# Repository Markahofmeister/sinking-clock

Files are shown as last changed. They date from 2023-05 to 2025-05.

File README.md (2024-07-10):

<Desc.>

#### A full detailing can be found [here](www.markhofmeister.com/sinking-clock) 

## Directory Structure 

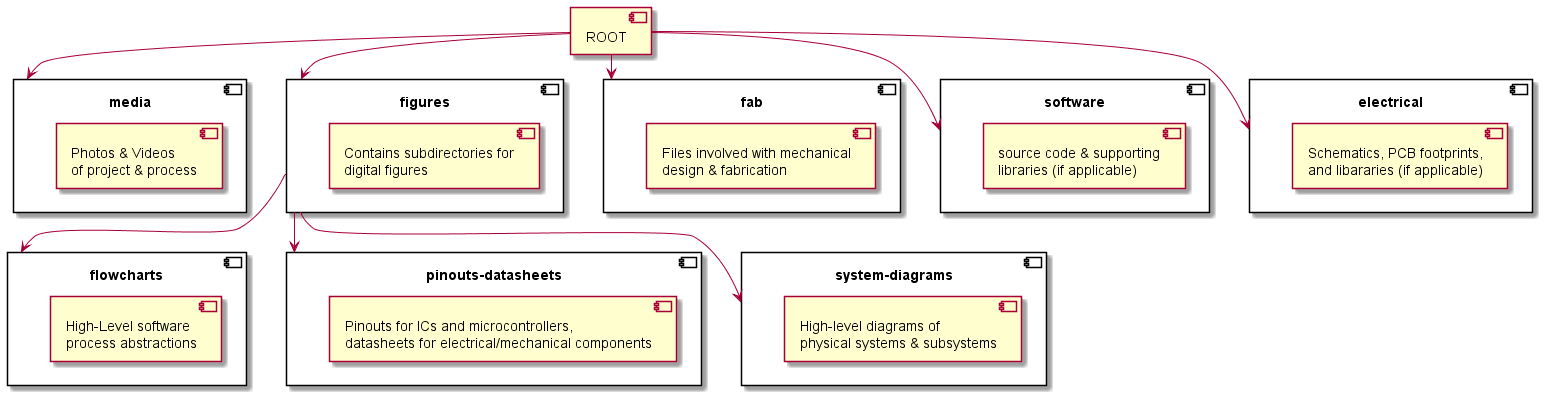
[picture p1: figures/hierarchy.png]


## System Diagram

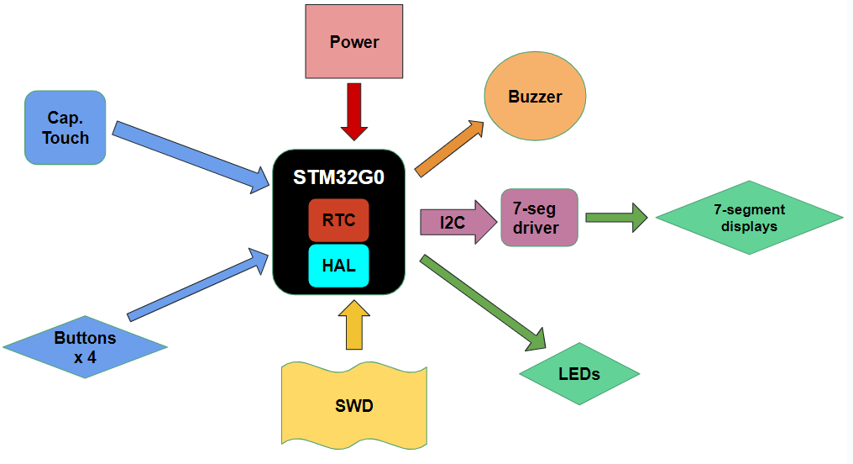
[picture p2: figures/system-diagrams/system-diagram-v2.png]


## Flowcharts
### Main Thread
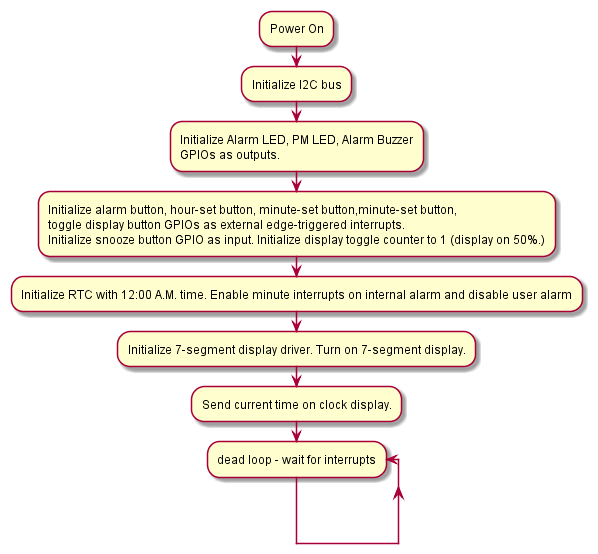
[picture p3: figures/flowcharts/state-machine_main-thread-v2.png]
 
### Interrupts
<!---
<a href="url"><img src="https://github.com/Markahofmeister/sinking-clock/figures/flowcharts/state-machine_RTC-interrupt-v1.png" width=50%></a>
-->
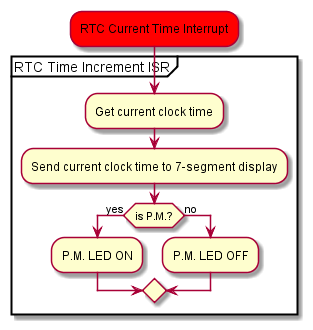
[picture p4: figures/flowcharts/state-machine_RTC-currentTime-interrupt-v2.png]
 
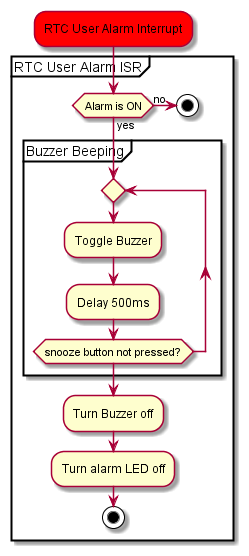
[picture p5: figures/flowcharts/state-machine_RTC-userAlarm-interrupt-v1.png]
 
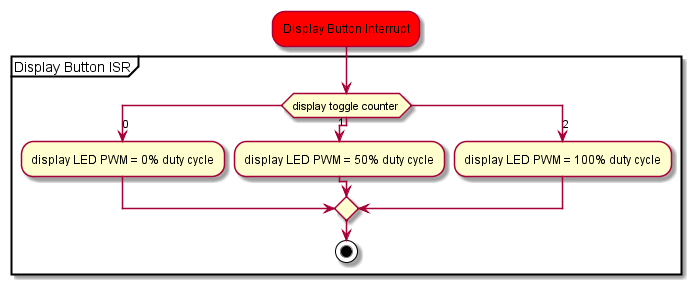
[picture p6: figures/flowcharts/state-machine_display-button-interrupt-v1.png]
 
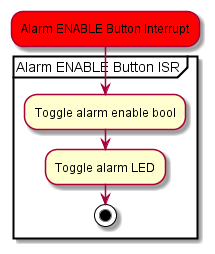
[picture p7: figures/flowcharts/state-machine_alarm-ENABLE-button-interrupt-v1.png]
 
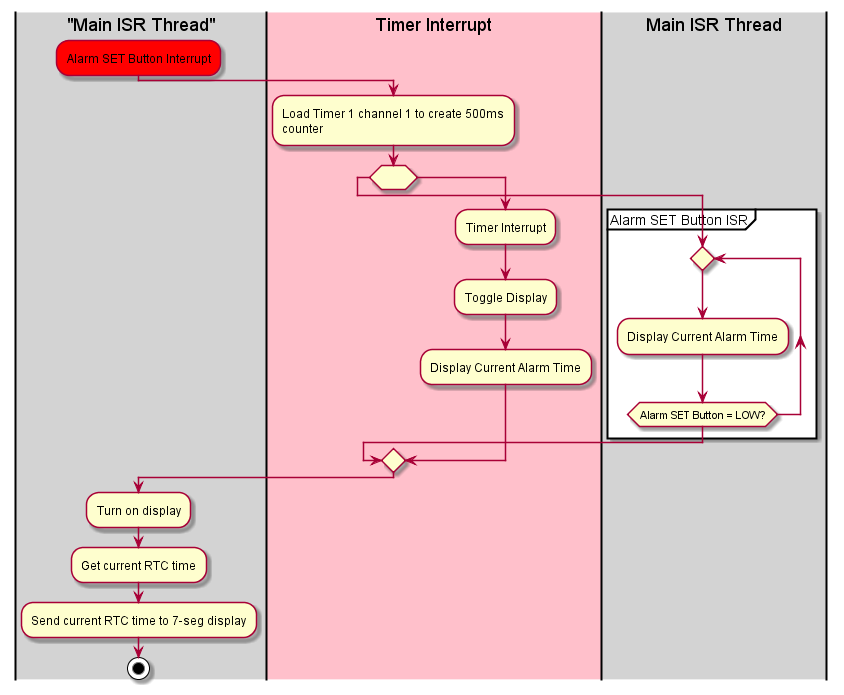
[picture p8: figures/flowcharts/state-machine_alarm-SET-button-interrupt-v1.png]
 
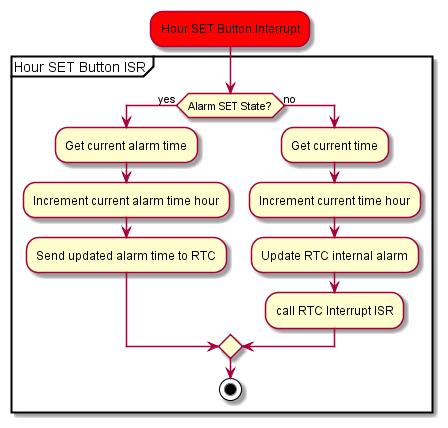
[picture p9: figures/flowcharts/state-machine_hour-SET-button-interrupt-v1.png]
 
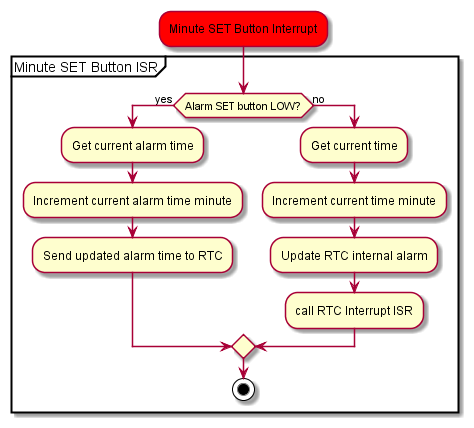
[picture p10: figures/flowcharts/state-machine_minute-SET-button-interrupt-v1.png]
 

## Exploded Mechanical View
	



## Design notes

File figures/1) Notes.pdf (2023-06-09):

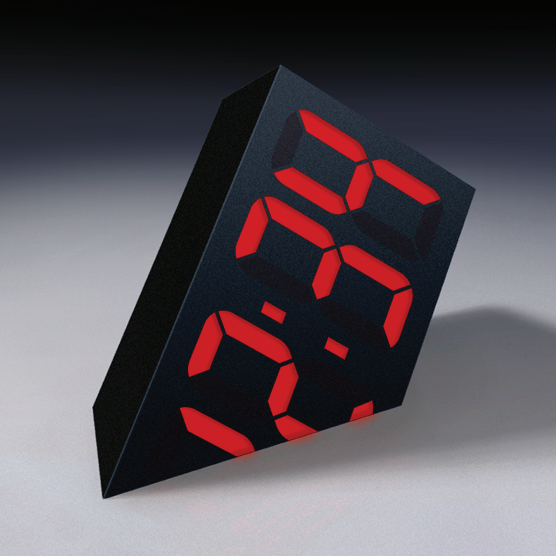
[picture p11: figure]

## SINKING CLOCK Notes

5/18/2023

This is a standard LCD digital alarm clock. The hour digits are severed, but enough is visible to read the time.

Interface
HI/LO/OFF
The LED display can be bright, dim, or o. If this clock sits next to your bed, it would be very irritating to have it on all night long. If set to OFF, the display would come on automatically when the alarm goes o. This is one button. Each time pressed, it cycles through each of these modes.
ALARM
Option 1: One button. Press to turn the alarm on, and o. Hold continuously when using the HOUR and MINUTE buttons to set the alarm time
Option 2: Two buttons. One for alarm on/o. The second button needs to be held down continuously when using the HOUR and MINUTE buttons.
An indicator light on the top of this clock is on when the alarm is activated
HOUR
Press to set the hour digits for the time, and the for the alarm when the alarm set button is held down. MINUTE
Press to set the Minute digits for the time, and the for the alarm when the alarm set button is held down.
SNOOZE
This is a touch sensor, or motion sensor on the top surface of this clock. This should only require a very lite touch to operate. Touch it once quickly to delay the alarm for 10 minutes. The alarm indicator light remains on. Touch it for 3 seconds or more to turn the alarm of. Then, the indicator light will turn o.

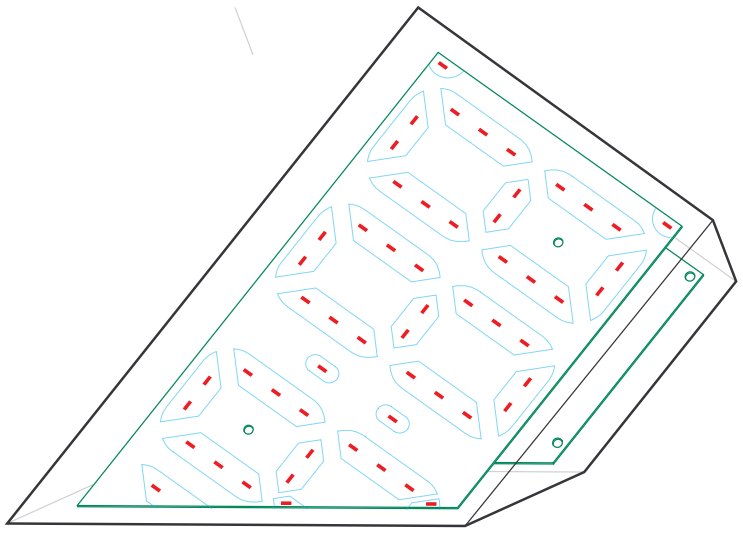
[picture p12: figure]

Power Source
External adapter connected to the backside with a barrel connector jack. This can easily be changed to a 120V or 240V unit depending on what country it will be used in.

Additional Thoughts / Issues
There should be a battery to keep the set time if the power is ever cut. I know this is easy to do, but would this be a battery that is continually charged by the power adapter, or is it a battery that would need to be replaced by the user after it naturally runs down over a few years? I would prefer that it is a battery that never needs replacement, so I don’t need to add a panel for the customer to remove to change batteries. Additionally, lithium batteries are the best, and the most common rechargeable battery, but these make shipping more dicult. There are many regulations and restrictions regarding anything with lithium batteries in it. This needs to be thought through. Some clocks have a wifi connection, so the time is automatically set. Good for the user, but I think this may have issues. The laws regarding any product with wifi is dierent in every country. Therefore, every product needs to be certified to be sold in that market. This would of course be very expensive. If I can not find a way around this, it is probably not realistic.

© K.K. Normal 2023

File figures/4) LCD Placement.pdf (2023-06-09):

## SINKING CLOCK PCB LCD Placement

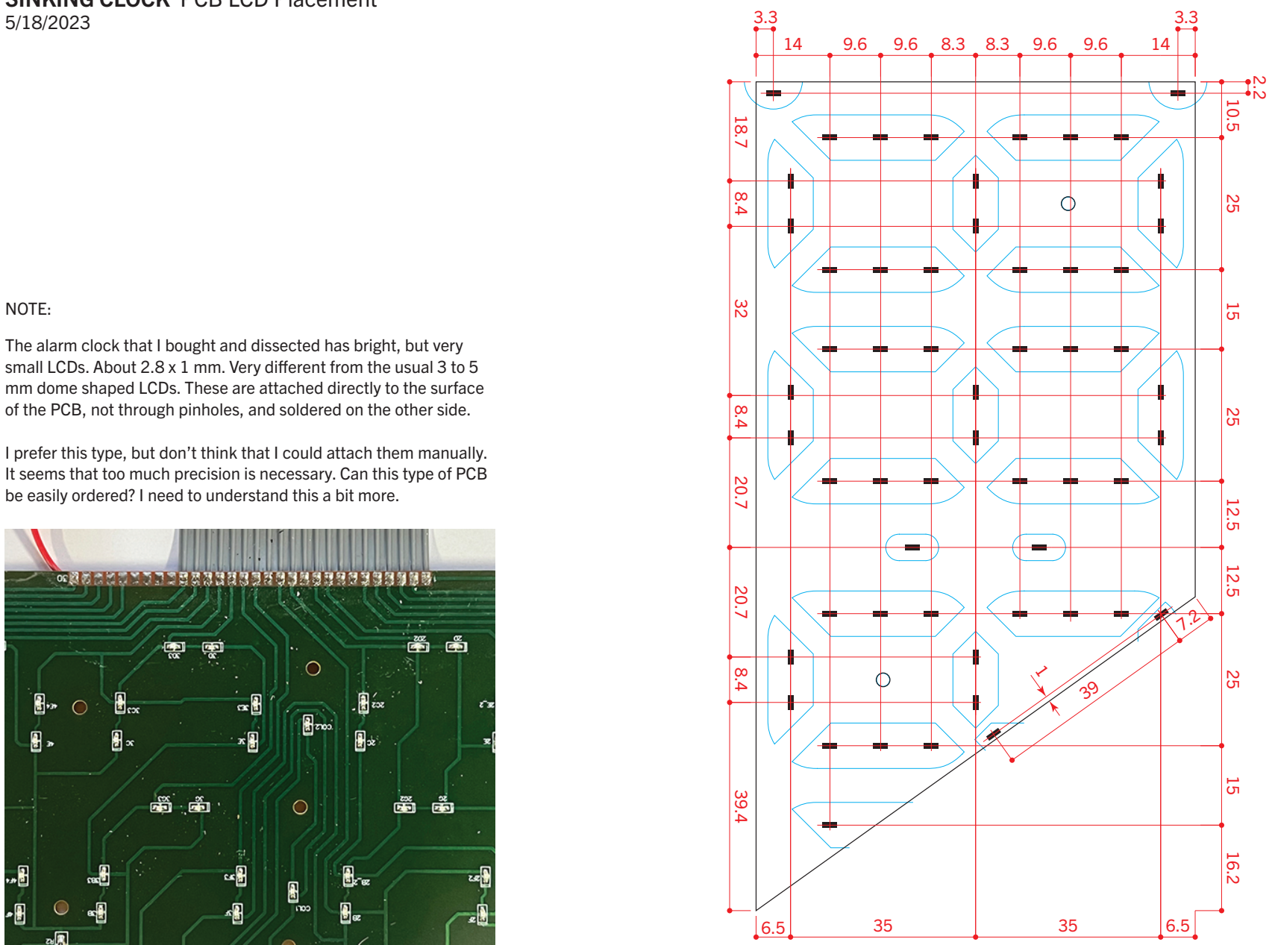
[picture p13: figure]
NOTE:

The alarm clock that I bought and dissected has bright, but very small LCDs. About 2.8 x 1 mm. Very dierent from the usual 3 to 5 mm dome shaped LCDs. These are attached directly to the surface of the PCB, not through pinholes, and soldered on the other side.

I prefer this type, but don’t think that I could attach them manually. It seems that too much precision is necessary. Can this type of PCB be easily ordered? I need to understand this a bit more.

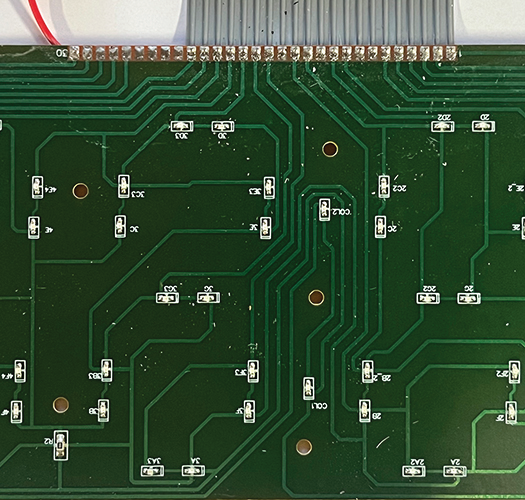
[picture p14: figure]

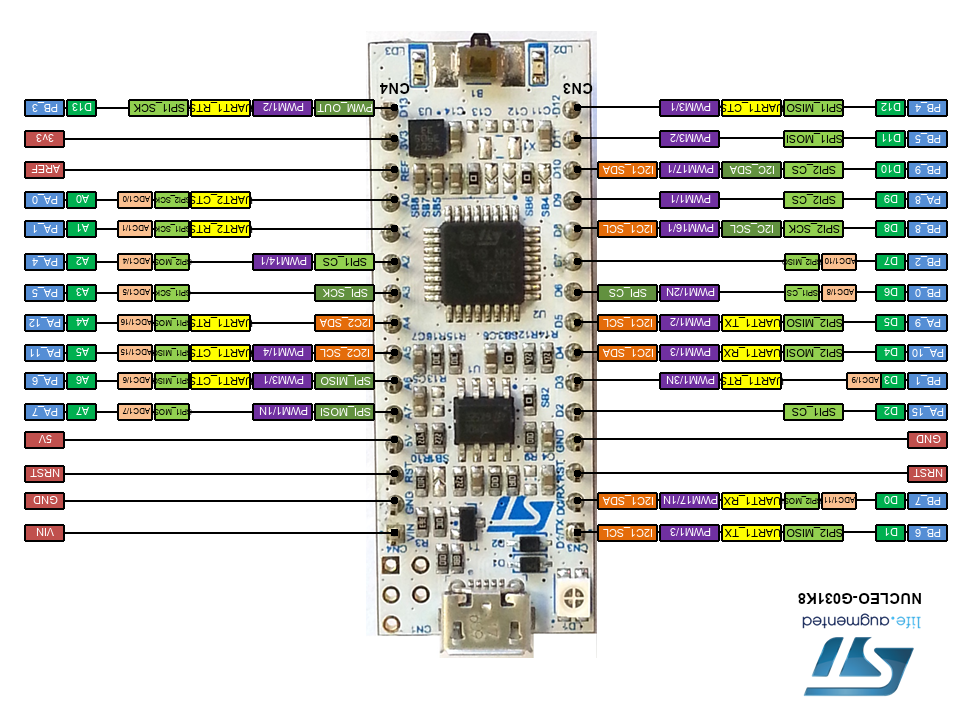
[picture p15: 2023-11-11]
figures/pinouts-datasheets/NUCELO-G032K8_pinout.png

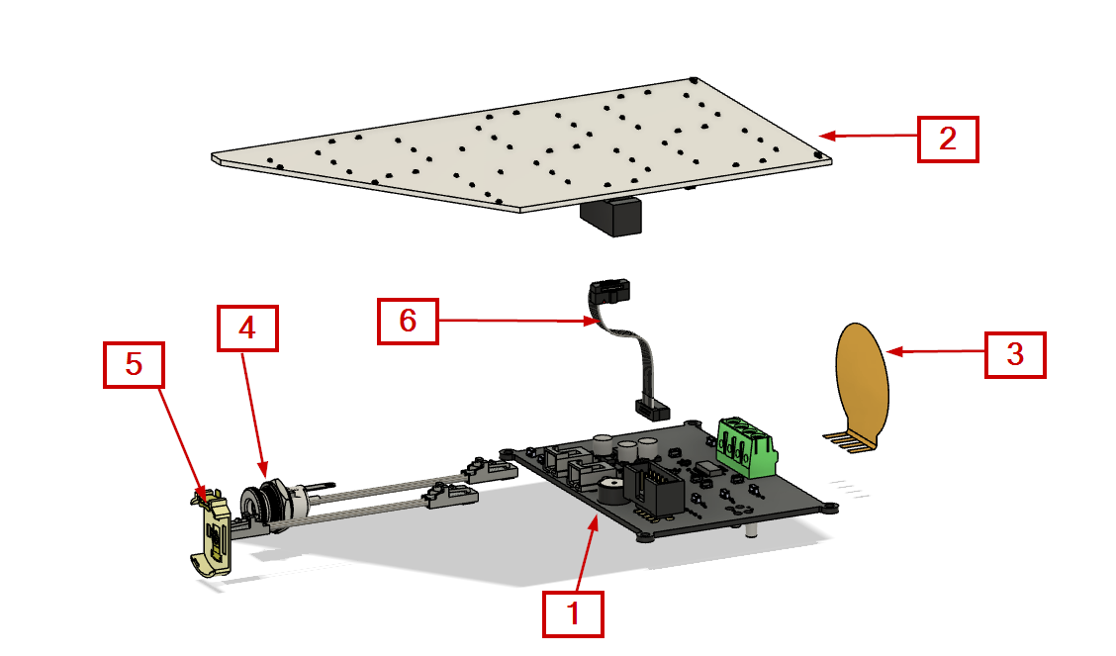
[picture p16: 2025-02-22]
figures/exploded-view.png

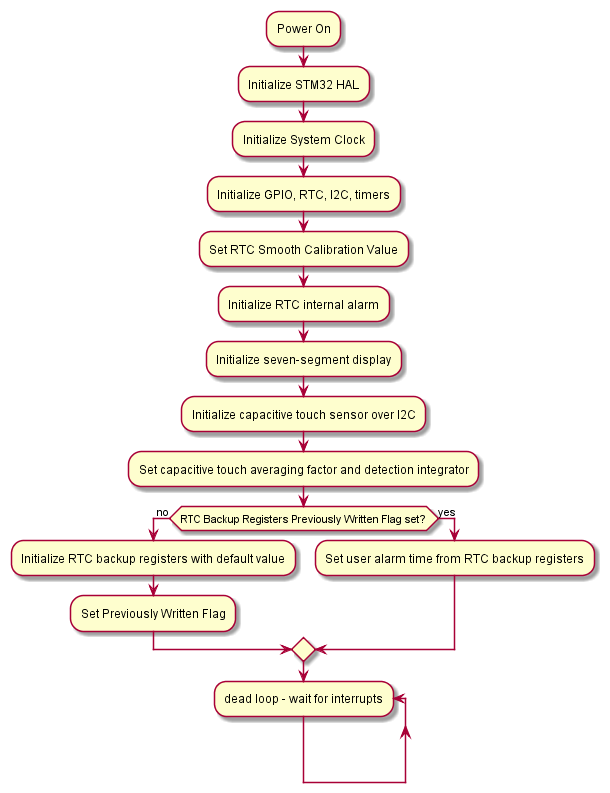
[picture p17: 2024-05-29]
figures/flowcharts/state-machine_main-thread-v3.png

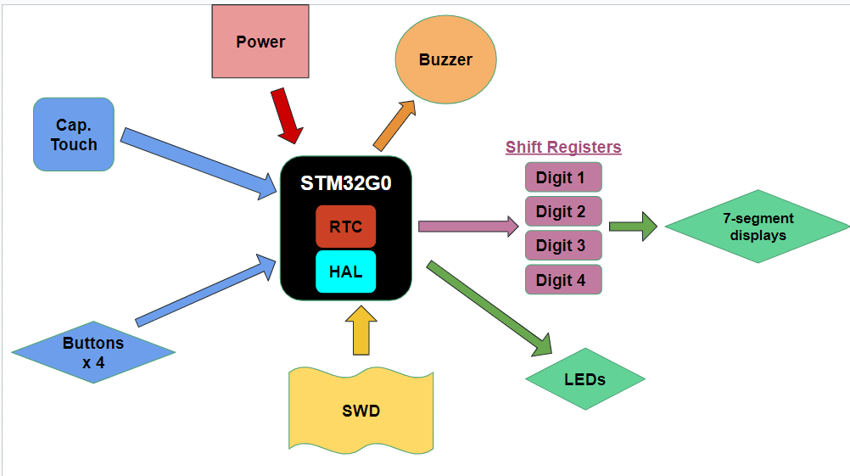
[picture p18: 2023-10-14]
figures/system-diagrams/system-diagram-v3.png

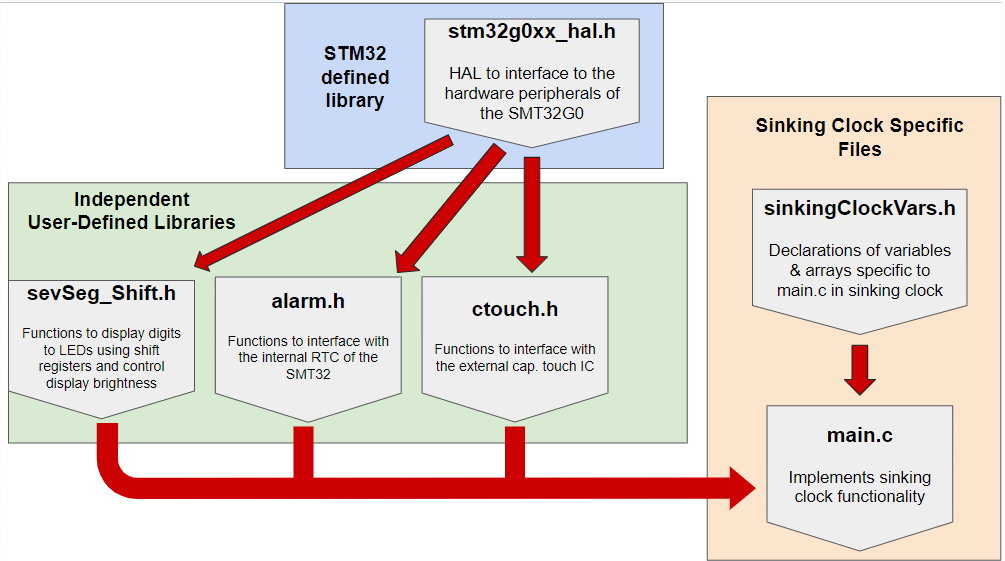
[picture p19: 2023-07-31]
figures/system-diagrams/file-structure-v1.png

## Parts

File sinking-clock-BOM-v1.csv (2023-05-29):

Purchase the "cut tape" option from DigiKey for all items.
 | Item | MFR | MFR P/N | Vendor | Vendor P/N | Quantity | Price | Total Price | Product link | Project Total
 | STM32G0 Nucleo Development Board | STMicroelectronics | NUCLEO-G031K8 | DigiKey | 497-19569-ND | 1 | $10.97 | $10.97 | https://www.digikey.com/en/products/detail/stmicroelectronics/NUCLEO-G031K8/10321671 | $94.54
 | Real-Time Clock (DIP Package) | Microchip Technology | MCP7940N-I/P | DigiKey | MCP7940N-I/P-ND | 3 | $0.92 | $2.76 | https://www.digikey.com/en/products/detail/microchip-technology/MCP7940N-I-P/3872279
 | 32.768 kHz clock (TH package) | ECS Inc. | ECS-.327-8-14X | DigiKey | X1125-ND | 2 | $1.17 | $2.34 | https://www.digikey.com/en/products/detail/ecs-inc/ECS-327-8-14X/827616
 | 22 pF capacitors (TH package) | Vishay Beyschlag/Draloric/BC Components | K220J10C0GF5UH5 | DigiKey | BC5230CT-ND | 4 | $0.23 | $0.92 | https://www.digikey.com/en/products/detail/vishay-beyschlag-draloric-bc-components/K220J10C0GF5UH5/2821614
 | Push buttons (temporary, TH package) | Nidec Components Corporation | TR1-01 | DigiKey | 563-1932-5-ND | 6 | $0.45 | $2.70 | https://www.digikey.com/en/products/detail/nidec-components-corporation/TR1-01/5125294 | $94.54
 | Capacitive touch sensor (SMT package) | Infineon Technologies | CY8CMBR3102-SX1IT | DigiKey | 448-CY8CMBR3102-SX1ITCT-ND | 2 | $2.04 | $4.08 | https://www.digikey.com/en/products/detail/infineon-technologies/CY8CMBR3102-SX1IT/5825528
 | 0.1 uF decoupling capacitors (TH) | Nichicon | UMW1H0R1MDD1TP | DigiKey | 493-10366-1-ND | 4 | $0.38 | $1.52 | https://www.digikey.com/en/products/detail/nichicon/UMW1H0R1MDD1TP/4312365
 | 2.2nF Capacitor (TH) | KEMET | C731U222MZWDAA7317 | DigiKey | 399-C731U222MZWDAA7317CT-ND | 2 | $0.43 | $0.86 | https://www.digikey.com/en/products/detail/kemet/C731U222MZWDAA7317/17838303
 | 8SOIC adapter board | Aries Electronics | LCQT-SOIC8-8 | DigiKey | A880AR-ND | 1 | $3.03 | $3.03 | https://www.digikey.com/en/products/detail/aries-electronics/LCQT-SOIC8-8/4754588
 | Red LEDs - TH | Würth Elektronik | 151031SS04000 | DigiKey | 732-5005-ND | 60 | $0.18 | $10.80 | https://www.digikey.com/en/products/detail/w%C3%BCrth-elektronik/151031SS04000/4489979
 | Buzzer - option 1 | Murata Electronics | PKM22EPPH2001-B0 | DigiKey | 490-4691-ND | 2 | $0.73 | $1.46 | https://www.digikey.com/en/products/detail/murata-electronics/PKM22EPPH2001-B0/1219322
 | Buzzer - option 2 | Murata Electronics | PKM13EPYH4002-B0 | DigiKey | 490-4697-ND | 2 | $0.39 | $0.78 | https://www.digikey.com/en/products/detail/murata-electronics/PKM13EPYH4002-B0/1219328
 | Buzzer - option 3 | CUI Devices | CMI-9605IC-0380T | DigiKey | 2223-CMI-9605IC-0380T-ND | 1 | $1.34 | $1.34 | https://www.digikey.com/en/products/detail/cui-devices/CMI-9605IC-0380T/11674180
 | USB A Male to micro B male cable | Assmann WSW Components | AK67421-0.3-VM | DigiKey | AE11229-ND | 1 | $2.70 | $2.70 | https://www.digikey.com/en/products/detail/assmann-wsw-components/AK67421-0-3-VM/5428793
 | IO Expanding LED Driver - 24 TSSOP | NXP USA Inc. | PCA9532PW,118 | DigiKey | 568-11909-1-ND | 2 | $3.26 | $6.52 | https://www.digikey.com/en/products/detail/nxp-usa-inc/PCA9532PW-118/1157036
 | 120VAC-12VDC adapter | XP Power | ACM18US12 | DigiKey | 1470-3950-ND | 1 | $15.35 | $15.35 | https://www.digikey.com/en/products/detail/xp-power/ACM18US12/6595122
 | Barrel Jack - breadboard adapter | Chip Quik Inc. | CN0020 | DigiKey | CN0020-ND | 1 | $5.29 | $5.29 | https://www.digikey.com/en/products/detail/chip-quik-inc./CN0020/5978267
 | TSSOP to DIP adapter board (28P) | Adafruit Industries LLC | 1208 | DigiKey | 1528-1068-ND | 1 | $4.95 | $4.95 | https://www.digikey.com/en/products/detail/adafruit-industries-llc/1208/5022797
 | 7-seg display driver IC | Analog Devices Inc./Maxim Integrated | MAX6958AAEE+T | DigiKey | MAX6958AAEE+CT-ND | 1 | $11.38 | $11.38 | https://www.digikey.com/en/products/detail/analog-devices-inc-maxim-integrated/MAX6958AAEE-T/1521774
 | QSOP to DIP adapter | Chip Quik Inc. | PA0028 | DigiKey | PA0028-ND | 1 | $4.79 | $4.79 | https://www.digikey.com/en/products/detail/chip-quik-inc/PA0028/5014737
 |  |  |  |  |  |  |  | $0.00
 |  |  |  |  |  |  |  | $0.00
 |  |  |  |  |  |  |  | $0.00
 |  |  |  |  |  |  |  | $0.00
 |  |  |  |  |  |  |  | $0.00
 |  |  |  |  |  |  |  | $0.00
 |  |  |  |  |  |  |  | $0.00
 |  |  |  |  |  |  |  | $0.00
 |  |  |  |  |  |  |  | $0.00
 |  |  |  |  |  |  |  | $0.00
 |  |  |  |  |  |  |  | $0.00
 |  |  |  |  |  |  |  | $0.00
 |  |  |  |  |  |  |  | $0.00
 |  |  |  |  |  |  |  | $0.00
 |  |  |  |  |  |  |  | $0.00
 |  |  |  |  |  |  |  | $0.00
 |  |  |  |  |  |  |  | $0.00
 |  |  |  |  |  |  |  | $0.00
 |  |  |  |  |  |  |  | $0.00
 |  |  |  |  |  |  |  | $0.00
 |  |  |  |  |  |  |  | $0.00
 |  |  |  |  |  |  |  | $0.00
 |  |  |  |  |  |  |  | $0.00
 |  |  |  |  |  |  |  | $0.00
 |  |  |  |  |  |  |  | $0.00
 |  |  |  |  |  |  |  | $0.00
 |  |  |  |  |  |  |  | $0.00
 |  |  |  |  |  |  |  | $0.00
 |  |  |  |  |  |  |  | $0.00
 |  |  |  |  |  |  |  | $0.00
 |  |  |  |  |  |  |  | $0.00
 |  |  |  |  |  |  |  | $0.00
 |  |  |  |  |  |  |  | $0.00
 |  |  |  |  |  |  |  | $0.00
 |  |  |  |  |  |  |  | $0.00
 |  |  |  |  |  |  |  | $0.00
 |  |  |  |  |  |  |  | $0.00
 |  |  |  |  |  |  |  | $0.00
 |  |  |  |  |  |  |  | $0.00
 |  |  |  |  |  |  |  | $0.00
 |  |  |  |  |  |  |  | $0.00
 |  |  |  |  |  |  |  | $0.00
 |  |  |  |  |  |  |  | $0.00
 |  |  |  |  |  |  |  | $0.00
 |  |  |  |  |  |  |  | $0.00
 |  |  |  |  |  |  |  | $0.00
 |  |  |  |  |  |  |  | $0.00
 |  |  |  |  |  |  |  | $0.00
 |  |  |  |  |  |  |  | $0.00
 |  |  |  |  |  |  |  | $0.00
 |  |  |  |  |  |  |  | $0.00
 |  |  |  |  |  |  |  | $0.00
 |  |  |  |  |  |  |  | $0.00
 |  |  |  |  |  |  |  | $0.00
 |  |  |  |  |  |  |  | $0.00
 |  |  |  |  |  |  |  | $0.00
 |  |  |  |  |  |  |  | $0.00
 |  |  |  |  |  |  |  | $0.00
 |  |  |  |  |  |  |  | $0.00
 |  |  |  |  |  |  |  | $0.00
 |  |  |  |  |  |  |  | $0.00
 |  |  |  |  |  |  |  | $0.00
 |  |  |  |  |  |  |  | $0.00
 |  |  |  |  |  |  |  | $0.00
 |  |  |  |  |  |  |  | $0.00
 |  |  |  |  |  |  |  | $0.00
 |  |  |  |  |  |  |  | $0.00
 |  |  |  |  |  |  |  | $0.00
 |  |  |  |  |  |  |  | $0.00
 |  |  |  |  |  |  |  | $0.00
 |  |  |  |  |  |  |  | $0.00
 |  |  |  |  |  |  |  | $0.00
 |  |  |  |  |  |  |  | $0.00
 |  |  |  |  |  |  |  | $0.00
 |  |  |  |  |  |  |  | $0.00
 |  |  |  |  |  |  |  | $0.00
 |  |  |  |  |  |  |  | $0.00
 |  |  |  |  |  |  |  | $0.00
 |  |  |  |  |  |  |  | $0.00

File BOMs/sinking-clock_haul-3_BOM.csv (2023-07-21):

Purchase the "cut tape" option from DigiKey for all items.
 | Item | MFR | MFR P/N | Vendor | Vendor P/N | Quantity | Price | Total Price | Product link | Haul Total
LED PCB Components | Red SMT LED - surface mount, 0603 | Würth Elektronik | 150060RS75000 | DigiKey | 732-4978-1-ND | 168 | $0.14 | $23.86 | https://www.digikey.com/en/products/detail/w%C3%BCrth-elektronik/150060RS75000/4489901 | $153.68
 | Red SMT LEDs - surface mount, right angle, 1206 | Würth Elektronik | 155124RS73200 | DigiKey | 732-5025-1-ND | 6 | $0.20 | $1.20 | https://www.digikey.com/en/products/detail/w%C3%BCrth-elektronik/155124RS73200/4490041
 | Green SMT LEDs - surface mount, 0603 | Dialight | 5988070107F | DigiKey | 350-2035-1-ND | 3 | $0.32 | $0.96 | https://www.digikey.com/en/products/detail/dialight/5988070107F/1291269
 | 8-bit shift Shift Register - 16-TSSOP | Nexperia USA Inc. | 74HC595PW,118 | DigiKey | 1727-3068-1-ND | 12 | $0.47 | $5.64 | https://www.digikey.com/en/products/detail/nexperia-usa-inc/74HC595PW-118/946653
 | Resistor Network - 8-pos, 8.2K | Rohm Semiconductor | MNR18ERAPJ822 | DigiKey | 511-MNR18ERAPJ822CT-ND | 12 | $0.10 | $1.20 | https://www.digikey.com/en/products/detail/rohm-semiconductor/MNR18ERAPJ822/4083449
 | Connector - Male Receptacle, 5x2 pos, 0.1" pitch | CNC Tech | 3020-10-0300-00 | DigiKey | 1175-1621-ND | 3 | $0.68 | $2.04 | https://www.digikey.com/en/products/detail/cnc-tech/3020-10-0300-00/3441727
 | Linear 3.3V Regulator - SOT-223-3 | Diodes Incorporated | AZ1117IH-3.3TRG1 | DigiKey | AZ1117IH-3.3TRG1DICT-ND | 3 | $0.37 | $1.11 | https://www.digikey.com/en/products/detail/diodes-incorporated/AZ1117IH-3-3TRG1/5699672
 | N-channel MOSFET - SOT-23 | Diodes Incorporated | DMN63D8L-7 | DigiKey | DMN63D8L-7DICT-ND | 69 | $0.19 | $13.25 | https://www.digikey.com/en/products/detail/diodes-incorporated/DMN63D8L-7/5699705
 | Capacitor - 10uF, 0402 | Murata Electronics | GRM155R61A106ME11D | DigiKey | 490-GRM155R61A106ME11DCT-ND | 9 | $0.12 | $1.08 | https://www.digikey.com/en/products/detail/murata-electronics/GRM155R61A106ME11D/12091056
 | Capacitor - 1uF, 0402 | Samsung Electro-Mechanics | CL05A105KP5NNNC | DigiKey | 1276-1076-1-ND | 12 | $0.10 | $1.20 | https://www.digikey.com/en/products/detail/samsung-electro-mechanics/CL05A105KP5NNNC/3886734
 | Resistor - 56 ohm, 0402 | YAGEO | RC0402FR-0756RL | DigiKey | 311-56.0LRCT-ND | 15 | $0.10 | $1.50 | https://www.digikey.com/en/products/detail/yageo/RC0402FR-0756RL/726636
 | Resistor - 330 ohm, 0402 | YAGEO | RC0402JR-13330RL | DigiKey | RC0402JR-13330RL | 36 | $0.10 | $3.60 | https://www.digikey.com/en/products/detail/yageo/RC0402JR-13330RL/14008183
 | Resistor - 240 ohm, 0402 | YAGEO | RC0402FR-07240RL | DigiKey | 311-240LRCT-ND | 33 | $0.10 | $3.30 | https://www.digikey.com/en/products/detail/yageo/RC0402FR-07240RL/2827564
 | Resistor - 10k ohm, 0402 | YAGEO | RC0402JR-0710KL | DigiKey | 311-10KJRCT-ND | 4 | $0.10 | $0.40 | https://www.digikey.com/en/products/detail/yageo/RC0402JR-0710KL/726418
 | Test Point - Surface Mount | KOA Speer Electronics, Inc. | RCWCTE | DigiKey | 2019-RCWCTECT-ND | 27 | $0.16 | $4.32 | https://www.digikey.com/en/products/detail/koa-speer-electronics-inc/RCWCTE/11476558
 | STM32 ST-Link V2 In-circuit Debugger | STMicroelectronics | ST-LINK/V2 | DigiKey | 497-10484-ND | 1 | $22.16 | $22.16 | https://www.digikey.com/en/products/detail/stmicroelectronics/ST-LINK-V2/2214535
 | Plug-of-Nails POGO-pin SWD connector | Tag-Connect LLC | TC2030-IDC | DigiKey | TC2030-IDC-ND | 1 | $42.86 | $42.86 | https://www.digikey.com/en/products/detail/tag-connect-llc/TC2030-IDC/4571121
 | ChipQuik Solder Paste | Chip Quik Inc. | SMD291AX10 | DigiKey | SMD291AX10-ND | 1 | $20.95 | $20.95 | https://www.digikey.com/en/products/detail/chip-quik-inc/SMD291AX10/2057271
 | Tactile push button Switch - option 1: 3.8mm | E-Switch | TL3305AF260QG |  | EG5353CT-ND | 2 | $0.21 | $0.42 | https://www.digikey.com/en/products/detail/e-switch/TL3305AF260QG/5816184
 | Tactile push button Switch - option 2: 8.5mm | E-Switch | TL3301PF160QG |  | EG4562CT-ND | 2 | $0.43 | $0.86 | https://www.digikey.com/en/products/detail/e-switch/TL3301PF160QG/1756542
 | Tactile push button Switch - option 3: 9.5mm | E-Switch | TL3301BF160QGTUBE |  | 141-TL3301BF160QGTUBE-ND | 2 | $0.43 | $0.86 | https://www.digikey.com/en/products/detail/e-switch/TL3301BF160QGTUBE/1805543
 | Tactile push button Switch - option 4: 13.0mm | E-Switch | TL3301DF160QG |  | EG5463CT-ND | 2 | $0.46 | $0.92 | https://www.digikey.com/en/products/detail/e-switch/TL3301DF160QG/1805555
 |  |  |  |  |  |  |  | $0.00
 |  |  |  |  |  |  |  | $0.00
 |  |  |  |  |  |  |  | $0.00
 |  |  |  |  |  |  |  | $0.00
 |  |  |  |  |  |  |  | $0.00
 |  |  |  |  |  |  |  | $0.00
 |  |  |  |  |  |  |  | $0.00
 |  |  |  |  |  |  |  | $0.00
 |  |  |  |  |  |  |  | $0.00
 |  |  |  |  |  |  |  | $0.00
 |  |  |  |  |  |  |  | $0.00
 |  |  |  |  |  |  |  | $0.00
 |  |  |  |  |  |  |  | $0.00
 |  |  |  |  |  |  |  | $0.00
 |  |  |  |  |  |  |  | $0.00
 |  |  |  |  |  |  |  | $0.00
 |  |  |  |  |  |  |  | $0.00
 |  |  |  |  |  |  |  | $0.00
 |  |  |  |  |  |  |  | $0.00
 |  |  |  |  |  |  |  | $0.00
 |  |  |  |  |  |  |  | $0.00
 |  |  |  |  |  |  |  | $0.00
 |  |  |  |  |  |  |  | $0.00
 |  |  |  |  |  |  |  | $0.00
 |  |  |  |  |  |  |  | $0.00
 |  |  |  |  |  |  |  | $0.00
 |  |  |  |  |  |  |  | $0.00
 |  |  |  |  |  |  |  | $0.00
 |  |  |  |  |  |  |  | $0.00
 |  |  |  |  |  |  |  | $0.00
 |  |  |  |  |  |  |  | $0.00
 |  |  |  |  |  |  |  | $0.00
 |  |  |  |  |  |  |  | $0.00
 |  |  |  |  |  |  |  | $0.00
 |  |  |  |  |  |  |  | $0.00
 |  |  |  |  |  |  |  | $0.00
 |  |  |  |  |  |  |  | $0.00
 |  |  |  |  |  |  |  | $0.00
 |  |  |  |  |  |  |  | $0.00
 |  |  |  |  |  |  |  | $0.00
 |  |  |  |  |  |  |  | $0.00
 |  |  |  |  |  |  |  | $0.00
 |  |  |  |  |  |  |  | $0.00
 |  |  |  |  |  |  |  | $0.00
 |  |  |  |  |  |  |  | $0.00
 |  |  |  |  |  |  |  | $0.00
 |  |  |  |  |  |  |  | $0.00
 |  |  |  |  |  |  |  | $0.00
 |  |  |  |  |  |  |  | $0.00
 |  |  |  |  |  |  |  | $0.00
 |  |  |  |  |  |  |  | $0.00
 |  |  |  |  |  |  |  | $0.00
 |  |  |  |  |  |  |  | $0.00
 |  |  |  |  |  |  |  | $0.00
 |  |  |  |  |  |  |  | $0.00
 |  |  |  |  |  |  |  | $0.00
 |  |  |  |  |  |  |  | $0.00
 |  |  |  |  |  |  |  | $0.00
 |  |  |  |  |  |  |  | $0.00
 |  |  |  |  |  |  |  | $0.00
 |  |  |  |  |  |  |  | $0.00
 |  |  |  |  |  |  |  | $0.00
 |  |  |  |  |  |  |  | $0.00
 |  |  |  |  |  |  |  | $0.00
 |  |  |  |  |  |  |  | $0.00
 |  |  |  |  |  |  |  | $0.00
 |  |  |  |  |  |  |  | $0.00
 |  |  |  |  |  |  |  | $0.00
 |  |  |  |  |  |  |  | $0.00
 |  |  |  |  |  |  |  | $0.00
 |  |  |  |  |  |  |  | $0.00
 |  |  |  |  |  |  |  | $0.00
 |  |  |  |  |  |  |  | $0.00
 |  |  |  |  |  |  |  | $0.00
 |  |  |  |  |  |  |  | $0.00
 |  |  |  |  |  |  |  | $0.00
 |  |  |  |  |  |  |  | $0.00
 |  |  |  |  |  |  |  | $0.00

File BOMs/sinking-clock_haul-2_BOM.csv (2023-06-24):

Purchase the "cut tape" option from DigiKey for all items.
 | Item | MFR | MFR P/N | Vendor | Vendor P/N | Quantity | Price | Total Price | Product link | Haul Total
 | Capacitive Touch Sensor | Azoteq (Pty) Ltd | IQS228B-00000000-TSR | DigiKey | 1790-IQS228B-00000000-TSRCT-ND | 3 | $0.24 | $0.72 | https://www.digikey.com/en/products/detail/azoteq-pty-ltd/IQS228B-00000000-TSR/13663616 | $87.44
 | TSOT3-6 to DIP-6 Adapter Board | Chip Quik Inc. | PA0085 | DigiKey | PA0085-ND | 1 | $2.69 | $2.69 | https://www.digikey.com/en/products/detail/chip-quik-inc./PA0085/5014712
 | Boost Converter Module | SparkFun Electronics | COM-15208 | DigiKey | 1568-COM-15208-ND | 1 | $11.56 | $11.56 | https://www.digikey.com/en/products/detail/sparkfun-electronics/COM-15208/10187090
 | Adafruit LiPo Battery - Cylindrical 2.2AH | Adafruit Inductries LLC | 1781 | DigiKey | 1528-1836-ND | 1 | $9.95 | $9.95 | https://www.digikey.com/en/products/detail/adafruit-industries-llc/1781/5054543
 | Adafruit LiPo Battery - Rectangular 1.2AH | Adafruit Inductries LLC | 258 | DigiKey | 1528-1838-ND | 1 | $9.95 | $9.95 | https://www.digikey.com/en/products/detail/adafruit-industries-llc/258/5054544
 | Adafruit LiPo Battery Adapter Board | Adafruit Inductries LLC | 1863 | DigiKey | 1528-1862-ND | 1 | $2.50 | $2.50 | https://www.digikey.com/en/products/detail/adafruit-industries-llc/1863/6565368
 | Adafruit USB LiPoly Charger | Adafruit Inductries LLC | 1304 | DigiKey | 1528-1865-ND | 1 | $5.95 | $5.95 | https://www.digikey.com/en/products/detail/adafruit-industries-llc/1304/6618716
 | Connector Option 1 - Cable Assembly | 3M | D89110-0131HK-3365/10-D-3 | DigiKey | 3M156030-MC10G-3M156030-3-ND | 1 | $3.03 | $3.03 | https://www.digikey.com/en/products/detail/3m/D89110-0131HK-3365-10-D-3/6024550
 | Connector Option 1 - Male Receptacle | 3M | 30310-6002HB | DigiKey | 30310-6002HB-ND | 2 | $0.75 | $1.50 | https://www.digikey.com/en/products/detail/3m/30310-6002HB/1237393
 | Connector Option 2 - Cable Assembly 1 | TE Connectivity | A3AAH-1006G | DigiKey | A3AAH-1006G-ND | 1 | $2.53 | $2.53 | https://www.digikey.com/en/products/detail/te-connectivity-amp-connectors/A3AAH-1006G/825887
 | Connector Option 2 - Cable Assembly 2 | TE Connectivity | A3CCH-1018G | DigiKey | A3CCH-1018G-ND | 1 | $2.92 | $2.92 | https://www.digikey.com/en/products/detail/te-connectivity-amp-connectors/A3CCH-1018G/826027
 | Connector Option 2 - Male Receptacle | TE Connectivity | 1761681-3 | DigiKey | 1761681-3-ND | 2 | $1.65 | $3.30 | https://www.digikey.com/en/products/detail/te-connectivity-amp-connectors/1761681-3/2055463
 | Backup Battery Supervisor IC | Analog Devices | MAX6326UR26+T | DigiKey | MAX6326UR26+TCT-ND | 1 | $4.82 | $4.82 | https://www.digikey.com/en/products/detail/analog-devices-inc-maxim-integrated/MAX6326UR26-T/1495696
 | Battery Monitor IC Adapter Board (SOT-23-3) | SparkFun Electronics | BOB-00717 | DigiKey | 1568-1098-ND | 1 | $1.05 | $1.05 | https://www.digikey.com/en/products/detail/sparkfun-electronics/BOB-00717/5318740
 | Battery Charger IC | Analog Devices | LTC4075EDD#PBF | DigiKey | LTC4075EDD#PBF-ND | 2 | $6.61 | $13.22 | https://www.digikey.com/en/products/detail/analog-devices-inc/LTC4075EDD-PBF/951407
 | Battery Charger IC Adapter Board (DFN-10) | Chip Quik Inc. | IPC0067 | DigiKey | IPC0067-ND | 1 | $5.79 | $5.79 | https://www.digikey.com/en/products/detail/chip-quik-inc./IPC0067/5014734
 | 909 ohm resistors, TH | Stackpole Electronics Inc | CF14JT910R | DigiKey | CF14JT910RCT-ND | 10 | $0.06 | $0.56 | https://www.digikey.com/en/products/detail/stackpole-electronics-inc/CF14JT910R/1741527
 | 5.1k resistors, TH | Stackpole Electronics Inc | CF18JT5K10 | DigiKey | CF18JT5K10CT-ND | 10 | $0.05 | $0.45 | https://www.digikey.com/en/products/detail/stackpole-electronics-inc/CF18JT5K10/1741724
 | Male Header pin row, 0.1" pitch, 36 pos 10 pk | Adafruit Inductries LLC | 4149 | DigiKey | 1528-2921-ND | 1 | $4.95 | $4.95 | https://www.digikey.com/en/products/detail/adafruit-industries-llc/4149/10123800
 |  |  |  |  |  |  |  | $0.00
 |  |  |  |  |  |  |  | $0.00
 |  |  |  |  |  |  |  | $0.00
 |  |  |  |  |  |  |  | $0.00
 |  |  |  |  |  |  |  | $0.00
 |  |  |  |  |  |  |  | $0.00
 |  |  |  |  |  |  |  | $0.00
 |  |  |  |  |  |  |  | $0.00
 |  |  |  |  |  |  |  | $0.00
 |  |  |  |  |  |  |  | $0.00
 |  |  |  |  |  |  |  | $0.00
 |  |  |  |  |  |  |  | $0.00
 |  |  |  |  |  |  |  | $0.00
 |  |  |  |  |  |  |  | $0.00
 |  |  |  |  |  |  |  | $0.00
 |  |  |  |  |  |  |  | $0.00
 |  |  |  |  |  |  |  | $0.00
 |  |  |  |  |  |  |  | $0.00
 |  |  |  |  |  |  |  | $0.00
 |  |  |  |  |  |  |  | $0.00
 |  |  |  |  |  |  |  | $0.00
 |  |  |  |  |  |  |  | $0.00
 |  |  |  |  |  |  |  | $0.00
 |  |  |  |  |  |  |  | $0.00
 |  |  |  |  |  |  |  | $0.00
 |  |  |  |  |  |  |  | $0.00
 |  |  |  |  |  |  |  | $0.00
 |  |  |  |  |  |  |  | $0.00
 |  |  |  |  |  |  |  | $0.00
 |  |  |  |  |  |  |  | $0.00
 |  |  |  |  |  |  |  | $0.00
 |  |  |  |  |  |  |  | $0.00
 |  |  |  |  |  |  |  | $0.00
 |  |  |  |  |  |  |  | $0.00
 |  |  |  |  |  |  |  | $0.00
 |  |  |  |  |  |  |  | $0.00
 |  |  |  |  |  |  |  | $0.00
 |  |  |  |  |  |  |  | $0.00
 |  |  |  |  |  |  |  | $0.00
 |  |  |  |  |  |  |  | $0.00
 |  |  |  |  |  |  |  | $0.00
 |  |  |  |  |  |  |  | $0.00
 |  |  |  |  |  |  |  | $0.00
 |  |  |  |  |  |  |  | $0.00
 |  |  |  |  |  |  |  | $0.00
 |  |  |  |  |  |  |  | $0.00
 |  |  |  |  |  |  |  | $0.00
 |  |  |  |  |  |  |  | $0.00
 |  |  |  |  |  |  |  | $0.00
 |  |  |  |  |  |  |  | $0.00
 |  |  |  |  |  |  |  | $0.00
 |  |  |  |  |  |  |  | $0.00
 |  |  |  |  |  |  |  | $0.00
 |  |  |  |  |  |  |  | $0.00
 |  |  |  |  |  |  |  | $0.00
 |  |  |  |  |  |  |  | $0.00
 |  |  |  |  |  |  |  | $0.00
 |  |  |  |  |  |  |  | $0.00
 |  |  |  |  |  |  |  | $0.00
 |  |  |  |  |  |  |  | $0.00
 |  |  |  |  |  |  |  | $0.00
 |  |  |  |  |  |  |  | $0.00
 |  |  |  |  |  |  |  | $0.00
 |  |  |  |  |  |  |  | $0.00
 |  |  |  |  |  |  |  | $0.00
 |  |  |  |  |  |  |  | $0.00
 |  |  |  |  |  |  |  | $0.00
 |  |  |  |  |  |  |  | $0.00
 |  |  |  |  |  |  |  | $0.00
 |  |  |  |  |  |  |  | $0.00
 |  |  |  |  |  |  |  | $0.00
 |  |  |  |  |  |  |  | $0.00
 |  |  |  |  |  |  |  | $0.00
 |  |  |  |  |  |  |  | $0.00
 |  |  |  |  |  |  |  | $0.00
 |  |  |  |  |  |  |  | $0.00
 |  |  |  |  |  |  |  | $0.00
 |  |  |  |  |  |  |  | $0.00
 |  |  |  |  |  |  |  | $0.00
 |  |  |  |  |  |  |  | $0.00
 |  |  |  |  |  |  |  | $0.00
 |  |  |  |  |  |  |  | $0.00

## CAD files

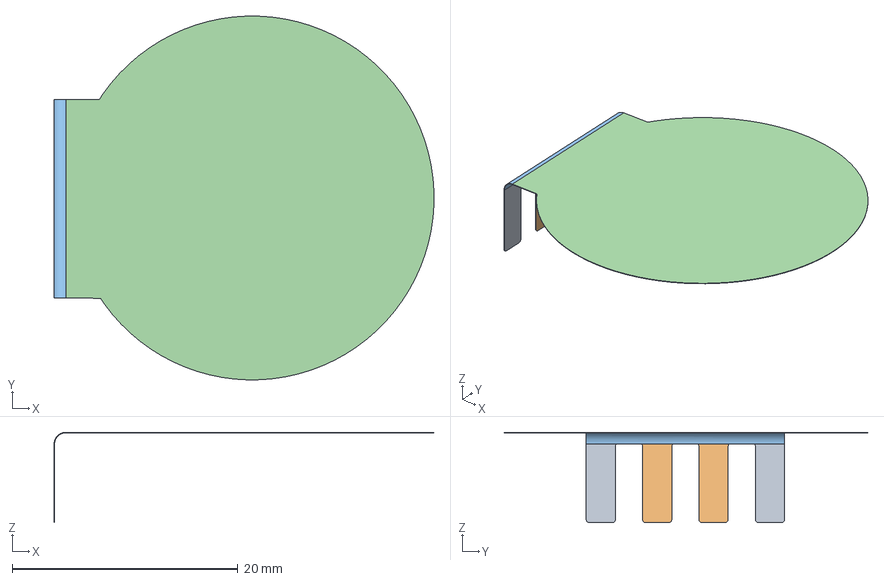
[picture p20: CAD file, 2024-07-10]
electrical/sinking-clock_Flex-PCB/sinking-clock_Flex-PCB_Mk-II.step
33.7 x 32.3 x 8.01 mm

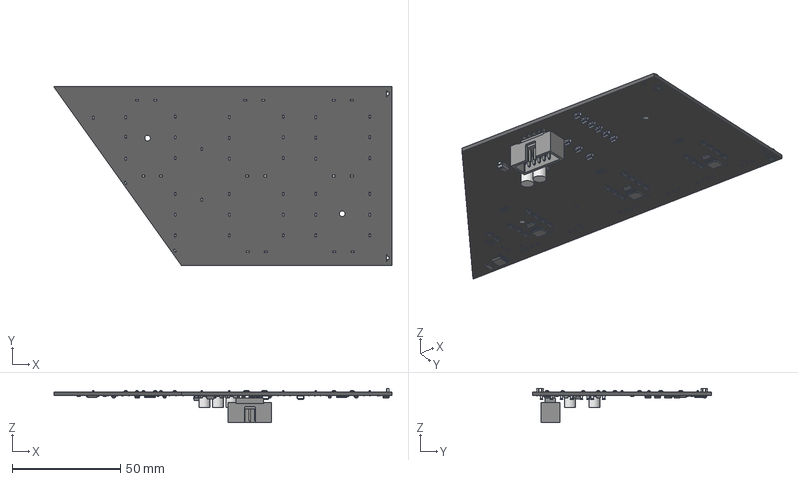
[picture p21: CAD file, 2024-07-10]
electrical/sinking-clock_LED-PCB/Mk-III/sinking-clock_LED-PCB_Mk-III.step
156.4 x 83.0 x 15.7 mm
GS1M-LTP
Pins x 4
Resistor 0402 x 32
72454-010LF v2
C0402 x 4
mark x 4
LTST-C230KRKT x 2

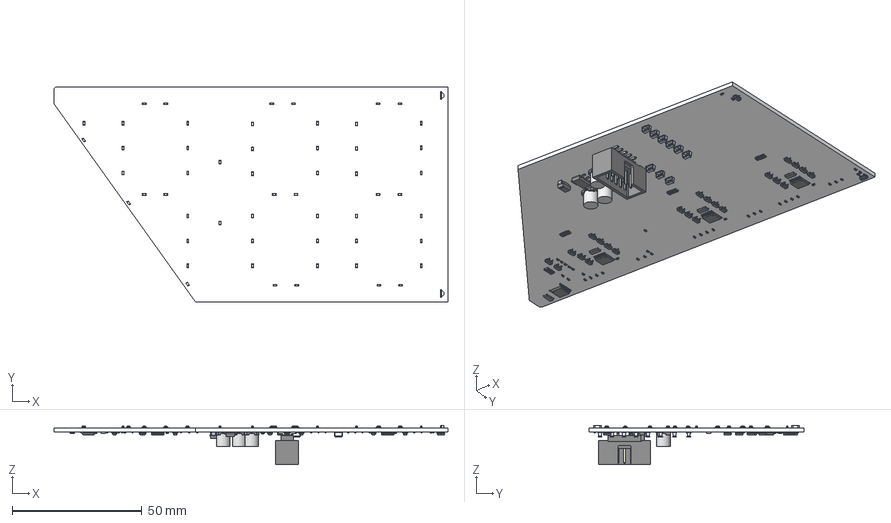
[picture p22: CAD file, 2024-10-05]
electrical/sinking-clock_LED-PCB/Mk-V/sinking-clock_LED-PCB_Mk-V-0.1.step
152.0 x 83.0 x 15.2 mm
Resistor 0402 x 37
GS1M-LTP
Pins x 4
72454-010LF v2
C0402 x 4
mark x 4
contact-pins x 8
PCB x 2
glass housing x 2

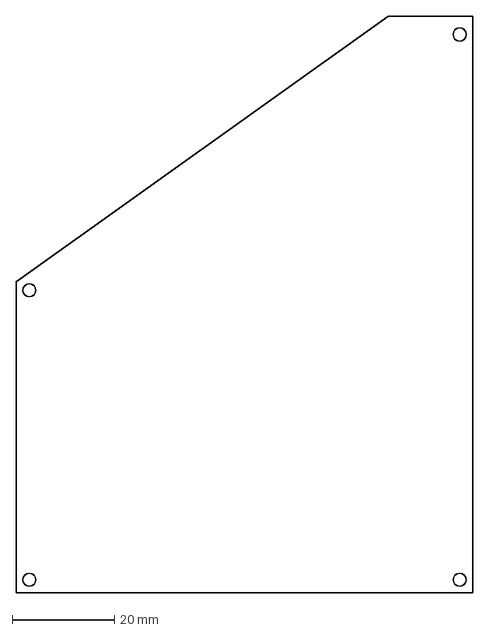
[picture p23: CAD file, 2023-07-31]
fab/brain-pcb_dims.dxf
89.1 x 112.5 mm

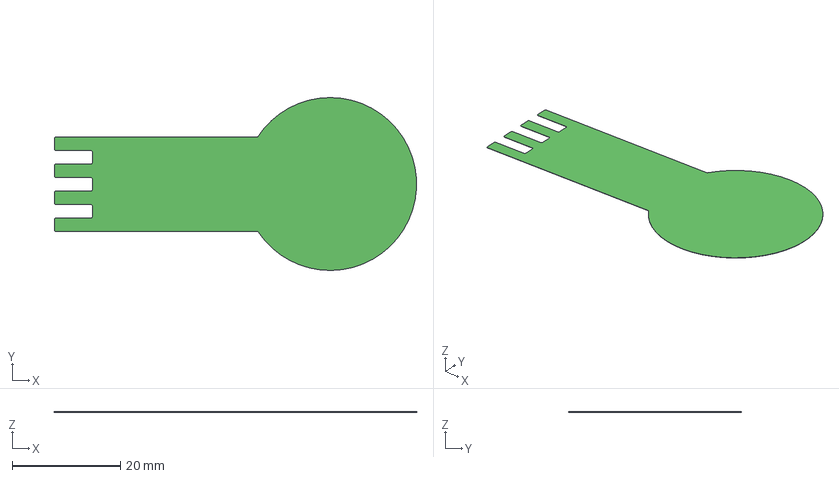
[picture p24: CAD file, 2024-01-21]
electrical/sinking-clock_Flex-PCB/sinking-clock_Flex-PCB.step
67.0 x 32.0 x 0.051 mm

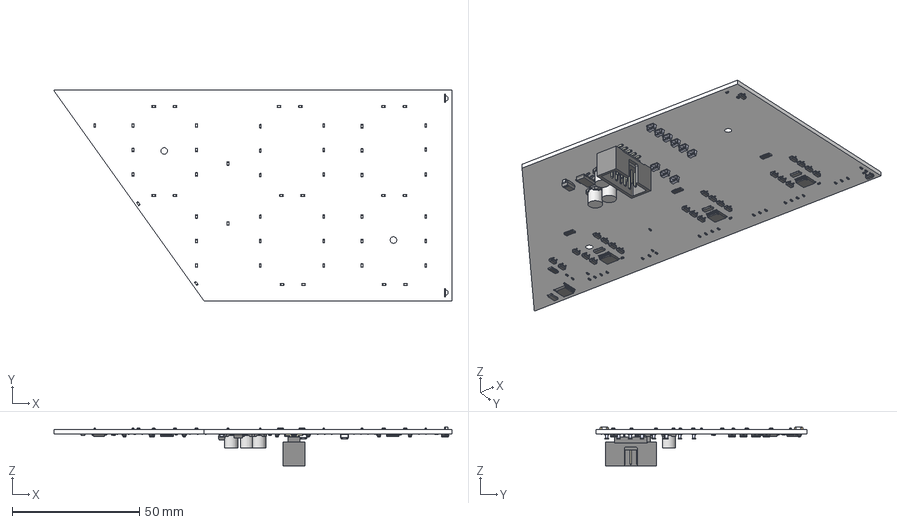
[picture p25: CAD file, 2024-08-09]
electrical/sinking-clock_LED-PCB/Mk-V/sinking-clock_LED-PCB_Mk-IV.step
156.4 x 83.0 x 15.2 mm
GS1M-LTP
Pins x 4
Resistor 0402 x 32
72454-010LF v2
C0402 x 4
mark x 4
contact-pins x 8
PCB x 2
glass housing x 2

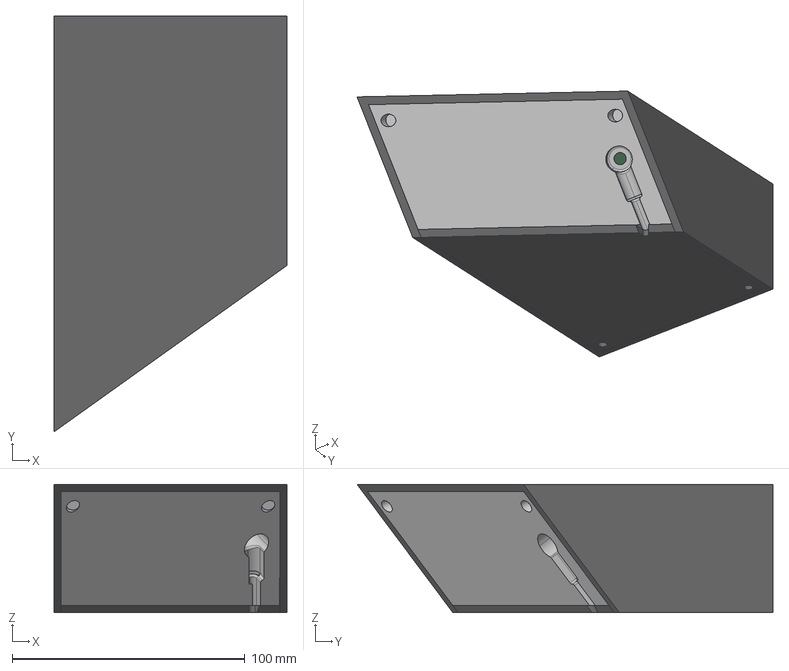
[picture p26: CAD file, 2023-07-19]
fab/Sinking Clock.stp
100.0 x 178.5 x 55.0 mm

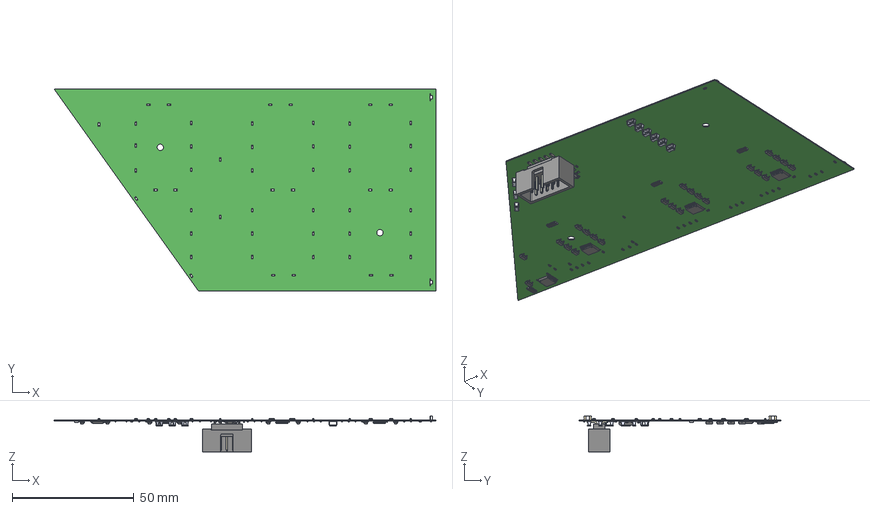
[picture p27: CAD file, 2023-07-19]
fab/sinking-clock_LED-PCB_Mk-I.step
156.7 x 83.0 x 14.6 mm
72454-010LF v2
Resistor 0402 x 31
C0402 x 7
mark x 4
LTST-C230KRKT x 2

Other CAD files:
electrical/sinking-clock_LED-PCB/sinking-clock_LED-PCB_Mk-VII.step
electrical/sinking-clock_LED-PCB/sinking-clock_LED-PCB_Mk-VI.step

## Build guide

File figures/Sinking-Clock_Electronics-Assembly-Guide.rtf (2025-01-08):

Sinking Clock – Electronics Assembly Guide
Mark Hofmeister
HofLab
Mk. 0.1

Contents

Purpose
This electronics assembly guide details descriptions, recommendations, and precautions for handling and assembling the electronic components of Sinking Clock.
This Electronics Assembly Guide pertains to the following revisions of the PCBAs in Sinking Clock:
• Sinking Clock: Brain PCB – Mk. VI
• Sinking Clock: LED PCB – Mk. IV
• Sinking Clock: Flex PCB – Mk. III

The author of this document assumes no responsibility or liability for any errors, omissions, or outcomes resulting from assembling the electronic components of Sinking Clock. Reader(s) are solely responsible for verifying the accuracy, applicability, and suitability of the information for their intended use. By using this document, the reader agrees to assume full responsibility for any risks associated with the application of the provided information.

Full Electronics Assembly – Exploded View
S
Full Electronics Assembly – Bill of Materials

Barrel Jack Connector Cable Sub-Assembly – Bill of Materials

Coin Cell Battery Cable Sub-Assembly – Bill of Materials

General Precautions
- Be careful putting the LED PCB in. Mention intermittent failures and LEDs.
- Hot glue on all connectors (except clasping)
- Never hot-plug
- No excessive force, especially on touch sensors
- ESD
- Don’t plug 12V into barrel jack
- If needed, push in the barrel jack spring

Recommended Assembly Steps
1. Pre-Enclosure PCB test
2. Mounting LED PCB to Enclosure
3. Connecting Touch Electrode to Brain PCB
4. Applying Double-Sided Tape to Inner Enclosure Surface
5. Connecting + Gluing IDC Cable to Brain PCB
6. Mounting Brain PCB + Touch Electrode to Enclosure
7. Connecting + Gluing the IDC Cable to the LED PCB
8. Connecting the Barrel Jack to the Enclosure
9. Connecting the Barrel Jack to the Brain PCB
10. (Optional) Connecting the Coin Cell Harness to the Enclosure
11. (Optional) Connecting the Coin Cell Harness to the Brain PCB
12. Final Test in Enclosure

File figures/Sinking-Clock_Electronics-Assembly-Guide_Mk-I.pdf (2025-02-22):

# Sinking Clock – Electronics Assembly Guide

Mark Hofmeister

HofLab

Mk. 0.1

# Purpose

This electronics assembly guide details descriptions, recommendations, and precautions for handling and assembling the electronic components of Sinking Clock.
This Electronics Assembly Guide pertains to the following revisions of the PCBAs in Sinking Clock:
- Sinking Clock: Brain PCB – Mk. IV
- Sinking Clock: LED PCB – Mk. VI
- Sinking Clock: Flex PCB – Mk. III

The author of this document assumes no responsibility or liability for any errors, omissions, or outcomes resulting from assembling the electronic components of Sinking Clock. Reader(s) are solely responsible for verifying the accuracy, applicability, and suitability of the information for their intended use. By using this document, the reader agrees to assume full responsibility for any risks associated with the application of the provided information.

# Full Electronics Assembly – Exploded View


# Full Electronics Assembly – Bill of Materials

Drawing Item

Number | Item Description | Item Manufacturer Manufacturer Part
| | | Number | QTY
1 | Sinking Clock - Brain PCB, Mk. IV | PCBWay | W665653AS1N49,
| | | T-1N50W665653A | 1
2 | Sinking Clock - LED PCB, Mk. VI | PCBWay | W665653AS1N47 ,
| | | T-1N48W665653A | 1
3 | Sinking Clock - Flex PCB, Mk. III | PCBWay | W665653AS1N46 | 1
4 | Barrel Jack Connector Cable
| Assembly | - | - | 1
5 | Coin Cell Battery Cable Assembly | - | - | 1
6 | Brain PCB to LED PCB IDC Cable | Assmann WSW
| | Components | H3DDH-1006G | 1

## Barrel Jack Connector Cable Sub-Assembly – Bill of Materials

4a | CL Positive Lock Socket to Individual
| Wire Leads, 2 pos, 150mm | Molex | 2162711022 | 1
4b | Power Barrel Jack, 2.5mm ID x
| 5.5mm OD, Chassis Mount | Memory Protection
| | Devices | EJ501B | 1

## Coin Cell Battery Cable Sub-Assembly – Bill of Materials

Subassembly
Component | Item Description | Item Manufacturer Manufacturer Part
| | | Number | QTY
5a | CL Positive Lock Socket to Individual
| Wire Leads, 2 pos, 150mm | Molex | 2162711022 | 1
5b | Coin Cell Battery Connector | - | - | 1

# Recommended Assembly Steps

### 1. Pre-Enclosure PCB test

Be sure to connect and test all electronic components before assembling them inside of the clock. This includes:

- All LEDs on the LED PCB, including the AM/PM and alarm enable LEDs
- All buttons on the Brain PCB
- Software functions like time setting, alarm setting, and alarm sound
- All cables to ensure connectors don’t have defects
Caution: Never hot-plug anything. That is to say – Connect power to the system last. Never plug/unplug any cables if the Brain PCB is powered.
Caution: When handling PCBs, try to touch the on-board components as little as possible, as this could transfer electrostatic discharge (ESD) into the components. The boards are designed to be able to handle ESD exposure, but extra caution can’t hurt.

### 2. Mounting LED PCB to Enclosure

Slide the LED PCB into place. Caution: this step can shear off LEDs. Complete this step very carefully.
Damage to LED joints can cause segments to fail entirely. However, a sinister and more frustrating effect is intermittent failures, in which a sheared-off LED sometimes connects and sometimes doesn’t resulting in a segment that only sometimes lights up. To ensure no intermittent failures, test assembled Sinking Clock LED PCBs extensively.

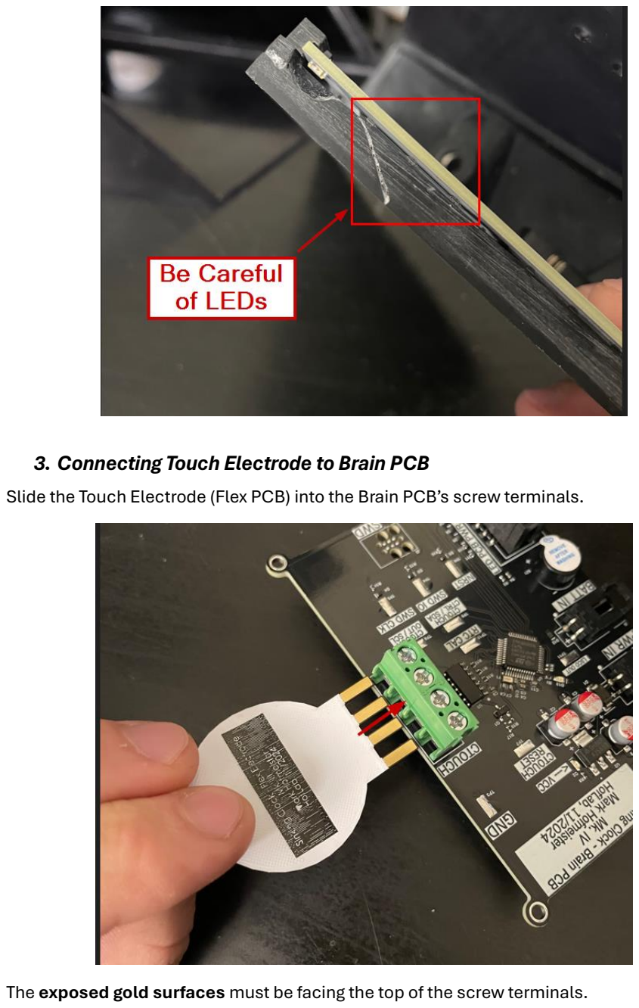
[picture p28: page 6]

### 3. Connecting Touch Electrode to Brain PCB

Slide the Touch Electrode (Flex PCB) into the Brain PCB’s screw terminals.

The exposed gold surfaces must be facing the top of the screw terminals.

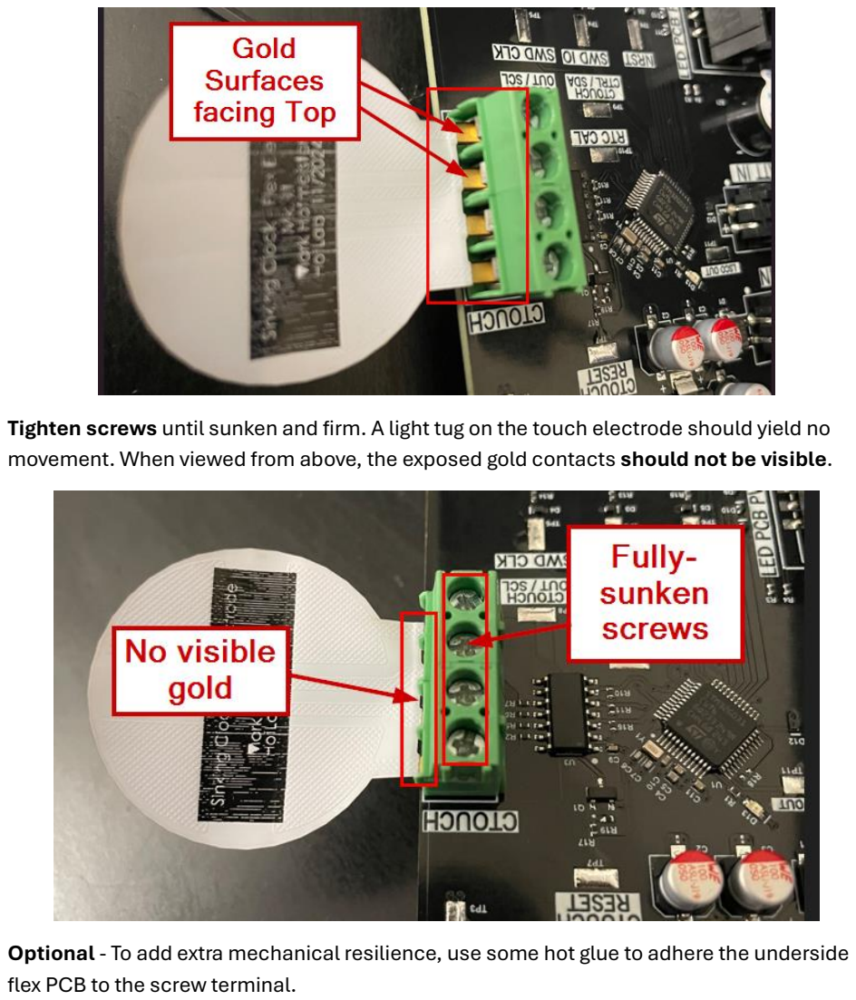
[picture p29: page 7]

Tighten screws until sunken and firm. A light tug on the touch electrode should yield no movement. When viewed from above, the exposed gold contacts should not be visible.

Optional - To add extra mechanical resilience, use some hot glue to adhere the underside flex PCB to the screw terminal.

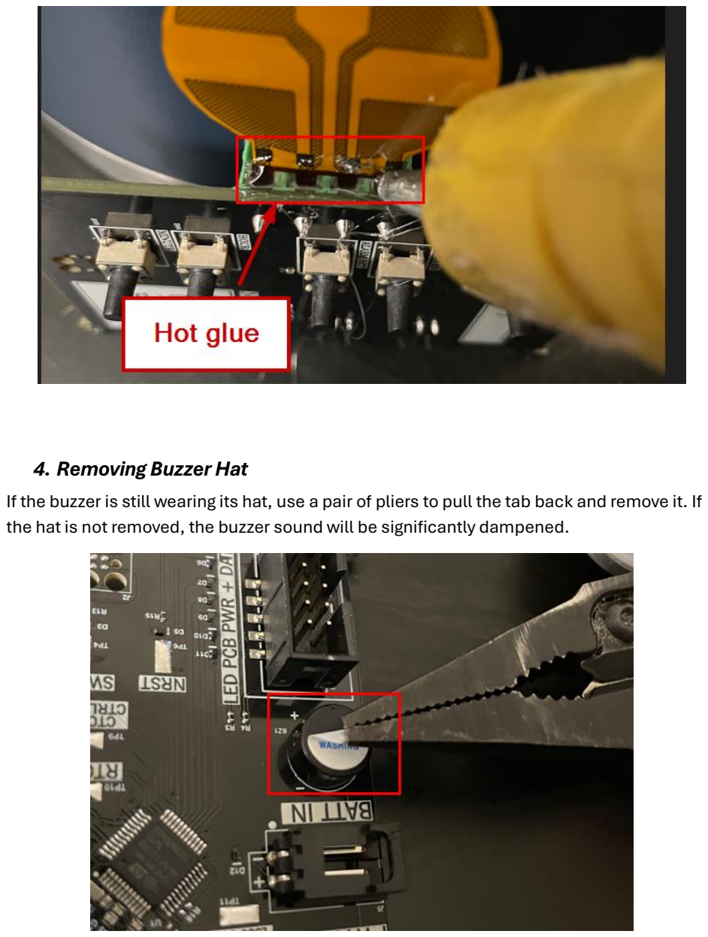
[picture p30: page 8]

### 4. Removing Buzzer Hat

If the buzzer is still wearing its hat, use a pair of pliers to pull the tab back and remove it. If the hat is not removed, the buzzer sound will be significantly dampened.

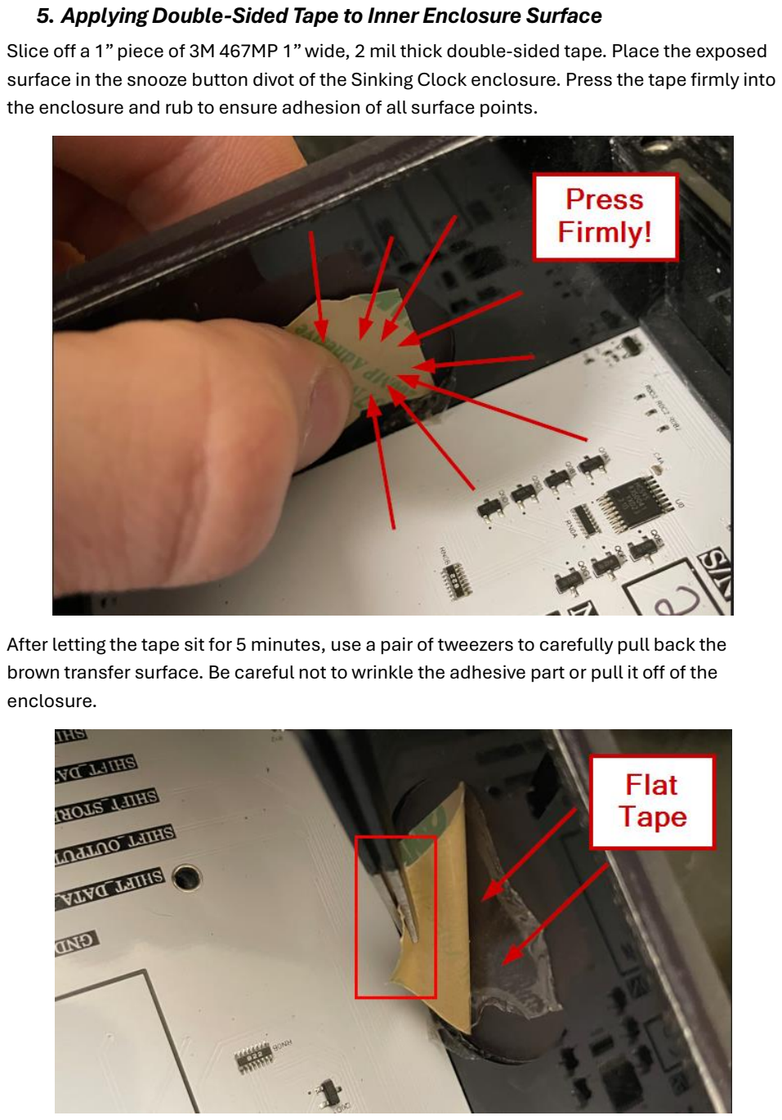
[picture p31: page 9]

### 5. Applying Double-Sided Tape to Inner Enclosure Surface

Slice off a 1” piece of 3M 467MP 1” wide, 2 mil thick double-sided tape. Place the exposed surface in the snooze button divot of the Sinking Clock enclosure. Press the tape firmly into the enclosure and rub to ensure adhesion of all surface points.

After letting the tape sit for 5 minutes, use a pair of tweezers to carefully pull back the brown transfer surface. Be careful not to wrinkle the adhesive part or pull it off of the enclosure.

Caution – once the touch sensor is adhered to the inner surface, do not place excessive force on it. This may tear it, break copper connections, or disconnect it from the Brain.

### 6. Connecting + Gluing IDC Cable to Brain PCB

Insert the IDC cable into the Brain PCB such that it extends towards the “LED PCB PWR + DATA” label. Use some hot glue to adhere the IDC cable to the socket.

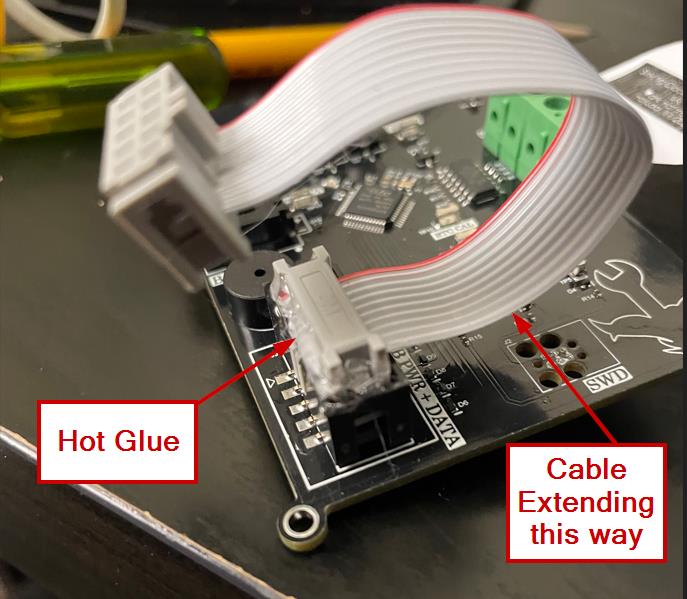
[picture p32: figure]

### 7. Mounting Brain PCB + Touch Electrode to Enclosure

Bend the touch sensor and adhere it to the exposed tape.

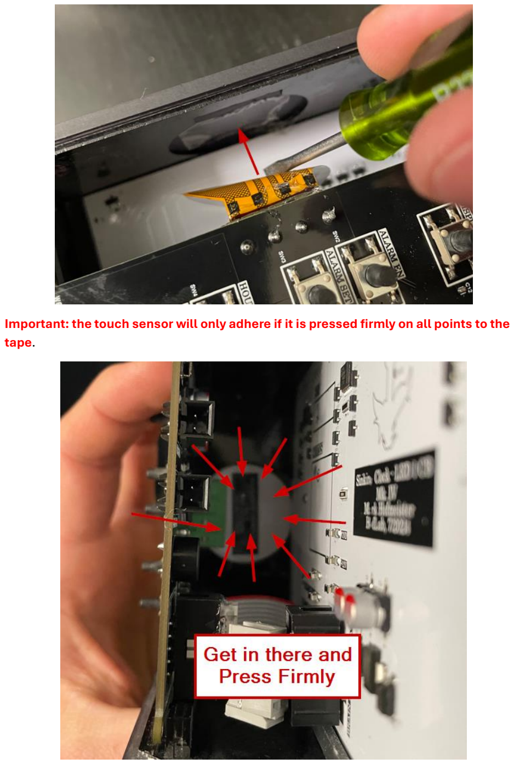
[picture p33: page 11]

Important: the touch sensor will only adhere if it is pressed firmly on all points to the tape.

### 8. Connecting + Gluing the IDC Cable to the LED PCB

Connect the other end of the IDC cable to the LED PCB connector. Use hot glue to adhere the IDC cable to the connector.

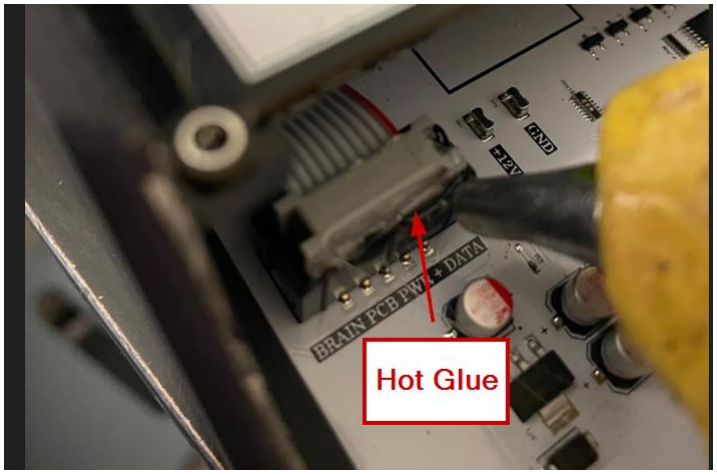
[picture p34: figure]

### 9. Connecting the Barrel Jack to the Enclosure

Connect the barrel jack to the 3D-printed bottom piece. Use hot glue around the edge for mechanical integrity.

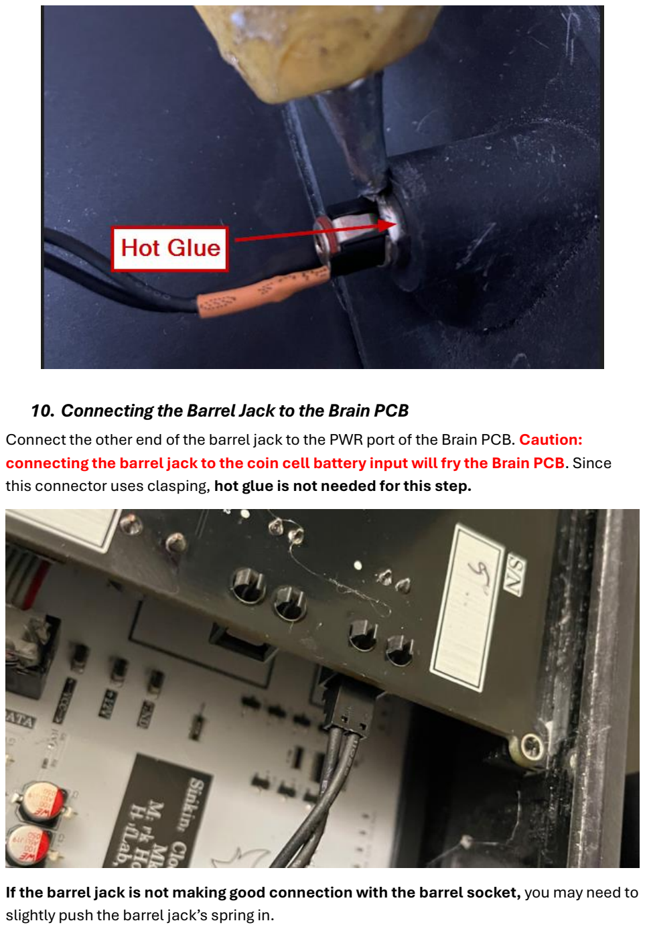
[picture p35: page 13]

### 10. Connecting the Barrel Jack to the Brain PCB

Connect the other end of the barrel jack to the PWR port of the Brain PCB. Caution: connecting the barrel jack to the coin cell battery input will fry the Brain PCB. Since this connector uses clasping, hot glue is not needed for this step.

If the barrel jack is not making good connection with the barrel socket, you may need to slightly push the barrel jack’s spring in.

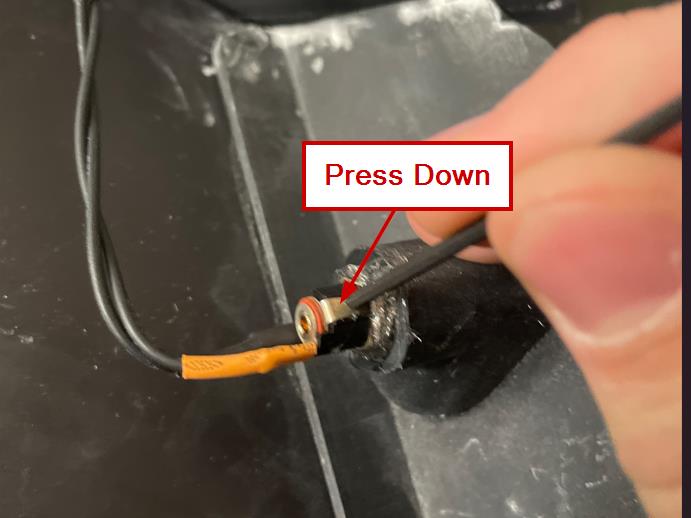
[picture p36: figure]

11. (Optional) Connecting the Coin Cell Harness to the Enclosure
Connect the coin cell holder to the 3D-printed bottom piece. Use hot glue around the edge for mechanical integrity.
12. (Optional) Connecting the Coin Cell Harness to the Brain PCB
Connect the other end of the coin cell cable to the BATT IN port of the Brain PCB. Since this connector uses clasping, hot glue is not needed for this step.

### 13. Final Test in Enclosure

Once fully assembled, be sure to test the clock in its entirety to ensure no failures occurred in the manufacturing process.

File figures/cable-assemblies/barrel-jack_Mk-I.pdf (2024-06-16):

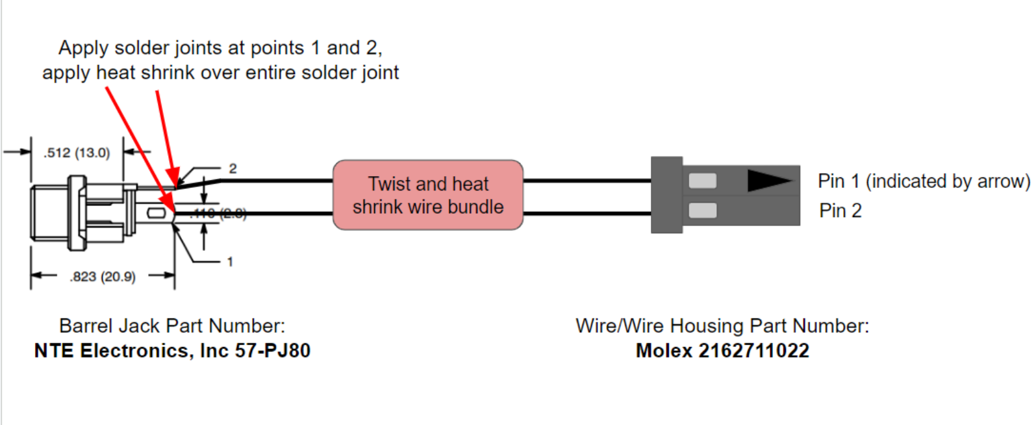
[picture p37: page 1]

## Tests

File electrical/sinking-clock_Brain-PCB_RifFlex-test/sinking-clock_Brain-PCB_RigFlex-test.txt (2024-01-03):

Board Information Report
Filename     : C:\Lab\sinking-clock\electrical\sinking-clock_Brain-PCB_RifFlex-test\sinking-clock_Brain-PCB_RigFlex-test.PcbDoc
Date         : 1/3/2024
Time         : 1:20:26 PM
Time Elapsed : 00:00:01

General
    Board Size, 129.714mmx89mm
    Components on board, 72
count : 2

Routing Information
    Routing completion, 99.29%
    Connections, 141
    Connections routed, 140
    Connections remaining, 1
count : 4

Layer, Arcs, Pads, Vias, Tracks, Texts, Fills, Regions, ComponentBodies
    Top Layer, 0, 169, 0, 386, 0, 2, 187, 0
    Bottom Layer, 0, 37, 0, 63, 0, 0, 29, 0
    Mechanical 1, 4, 0, 0, 4, 0, 0, 0, 57
    Top Tenting, 0, 0, 0, 0, 0, 0, 0, 0
    Outline, 13, 0, 0, 11, 0, 0, 0, 0
    Bottom Tenting, 0, 0, 0, 0, 0, 0, 0, 0
    Mechanical 13, 7, 0, 0, 256, 2, 0, 0, 14
    Mechanical 15, 1, 0, 0, 297, 0, 0, 0, 0
    Outline_OLD, 0, 0, 0, 4, 0, 0, 0, 0
    Multi-Layer, 0, 19, 55, 0, 0, 0, 2, 0
    Top Paste, 0, 0, 0, 0, 0, 0, 0, 0
    Bottom Paste, 0, 0, 0, 0, 0, 0, 0, 0
    Drill Guide, 0, 0, 0, 0, 0, 0, 0, 0
    Keep-Out Layer, 0, 0, 0, 0, 0, 0, 0, 0
    Drill Drawing, 0, 0, 0, 0, 0, 0, 0, 0
    Board Layer Stack Top Overlay, 658, 0, 0, 117, 137, 0, 4, 0
    Flex Top Coverlay, 0, 0, 0, 0, 0, 0, 0, 0
    Board Layer Stack Bottom Solder, 0, 0, 0, 0, 0, 0, 0, 0
    Flex Bottom Overlay, 1, 0, 0, 42, 33, 0, 2, 0
count : 19

Drill Pairs, Vias
    Top Layer - Bottom Layer, 55
count : 1

Layer, Sq.In., Sq.MM., Percent of layer
    Top Layer, 6.393, 4124.463, 72%
    Bottom Layer, 6.787, 4378.505, 77%
count : 2

Non-Plated Hole Size, Pads, Vias
    0mm, 74, 0
    1.067mm, 3, 0
    1.7mm, 1, 0
    1.8mm, 1, 0
    2.451mm, 4, 0
count : 5

Plated Hole Size, Pads, Vias
    0mm, 132, 0
    0.2794mm, 0, 55
    0.8mm, 2, 0
    1.1mm, 4, 0
    2.6mm, 4, 0
count : 5

Non-Plated Slot Size / Length, Pads
count : 0

Plated Slot Size / Length, Pads
count : 0

Non-Plated Square Hole Size, Pads
count : 0

Plated Square Hole Size, Pads
count : 0

Top Layer Annular Ring Size, Count
    -1.2255mm, 4
    -0.5335mm, 3
    0mm, 2
    0.2794mm, 55
    0.35mm, 2
    0.5mm, 2
    0.9mm, 4
    1.2mm, 2
count : 8

Mid Layer Annular Ring Size, Count
    -1.2255mm, 4
    -0.5335mm, 3
    0mm, 2
    0.2794mm, 55
    0.35mm, 2
    0.5mm, 2
    0.9mm, 4
    1.2mm, 2
count : 8

Bottom Layer Annular Ring Size, Count
    -1.2255mm, 4
    -0.5335mm, 3
    0mm, 2
    0.2794mm, 55
    0.35mm, 2
    0.5mm, 2
    0.9mm, 4
    1.2mm, 2
count : 8

Pad Solder Mask, Count
    0.03mm, 48
    0.0762mm, 20
    0.1016mm, 157
count : 3

Pad Paste Mask, Count
    0mm, 225
count : 1

Pad Pwr/Gnd Expansion, Count
    0.508mm, 225
count : 1

Pad Relief Conductor Width, Count
    0.254mm, 225
count : 1

Pad Relief Air Gap, Count
    0.254mm, 225
count : 1

Pad Relief Entries, Count
    4, 225
count : 1

Via Solder Mask, Count
    0.1016mm, 55
count : 1

Via Pwr/Gnd Expansion, Count
    0.508mm, 55
count : 1

Track Width, Count
    0.05mm, 232
    0.1mm, 57
    0.1016mm, 20
    0.127mm, 286
    0.2mm, 59
    0.254mm, 102
    0.3048mm, 354
    0.3556mm, 28
    0.4mm, 13
    0.4064mm, 29
count : 10

Arc Line Width, Count
    0.0127mm, 40
    0.05mm, 1
    0.1mm, 2
    0.127mm, 2
    0.2mm, 624
    0.25mm, 1
    0.254mm, 13
    0.4mm, 1
count : 8

Arc Radius, Count
    0.0047mm, 1
    0.006mm, 1
    0.0104mm, 1
    0.0104mm, 1
    0.0112mm, 1
    0.0115mm, 1
    0.0123mm, 1
    0.013mm, 1
    0.013mm, 1
    0.0134mm, 1
    0.0164mm, 1
    0.0165mm, 1
    0.0168mm, 1
    0.0169mm, 1
    0.0176mm, 1
    0.018mm, 1
    0.0181mm, 1
    0.0193mm, 1
    0.0208mm, 1
    0.021mm, 1
    0.022mm, 1
    0.0221mm, 1
    0.0238mm, 1
    0.024mm, 1
    0.0241mm, 1
    0.0245mm, 1
    0.025mm, 1
    0.0251mm, 1
    0.0255mm, 1
    0.0263mm, 1
    0.0273mm, 1
    0.0293mm, 1
    0.0293mm, 1
    0.0307mm, 1
    0.031mm, 1
    0.0321mm, 1
    0.0345mm, 1
    0.0352mm, 1
    0.0368mm, 1
    0.0399mm, 1
    0.0413mm, 1
    0.0431mm, 1
    0.0434mm, 1
    0.0434mm, 1
    0.0453mm, 1
    0.0457mm, 1
    0.0485mm, 1
    0.0492mm, 1
    0.05mm, 2
    0.0504mm, 1
    0.0538mm, 1
    0.0556mm, 1
    0.0592mm, 1
    0.0593mm, 1
    0.0594mm, 1
    0.0595mm, 1
    0.0602mm, 1
    0.0605mm, 1
    0.0616mm, 1
    0.0621mm, 1
    0.0621mm, 1
    0.0622mm, 1
    0.0663mm, 1
    0.0672mm, 1
    0.0695mm, 1
    0.0712mm, 1
    0.0715mm, 1
    0.0741mm, 1
    0.0747mm, 1
    0.0748mm, 1
    0.0754mm, 1
    0.0761mm, 1
    0.0779mm, 1
    0.0801mm, 1
    0.0814mm, 1
    0.0814mm, 1
    0.0822mm, 1
    0.0825mm, 1
    0.0861mm, 1
    0.0865mm, 1
    0.0871mm, 1
    0.0877mm, 1
    0.0877mm, 1
    0.0901mm, 1
    0.0966mm, 1
    0.0968mm, 1
    0.1mm, 12
    0.1002mm, 1
    0.1009mm, 1
    0.1017mm, 1
    0.1027mm, 1
    0.1061mm, 1
    0.1074mm, 1
    0.1084mm, 1
    0.1093mm, 1
    0.1104mm, 1
    0.1115mm, 1
    0.1146mm, 1
    0.1151mm, 1
    0.1183mm, 1
    0.1184mm, 1
    0.1245mm, 1
    0.125mm, 1
    0.1259mm, 1
    0.126mm, 1
    0.1286mm, 1
    0.1321mm, 1
    0.134mm, 1
    0.1341mm, 1
    0.1355mm, 1
    0.1364mm, 1
    0.1365mm, 1
    0.1406mm, 1
    0.1441mm, 1
    0.1447mm, 1
    0.1523mm, 1
    0.1562mm, 1
    0.1564mm, 1
    0.1666mm, 1
    0.169mm, 1
    0.1702mm, 1
    0.1704mm, 1
    0.1828mm, 1
    0.1837mm, 1
    0.1913mm, 1
    0.194mm, 1
    0.2mm, 1
    0.2007mm, 1
    0.2016mm, 1
    0.202mm, 1
    0.212mm, 1
    0.2123mm, 1
    0.2143mm, 1
    0.2218mm, 1
    0.2266mm, 1
    0.2274mm, 1
    0.2317mm, 1
    0.2365mm, 1
    0.244mm, 1
    0.2677mm, 1
    0.2692mm, 1
    0.2791mm, 1
    0.2854mm, 1
    0.2892mm, 1
    0.293mm, 1
    0.2969mm, 1
    0.2999mm, 1
    0.3031mm, 1
    0.3041mm, 1
    0.3165mm, 1
    0.3173mm, 1
    0.3215mm, 1
    0.3323mm, 1
    0.3336mm, 1
    0.3404mm, 1
    0.3437mm, 1
    0.3524mm, 1
    0.3543mm, 1
    0.3693mm, 1
    0.3719mm, 1
    0.387mm, 1
    0.3921mm, 1
    0.3945mm, 1
    0.4048mm, 1
    0.408mm, 1
    0.4092mm, 1
    0.4103mm, 1
    0.4271mm, 1
    0.4317mm, 1
    0.435mm, 1
    0.4371mm, 1
    0.4371mm, 1
    0.4383mm, 1
    0.4392mm, 1
    0.4428mm, 1
    0.4435mm, 1
    0.4688mm, 1
    0.4693mm, 1
    0.4837mm, 1
    0.4858mm, 1
    0.4938mm, 1
    0.4972mm, 1
    0.5mm, 8
    0.5122mm, 1
    0.5283mm, 1
    0.5363mm, 1
    0.5374mm, 1
    0.5421mm, 1
    0.5442mm, 1
    0.548mm, 1
    0.5607mm, 1
    0.5608mm, 1
    0.5685mm, 1
    0.5832mm, 1
    0.6253mm, 1
    0.6298mm, 1
    0.634mm, 1
    0.649mm, 1
    0.6539mm, 1
    0.6563mm, 1
    0.6631mm, 1
    0.667mm, 1
    0.6851mm, 1
    0.6865mm, 1
    0.6948mm, 1
    0.6976mm, 1
    0.7026mm, 1
    0.7131mm, 1
    0.7283mm, 1
    0.7381mm, 1
    0.7484mm, 1
    0.7568mm, 1
    0.7676mm, 1
    0.7746mm, 1
    0.775mm, 1
    0.776mm, 1
    0.7776mm, 1
    0.7788mm, 1
    0.7882mm, 1
    0.7937mm, 1
    0.7996mm, 1
    0.8089mm, 1
    0.8161mm, 1
    0.8333mm, 1
    0.8489mm, 1
    0.8495mm, 1
    0.851mm, 1
    0.8562mm, 1
    0.8594mm, 1
    0.8621mm, 1
    0.8744mm, 1
    0.8825mm, 1
    0.8909mm, 1
    0.8914mm, 1
    0.8924mm, 1
    0.8952mm, 1
    0.9008mm, 1
    0.9198mm, 1
    0.9276mm, 1
    0.932mm, 1
    0.9372mm, 1
    0.9456mm, 1
    0.9512mm, 1
    0.9548mm, 1
    0.9624mm, 1
    0.9707mm, 1
    0.977mm, 1
    1.0035mm, 1
    1.0061mm, 1
    1.0406mm, 1
    1.0589mm, 1
    1.0824mm, 1
    1.0884mm, 1
    1.0899mm, 1
    1.0932mm, 1
    1.0933mm, 1
    1.1193mm, 1
    1.1228mm, 1
    1.1236mm, 1
    1.1245mm, 1
    1.1257mm, 1
    1.1309mm, 1
    1.1464mm, 1
    1.1507mm, 1
    1.1619mm, 1
    1.1671mm, 1
    1.2054mm, 1
    1.2237mm, 1
    1.2316mm, 1
    1.2409mm, 1
    1.2572mm, 1
    1.2651mm, 1
    1.2755mm, 1
    1.2791mm, 1
    1.2796mm, 1
    1.2873mm, 1
    1.2903mm, 1
    1.2997mm, 1
    1.3mm, 4
    1.3052mm, 1
    1.3068mm, 1
    1.3217mm, 1
    1.3512mm, 1
    1.3659mm, 1
    1.3686mm, 1
    1.3743mm, 1
    1.3898mm, 1
    1.39mm, 1
    1.3906mm, 1
    1.4164mm, 1
    1.4232mm, 1
    1.4256mm, 1
    1.44mm, 1
    1.4507mm, 1
    1.4528mm, 1
    1.4645mm, 1
    1.4759mm, 1
    1.4759mm, 1
    1.5044mm, 1
    1.5129mm, 1
    1.5131mm, 1
    1.5172mm, 1
    1.527mm, 1
    1.5282mm, 1
    1.5547mm, 1
    1.5643mm, 1
    1.5668mm, 1
    1.5843mm, 1
    1.5938mm, 1
    1.6128mm, 1
    1.6188mm, 1
    1.6211mm, 1
    1.624mm, 1
    1.6376mm, 1
    1.6784mm, 1
    1.6854mm, 1
    1.6936mm, 1
    1.7062mm, 1
    1.717mm, 1
    1.7223mm, 1
    1.7292mm, 1
    1.732mm, 1
    1.7326mm, 1
    1.7409mm, 1
    1.7582mm, 1
    1.7656mm, 1
    1.7766mm, 1
    1.7852mm, 1
    1.7875mm, 1
    1.8652mm, 1
    1.8766mm, 1
    1.8806mm, 1
    1.9065mm, 1
    1.9143mm, 1
    1.9448mm, 1
    1.9482mm, 1
    1.958mm, 1
    1.9726mm, 1
    2.0133mm, 1
    2.0136mm, 1
    2.016mm, 1
    2.0247mm, 1
    2.0306mm, 1
    2.0441mm, 1
    2.0496mm, 1
    2.0507mm, 1
    2.0759mm, 1
    2.0918mm, 1
    2.0975mm, 1
    2.1018mm, 1
    2.1321mm, 1
    2.1757mm, 1
    2.2015mm, 1
    2.2218mm, 1
    2.2274mm, 1
    2.2515mm, 1
    2.2516mm, 1
    2.2623mm, 1
    2.2663mm, 1
    2.3076mm, 1
    2.3372mm, 1
    2.3721mm, 1
    2.3934mm, 1
    2.3993mm, 1
    2.4108mm, 1
    2.4168mm, 1
    2.4403mm, 1
    2.4719mm, 1
    2.4834mm, 1
    2.5mm, 4
    2.5144mm, 1
    2.5249mm, 1
    2.5282mm, 1
    2.5817mm, 1
    2.5869mm, 1
    2.5948mm, 1
    2.6039mm, 1
    2.6065mm, 1
    2.6178mm, 1
    2.6258mm, 1
    2.646mm, 1
    2.6759mm, 1
    2.6856mm, 1
    2.6914mm, 1
    2.6986mm, 1
    2.7135mm, 1
    2.7643mm, 1
    2.7711mm, 1
    2.7953mm, 1
    2.8087mm, 1
    2.8548mm, 1
    2.859mm, 1
    2.8603mm, 1
    2.8726mm, 1
    2.8885mm, 1
    2.9173mm, 1
    2.9324mm, 1
    2.9392mm, 1
    2.9502mm, 1
    2.9834mm, 1
    3.0297mm, 1
    3.0395mm, 1
    3.0397mm, 1
    3.0447mm, 1
    3.047mm, 1
    3.0718mm, 1
    3.0793mm, 1
    3.1148mm, 1
    3.2258mm, 1
    3.231mm, 1
    3.2766mm, 1
    3.3312mm, 1
    3.3506mm, 1
    3.4109mm, 1
    3.4142mm, 1
    3.4586mm, 1
    3.5192mm, 1
    3.5339mm, 1
    3.5431mm, 1
    3.5947mm, 1
    3.6115mm, 1
    3.6139mm, 1
    3.6159mm, 1
    3.6375mm, 1
    3.6679mm, 1
    3.6705mm, 1
    3.6984mm, 1
    3.7068mm, 1
    3.7179mm, 1
    3.7345mm, 1
    3.7619mm, 1
    3.78mm, 1
    3.7861mm, 1
    3.7933mm, 1
    3.8028mm, 1
    3.8399mm, 1
    3.8406mm, 1
    3.8479mm, 1
    3.8853mm, 1
    3.8905mm, 1
    3.9599mm, 1
    3.9603mm, 1
    3.9748mm, 1
    3.9764mm, 1
    4.0176mm, 1
    4.0232mm, 1
    4.0727mm, 1
    4.0791mm, 1
    4.1614mm, 1
    4.1815mm, 1
    4.1827mm, 1
    4.1883mm, 1
    4.2204mm, 1
    4.2403mm, 1
    4.2455mm, 1
    4.261mm, 1
    4.3439mm, 1
    4.3613mm, 1
    4.4314mm, 1
    4.4351mm, 1
    4.4525mm, 1
    4.541mm, 1
    4.5721mm, 1
    4.5749mm, 1
    4.5757mm, 1
    4.5979mm, 1
    4.609mm, 1
    4.6576mm, 1
    4.6583mm, 1
    4.7369mm, 1
    4.7451mm, 1
    4.7691mm, 1
    4.7819mm, 1
    4.8mm, 2
    4.8449mm, 1
    4.8602mm, 1
    4.9204mm, 1
    4.9684mm, 1
    4.9896mm, 1
    5.0117mm, 1
    5.0252mm, 1
    5.044mm, 1
    5.0471mm, 1
    5.05mm, 1
    5.105mm, 1
    5.1325mm, 1
    5.1716mm, 1
    5.2453mm, 1
    5.3274mm, 1
    5.3418mm, 1
    5.3617mm, 1
    5.4854mm, 1
    5.5013mm, 1
    5.6117mm, 1
    5.6639mm, 1
    5.6659mm, 1
    5.6682mm, 1
    5.6729mm, 1
    5.6927mm, 1
    5.7301mm, 1
    5.7765mm, 1
    5.8501mm, 1
    5.9403mm, 1
    5.948mm, 1
    6.1022mm, 1
    6.1617mm, 1
    6.2445mm, 1
    6.2663mm, 1
    6.2805mm, 1
    6.3481mm, 1
    6.387mm, 1
    6.4913mm, 1
    6.4927mm, 1
    6.5879mm, 1
    6.6037mm, 1
    6.6448mm, 1
    6.7267mm, 1
    6.8197mm, 1
    6.8509mm, 1
    6.9673mm, 1
    6.9827mm, 1
    6.9856mm, 1
    7.0688mm, 1
    7.0834mm, 1
    7.1001mm, 1
    7.1113mm, 1
    7.1944mm, 1
    7.2082mm, 1
    7.2111mm, 1
    7.3698mm, 1
    7.388mm, 1
    7.4276mm, 1
    7.4378mm, 1
    7.5303mm, 1
    7.5436mm, 1
    7.7127mm, 1
    7.8756mm, 1
    7.8826mm, 1
    7.927mm, 1
    8.0329mm, 1
    8.1089mm, 1
    8.1201mm, 1
    8.2016mm, 1
    8.2452mm, 1
    8.3262mm, 1
    8.3342mm, 1
    8.5036mm, 1
    8.511mm, 1
    8.5513mm, 1
    8.6877mm, 1
    9.0219mm, 1
    9.0889mm, 1
    9.1776mm, 1
    9.2494mm, 1
    9.2757mm, 1
    9.3217mm, 1
    9.355mm, 1
    9.3687mm, 1
    9.7232mm, 1
    9.933mm, 1
    10.025mm, 1
    10.2246mm, 1
    10.3138mm, 1
    10.6824mm, 1
    10.7309mm, 1
    11.0015mm, 1
    11.088mm, 1
    11.1852mm, 1
    11.2776mm, 1
    11.4871mm, 1
    11.9271mm, 1
    12.3717mm, 1
    12.8321mm, 1
    12.9236mm, 1
    13.0358mm, 1
    13.1366mm, 1
    13.1587mm, 1
    13.3823mm, 1
    13.6522mm, 1
    13.7031mm, 1
    13.8108mm, 1
    14.0457mm, 1
    14.1678mm, 1
    15.014mm, 1
    15.158mm, 1
    15.1904mm, 1
    15.5197mm, 1
    15.756mm, 1
    15.7692mm, 1
    16.0164mm, 1
    16.1135mm, 1
    16.3495mm, 1
    16.8036mm, 1
    17.2508mm, 1
    17.5801mm, 1
    17.745mm, 1
    17.8662mm, 1
    17.9689mm, 1
    18.0851mm, 1
    18.1025mm, 1
    18.6179mm, 1
    21.2893mm, 1
    21.4813mm, 1
    21.6444mm, 1
    22.5017mm, 1
    22.9598mm, 1
    23.7547mm, 1
    24.2705mm, 1
    24.3915mm, 1
    25.5798mm, 1
    28.5702mm, 1
    31.439mm, 1
    31.9912mm, 1
    32.4281mm, 1
    32.5262mm, 1
    34.9476mm, 1
    34.9818mm, 1
    39.1412mm, 1
    43.8621mm, 1
    49.3343mm, 1
    49.5565mm, 1
    50.8652mm, 1
    51.0382mm, 1
    52.8511mm, 1
    52.8601mm, 1
    54.1076mm, 1
    54.2191mm, 1
    56.3219mm, 1
    56.7826mm, 1
    64.061mm, 1
    64.2989mm, 1
    78.8217mm, 1
    83.0802mm, 1
    89.8451mm, 1
    92.0161mm, 1
    94.9314mm, 1
    97.5613mm, 1
    107.5377mm, 1
    108.7134mm, 1
    115.0977mm, 1
    115.9922mm, 1
    117.918mm, 1
    131.0437mm, 1
    131.0656mm, 1
    147.996mm, 1
    160.6174mm, 1
    166.575mm, 1
    167.9053mm, 1
    182.0256mm, 1
    213.1249mm, 1
    239.2084mm, 1
    263.7802mm, 1
    529.1397mm, 1
    610.535mm, 1
    684.7669mm, 1
    1925.9954mm, 1
    2076.939mm, 1
    2725.6086mm, 1
count : 658

Arc Degrees, Count
    0, 65
    1, 101
    2, 83
    3, 73
    4, 48
    5, 37
    6, 22
    7, 23
    8, 22
    9, 10
    10, 17
    11, 10
    12, 6
    13, 5
    14, 5
    15, 11
    16, 6
    17, 6
    18, 4
    19, 2
    20, 2
    21, 5
    22, 5
    23, 4
    24, 2
    25, 3
    27, 1
    28, 3
    29, 2
    30, 1
    31, 4
    32, 2
    33, 1
    34, 5
    35, 5
    36, 2
    38, 1
    39, 1
    40, 3
    41, 2
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
count : 70

Text Height, Count
    0.762mm, 2
    1mm, 45
    1.016mm, 25
    1.27mm, 4
    1.524mm, 81
    1.778mm, 5
    2mm, 1
    2.5mm, 3
    2.54mm, 3
    3mm, 1
    3.81mm, 2
count : 11

Text Width, Count
    0.2mm, 1
    0.254mm, 170
    0.3556mm, 1
count : 3

Net Track Width, Count
    0.1524mm, 38
count : 1

Net Via Size, Count
    0.5588mm, 38
count : 1

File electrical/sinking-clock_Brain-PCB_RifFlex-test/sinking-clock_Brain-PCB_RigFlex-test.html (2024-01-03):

Altium customize

# Board Information Report

Date: | | 1/3/2024
Time: | | 1:20:26 PM
Elapsed Time: | | 00:00:01
Filename: | | C:\Lab\sinking-clock\electrical\sinking-clock_Brain-PCB_RifFlex-test\sinking-clock_Brain-PCB_RigFlex-test.PcbDoc
Units: | | mmmils

## Contents

Contents

Board Specification

General

Routing

Routing Information

Layer Information

Layer Information

Drill Pairs

Copper Area

Copper Area

Board Holes

Non-Plated Hole Size

Plated Hole Size

Board Slots

Non-Plated Slot Size

Plated Slot Size

Board Square Holes

Non-Plated Square Hole Size

Plated Square Hole Size

Other

Top Layer Annular Ring Size

Mid Layer Annular Ring Size

Bottom Layer Annular Ring Size

Pad Solder Mask

Pad Paste Mask

Pad Pwr/Gnd Expansion

Pad Relief Conductor Width

Pad Relief Air Gap

Pad Relief Entries

Via Solder Mask

Via Pwr/Gnd Expansion

Track Width

Arc Line Width

Arc Radius

Arc Degrees

Text Height

Text Width

Net Track Width

Net Via Size

## Board Specification

General
Board Size | 129.714mm x 89mm
Components on board | 72

Back to top

## Routing

Routing Information
Routing completion | 99.29%
Connections | 141
Connections routed | 140
Connections remaining | 1

Back to top

## Layer Information

Layer | Arcs | Pads | Vias | Tracks | Texts | Fills | Regions | ComponentBodies
Top Layer | 0 | 169 | 0 | 386 | 0 | 2 | 187 | 0
Bottom Layer | 0 | 37 | 0 | 63 | 0 | 0 | 29 | 0
Mechanical 1 | 4 | 0 | 0 | 4 | 0 | 0 | 0 | 57
Top Tenting | 0 | 0 | 0 | 0 | 0 | 0 | 0 | 0
Outline | 13 | 0 | 0 | 11 | 0 | 0 | 0 | 0
Bottom Tenting | 0 | 0 | 0 | 0 | 0 | 0 | 0 | 0
Mechanical 13 | 7 | 0 | 0 | 256 | 2 | 0 | 0 | 14
Mechanical 15 | 1 | 0 | 0 | 297 | 0 | 0 | 0 | 0
Outline_OLD | 0 | 0 | 0 | 4 | 0 | 0 | 0 | 0
Multi-Layer | 0 | 19 | 55 | 0 | 0 | 0 | 2 | 0
Top Paste | 0 | 0 | 0 | 0 | 0 | 0 | 0 | 0
Bottom Paste | 0 | 0 | 0 | 0 | 0 | 0 | 0 | 0
Drill Guide | 0 | 0 | 0 | 0 | 0 | 0 | 0 | 0
Keep-Out Layer | 0 | 0 | 0 | 0 | 0 | 0 | 0 | 0
Drill Drawing | 0 | 0 | 0 | 0 | 0 | 0 | 0 | 0
Board Layer Stack Top Overlay | 658 | 0 | 0 | 117 | 137 | 0 | 4 | 0
Flex Top Coverlay | 0 | 0 | 0 | 0 | 0 | 0 | 0 | 0
Board Layer Stack Bottom Solder | 0 | 0 | 0 | 0 | 0 | 0 | 0 | 0
Flex Bottom Overlay | 1 | 0 | 0 | 42 | 33 | 0 | 2 | 0
Total | 684 | 225 | 55 | 1180 | 172 | 2 | 224 | 71

Back to top

Drill Pairs | Vias
Top Layer - Bottom Layer | 55
Total | 55

Back to top

## Copper Area

Layer | Sq.In. | Sq.MM. | Percent of layer
Top Layer | 6.393 | 4124.463 | 72%
Bottom Layer | 6.787 | 4378.505 | 77%
Total | 13.18 | 8502.968

Back to top

## Board Holes

Non-Plated Hole Size | Pads | Vias
0mm | 74 | 0
1.067mm | 3 | 0
1.7mm | 1 | 0
1.8mm | 1 | 0
2.451mm | 4 | 0
Total | 83 | 0

Back to top

Plated Hole Size | Pads | Vias
0mm | 132 | 0
0.2794mm | 0 | 55
0.8mm | 2 | 0
1.1mm | 4 | 0
2.6mm | 4 | 0
Total | 142 | 55

Back to top

## Board Slots

Non-Plated Slot Size / Length | Pads
Total | 0

Back to top

Plated Slot Size / Length | Pads
Total | 0

Back to top

## Board Square Holes

Non-Plated Square Hole Size | Pads
Total | 0

Back to top

Plated Square Hole Size | Pads
Total | 0

Back to top

## Other

Top Layer Annular Ring Size | Count
-1.2255mm | 4
-0.5335mm | 3
0mm | 2
0.2794mm | 55
0.35mm | 2
0.5mm | 2
0.9mm | 4
1.2mm | 2
Total | 74

Back to top

Mid Layer Annular Ring Size | Count
-1.2255mm | 4
-0.5335mm | 3
0mm | 2
0.2794mm | 55
0.35mm | 2
0.5mm | 2
0.9mm | 4
1.2mm | 2
Total | 74

Back to top

Bottom Layer Annular Ring Size | Count
-1.2255mm | 4
-0.5335mm | 3
0mm | 2
0.2794mm | 55
0.35mm | 2
0.5mm | 2
0.9mm | 4
1.2mm | 2
Total | 74

Back to top

Pad Solder Mask | Count
0.03mm | 48
0.0762mm | 20
0.1016mm | 157
Total | 225

Back to top

Pad Paste Mask | Count
0mm | 225
Total | 225

Back to top

Pad Pwr/Gnd Expansion | Count
0.508mm | 225
Total | 225

Back to top

Pad Relief Conductor Width | Count
0.254mm | 225
Total | 225

Back to top

Pad Relief Air Gap | Count
0.254mm | 225
Total | 225

Back to top

Pad Relief Entries | Count
4 | 225
Total | 225

Back to top

Via Solder Mask | Count
0.1016mm | 55
Total | 55

Back to top

Via Pwr/Gnd Expansion | Count
0.508mm | 55
Total | 55

Back to top

Track Width | Count
0.05mm | 232
0.1mm | 57
0.1016mm | 20
0.127mm | 286
0.2mm | 59
0.254mm | 102
0.3048mm | 354
0.3556mm | 28
0.4mm | 13
0.4064mm | 29
Total | 1180

Back to top

Arc Line Width | Count
0.0127mm | 40
0.05mm | 1
0.1mm | 2
0.127mm | 2
0.2mm | 624
0.25mm | 1
0.254mm | 13
0.4mm | 1
Total | 684

Back to top

Arc Radius | Count
0.0047mm | 1
0.006mm | 1
0.0104mm | 1
0.0104mm | 1
0.0112mm | 1
0.0115mm | 1
0.0123mm | 1
0.013mm | 1
0.013mm | 1
0.0134mm | 1
0.0164mm | 1
0.0165mm | 1
0.0168mm | 1
0.0169mm | 1
0.0176mm | 1
0.018mm | 1
0.0181mm | 1
0.0193mm | 1
0.0208mm | 1
0.021mm | 1
0.022mm | 1
0.0221mm | 1
0.0238mm | 1
0.024mm | 1
0.0241mm | 1
0.0245mm | 1
0.025mm | 1
0.0251mm | 1
0.0255mm | 1
0.0263mm | 1
0.0273mm | 1
0.0293mm | 1
0.0293mm | 1
0.0307mm | 1
0.031mm | 1
0.0321mm | 1
0.0345mm | 1
0.0352mm | 1
0.0368mm | 1
0.0399mm | 1
0.0413mm | 1
0.0431mm | 1
0.0434mm | 1
0.0434mm | 1
0.0453mm | 1
0.0457mm | 1
0.0485mm | 1
0.0492mm | 1
0.05mm | 2
0.0504mm | 1
0.0538mm | 1
0.0556mm | 1
0.0592mm | 1
0.0593mm | 1
0.0594mm | 1
0.0595mm | 1
0.0602mm | 1
0.0605mm | 1
0.0616mm | 1
0.0621mm | 1
0.0621mm | 1
0.0622mm | 1
0.0663mm | 1
0.0672mm | 1
0.0695mm | 1
0.0712mm | 1
0.0715mm | 1
0.0741mm | 1
0.0747mm | 1
0.0748mm | 1
0.0754mm | 1
0.0761mm | 1
0.0779mm | 1
0.0801mm | 1
0.0814mm | 1
0.0814mm | 1
0.0822mm | 1
0.0825mm | 1
0.0861mm | 1
0.0865mm | 1
0.0871mm | 1
0.0877mm | 1
0.0877mm | 1
0.0901mm | 1
0.0966mm | 1
0.0968mm | 1
0.1mm | 12
0.1002mm | 1
0.1009mm | 1
0.1017mm | 1
0.1027mm | 1
0.1061mm | 1
0.1074mm | 1
0.1084mm | 1
0.1093mm | 1
0.1104mm | 1
0.1115mm | 1
0.1146mm | 1
0.1151mm | 1
0.1183mm | 1
0.1184mm | 1
0.1245mm | 1
0.125mm | 1
0.1259mm | 1
0.126mm | 1
0.1286mm | 1
0.1321mm | 1
0.134mm | 1
0.1341mm | 1
0.1355mm | 1
0.1364mm | 1
0.1365mm | 1
0.1406mm | 1
0.1441mm | 1
0.1447mm | 1
0.1523mm | 1
0.1562mm | 1
0.1564mm | 1
0.1666mm | 1
0.169mm | 1
0.1702mm | 1
0.1704mm | 1
0.1828mm | 1
0.1837mm | 1
0.1913mm | 1
0.194mm | 1
0.2mm | 1
0.2007mm | 1
0.2016mm | 1
0.202mm | 1
0.212mm | 1
0.2123mm | 1
0.2143mm | 1
0.2218mm | 1
0.2266mm | 1
0.2274mm | 1
0.2317mm | 1
0.2365mm | 1
0.244mm | 1
0.2677mm | 1
0.2692mm | 1
0.2791mm | 1
0.2854mm | 1
0.2892mm | 1
0.293mm | 1
0.2969mm | 1
0.2999mm | 1
0.3031mm | 1
0.3041mm | 1
0.3165mm | 1
0.3173mm | 1
0.3215mm | 1
0.3323mm | 1
0.3336mm | 1
0.3404mm | 1
0.3437mm | 1
0.3524mm | 1
0.3543mm | 1
0.3693mm | 1
0.3719mm | 1
0.387mm | 1
0.3921mm | 1
0.3945mm | 1
0.4048mm | 1
0.408mm | 1
0.4092mm | 1
0.4103mm | 1
0.4271mm | 1
0.4317mm | 1
0.435mm | 1
0.4371mm | 1
0.4371mm | 1
0.4383mm | 1
0.4392mm | 1
0.4428mm | 1
0.4435mm | 1
0.4688mm | 1
0.4693mm | 1
0.4837mm | 1
0.4858mm | 1
0.4938mm | 1
0.4972mm | 1
0.5mm | 8
0.5122mm | 1
0.5283mm | 1
0.5363mm | 1
0.5374mm | 1
0.5421mm | 1
0.5442mm | 1
0.548mm | 1
0.5607mm | 1
0.5608mm | 1
0.5685mm | 1
0.5832mm | 1
0.6253mm | 1
0.6298mm | 1
0.634mm | 1
0.649mm | 1
0.6539mm | 1
0.6563mm | 1
0.6631mm | 1
0.667mm | 1
0.6851mm | 1
0.6865mm | 1
0.6948mm | 1
0.6976mm | 1
0.7026mm | 1
0.7131mm | 1
0.7283mm | 1
0.7381mm | 1
0.7484mm | 1
0.7568mm | 1
0.7676mm | 1
0.7746mm | 1
0.775mm | 1
0.776mm | 1
0.7776mm | 1
0.7788mm | 1
0.7882mm | 1
0.7937mm | 1
0.7996mm | 1
0.8089mm | 1
0.8161mm | 1
0.8333mm | 1
0.8489mm | 1
0.8495mm | 1
0.851mm | 1
0.8562mm | 1
0.8594mm | 1
0.8621mm | 1
0.8744mm | 1
0.8825mm | 1
0.8909mm | 1
0.8914mm | 1
0.8924mm | 1
0.8952mm | 1
0.9008mm | 1
0.9198mm | 1
0.9276mm | 1
0.932mm | 1
0.9372mm | 1
0.9456mm | 1
0.9512mm | 1
0.9548mm | 1
0.9624mm | 1
0.9707mm | 1
0.977mm | 1
1.0035mm | 1
1.0061mm | 1
1.0406mm | 1
1.0589mm | 1
1.0824mm | 1
1.0884mm | 1
1.0899mm | 1
1.0932mm | 1
1.0933mm | 1
1.1193mm | 1
1.1228mm | 1
1.1236mm | 1
1.1245mm | 1
1.1257mm | 1
1.1309mm | 1
1.1464mm | 1
1.1507mm | 1
1.1619mm | 1
1.1671mm | 1
1.2054mm | 1
1.2237mm | 1
1.2316mm | 1
1.2409mm | 1
1.2572mm | 1
1.2651mm | 1
1.2755mm | 1
1.2791mm | 1
1.2796mm | 1
1.2873mm | 1
1.2903mm | 1
1.2997mm | 1
1.3mm | 4
1.3052mm | 1
1.3068mm | 1
1.3217mm | 1
1.3512mm | 1
1.3659mm | 1
1.3686mm | 1
1.3743mm | 1
1.3898mm | 1
1.39mm | 1
1.3906mm | 1
1.4164mm | 1
1.4232mm | 1
1.4256mm | 1
1.44mm | 1
1.4507mm | 1
1.4528mm | 1
1.4645mm | 1
1.4759mm | 1
1.4759mm | 1
1.5044mm | 1
1.5129mm | 1
1.5131mm | 1
1.5172mm | 1
1.527mm | 1
1.5282mm | 1
1.5547mm | 1
1.5643mm | 1
1.5668mm | 1
1.5843mm | 1
1.5938mm | 1
1.6128mm | 1
1.6188mm | 1
1.6211mm | 1
1.624mm | 1
1.6376mm | 1
1.6784mm | 1
1.6854mm | 1
1.6936mm | 1
1.7062mm | 1
1.717mm | 1
1.7223mm | 1
1.7292mm | 1
1.732mm | 1
1.7326mm | 1
1.7409mm | 1
1.7582mm | 1
1.7656mm | 1
1.7766mm | 1
1.7852mm | 1
1.7875mm | 1
1.8652mm | 1
1.8766mm | 1
1.8806mm | 1
1.9065mm | 1
1.9143mm | 1
1.9448mm | 1
1.9482mm | 1
1.958mm | 1
1.9726mm | 1
2.0133mm | 1
2.0136mm | 1
2.016mm | 1
2.0247mm | 1
2.0306mm | 1
2.0441mm | 1
2.0496mm | 1
2.0507mm | 1
2.0759mm | 1
2.0918mm | 1
2.0975mm | 1
2.1018mm | 1
2.1321mm | 1
2.1757mm | 1
2.2015mm | 1
2.2218mm | 1
2.2274mm | 1
2.2515mm | 1
2.2516mm | 1
2.2623mm | 1
2.2663mm | 1
2.3076mm | 1
2.3372mm | 1
2.3721mm | 1
2.3934mm | 1
2.3993mm | 1
2.4108mm | 1
2.4168mm | 1
2.4403mm | 1
2.4719mm | 1
2.4834mm | 1
2.5mm | 4
2.5144mm | 1
2.5249mm | 1
2.5282mm | 1
2.5817mm | 1
2.5869mm | 1
2.5948mm | 1
2.6039mm | 1
2.6065mm | 1
2.6178mm | 1
2.6258mm | 1
2.646mm | 1
2.6759mm | 1
2.6856mm | 1
2.6914mm | 1
2.6986mm | 1
2.7135mm | 1
2.7643mm | 1
2.7711mm | 1
2.7953mm | 1
2.8087mm | 1
2.8548mm | 1
2.859mm | 1
2.8603mm | 1
2.8726mm | 1
2.8885mm | 1
2.9173mm | 1
2.9324mm | 1
2.9392mm | 1
2.9502mm | 1
2.9834mm | 1
3.0297mm | 1
3.0395mm | 1
3.0397mm | 1
3.0447mm | 1
3.047mm | 1
3.0718mm | 1
3.0793mm | 1
3.1148mm | 1
3.2258mm | 1
3.231mm | 1
3.2766mm | 1
3.3312mm | 1
3.3506mm | 1
3.4109mm | 1
3.4142mm | 1
3.4586mm | 1
3.5192mm | 1
3.5339mm | 1
3.5431mm | 1
3.5947mm | 1
3.6115mm | 1
3.6139mm | 1
3.6159mm | 1
3.6375mm | 1
3.6679mm | 1
3.6705mm | 1
3.6984mm | 1
3.7068mm | 1
3.7179mm | 1
3.7345mm | 1
3.7619mm | 1
3.78mm | 1
3.7861mm | 1
3.7933mm | 1
3.8028mm | 1
3.8399mm | 1
3.8406mm | 1
3.8479mm | 1
3.8853mm | 1
3.8905mm | 1
3.9599mm | 1
3.9603mm | 1
3.9748mm | 1
3.9764mm | 1
4.0176mm | 1
4.0232mm | 1
4.0727mm | 1
4.0791mm | 1
4.1614mm | 1
4.1815mm | 1
4.1827mm | 1
4.1883mm | 1
4.2204mm | 1
4.2403mm | 1
4.2455mm | 1
4.261mm | 1
4.3439mm | 1
4.3613mm | 1
4.4314mm | 1
4.4351mm | 1
4.4525mm | 1
4.541mm | 1
4.5721mm | 1
4.5749mm | 1
4.5757mm | 1
4.5979mm | 1
4.609mm | 1
4.6576mm | 1
4.6583mm | 1
4.7369mm | 1
4.7451mm | 1
4.7691mm | 1
4.7819mm | 1
4.8mm | 2
4.8449mm | 1
4.8602mm | 1
4.9204mm | 1
4.9684mm | 1
4.9896mm | 1
5.0117mm | 1
5.0252mm | 1
5.044mm | 1
5.0471mm | 1
5.05mm | 1
5.105mm | 1
5.1325mm | 1
5.1716mm | 1
5.2453mm | 1
5.3274mm | 1
5.3418mm | 1
5.3617mm | 1
5.4854mm | 1
5.5013mm | 1
5.6117mm | 1
5.6639mm | 1
5.6659mm | 1
5.6682mm | 1
5.6729mm | 1
5.6927mm | 1
5.7301mm | 1
5.7765mm | 1
5.8501mm | 1
5.9403mm | 1
5.948mm | 1
6.1022mm | 1
6.1617mm | 1
6.2445mm | 1
6.2663mm | 1
6.2805mm | 1
6.3481mm | 1
6.387mm | 1
6.4913mm | 1
6.4927mm | 1
6.5879mm | 1
6.6037mm | 1
6.6448mm | 1
6.7267mm | 1
6.8197mm | 1
6.8509mm | 1
6.9673mm | 1
6.9827mm | 1
6.9856mm | 1
7.0688mm | 1
7.0834mm | 1
7.1001mm | 1
7.1113mm | 1
7.1944mm | 1
7.2082mm | 1
7.2111mm | 1
7.3698mm | 1
7.388mm | 1
7.4276mm | 1
7.4378mm | 1
7.5303mm | 1
7.5436mm | 1
7.7127mm | 1
7.8756mm | 1
7.8826mm | 1
7.927mm | 1
8.0329mm | 1
8.1089mm | 1
8.1201mm | 1
8.2016mm | 1
8.2452mm | 1
8.3262mm | 1
8.3342mm | 1
8.5036mm | 1
8.511mm | 1
8.5513mm | 1
8.6877mm | 1
9.0219mm | 1
9.0889mm | 1
9.1776mm | 1
9.2494mm | 1
9.2757mm | 1
9.3217mm | 1
9.355mm | 1
9.3687mm | 1
9.7232mm | 1
9.933mm | 1
10.025mm | 1
10.2246mm | 1
10.3138mm | 1
10.6824mm | 1
10.7309mm | 1
11.0015mm | 1
11.088mm | 1
11.1852mm | 1
11.2776mm | 1
11.4871mm | 1
11.9271mm | 1
12.3717mm | 1
12.8321mm | 1
12.9236mm | 1
13.0358mm | 1
13.1366mm | 1
13.1587mm | 1
13.3823mm | 1
13.6522mm | 1
13.7031mm | 1
13.8108mm | 1
14.0457mm | 1
14.1678mm | 1
15.014mm | 1
15.158mm | 1
15.1904mm | 1
15.5197mm | 1
15.756mm | 1
15.7692mm | 1
16.0164mm | 1
16.1135mm | 1
16.3495mm | 1
16.8036mm | 1
17.2508mm | 1
17.5801mm | 1
17.745mm | 1
17.8662mm | 1
17.9689mm | 1
18.0851mm | 1
18.1025mm | 1
18.6179mm | 1
21.2893mm | 1
21.4813mm | 1
21.6444mm | 1
22.5017mm | 1
22.9598mm | 1
23.7547mm | 1
24.2705mm | 1
24.3915mm | 1
25.5798mm | 1
28.5702mm | 1
31.439mm | 1
31.9912mm | 1
32.4281mm | 1
32.5262mm | 1
34.9476mm | 1
34.9818mm | 1
39.1412mm | 1
43.8621mm | 1
49.3343mm | 1
49.5565mm | 1
50.8652mm | 1
51.0382mm | 1
52.8511mm | 1
52.8601mm | 1
54.1076mm | 1
54.2191mm | 1
56.3219mm | 1
56.7826mm | 1
64.061mm | 1
64.2989mm | 1
78.8217mm | 1
83.0802mm | 1
89.8451mm | 1
92.0161mm | 1
94.9314mm | 1
97.5613mm | 1
107.5377mm | 1
108.7134mm | 1
115.0977mm | 1
115.9922mm | 1
117.918mm | 1
131.0437mm | 1
131.0656mm | 1
147.996mm | 1
160.6174mm | 1
166.575mm | 1
167.9053mm | 1
182.0256mm | 1
213.1249mm | 1
239.2084mm | 1
263.7802mm | 1
529.1397mm | 1
610.535mm | 1
684.7669mm | 1
1925.9954mm | 1
2076.939mm | 1
2725.6086mm | 1
Total | 684

Back to top

Arc Degrees | Count
0 | 65
1 | 101
2 | 83
3 | 73
4 | 48
5 | 37
6 | 22
7 | 23
8 | 22
9 | 10
10 | 17
11 | 10
12 | 6
13 | 5
14 | 5
15 | 11
16 | 6
17 | 6
18 | 4
19 | 2
20 | 2
21 | 5
22 | 5
23 | 4
24 | 2
25 | 3
27 | 1
28 | 3
29 | 2
30 | 1
31 | 4
32 | 2
33 | 1
34 | 5
35 | 5
36 | 2
38 | 1
39 | 1
40 | 3
41 | 2
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
Total | 684

Back to top

Text Height | Count
0.762mm | 2
1mm | 45
1.016mm | 25
1.27mm | 4
1.524mm | 81
1.778mm | 5
2mm | 1
2.5mm | 3
2.54mm | 3
3mm | 1
3.81mm | 2
Total | 172

Back to top

Text Width | Count
0.2mm | 1
0.254mm | 170
0.3556mm | 1
Total | 172

Back to top

Net Track Width | Count
0.1524mm | 38
Total | 38

Back to top

Net Via Size | Count
0.5588mm | 38
Total | 38

Back to top

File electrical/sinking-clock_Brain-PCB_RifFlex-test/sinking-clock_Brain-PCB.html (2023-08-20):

Altium customize

# Board Information Report

Date: | | 8/20/2023
Time: | | 9:31:09 AM
Elapsed Time: | | 00:00:01
Filename: | | C:\Lab\sinking-clock\electrical\sinking-clock_Brain-PCB\sinking-clock_Brain-PCB.PcbDoc
Units: | | mmmils

## Contents

Contents

Board Specification

General

Routing

Routing Information

Layer Information

Layer Information

Drill Pairs

Copper Area

Copper Area

Board Holes

Non-Plated Hole Size

Plated Hole Size

Board Slots

Non-Plated Slot Size

Plated Slot Size

Board Square Holes

Non-Plated Square Hole Size

Plated Square Hole Size

Other

Top Layer Annular Ring Size

Mid Layer Annular Ring Size

Bottom Layer Annular Ring Size

Pad Solder Mask

Pad Paste Mask

Pad Pwr/Gnd Expansion

Pad Relief Conductor Width

Pad Relief Air Gap

Pad Relief Entries

Via Solder Mask

Via Pwr/Gnd Expansion

Track Width

Arc Line Width

Arc Radius

Arc Degrees

Text Height

Text Width

Net Track Width

Net Via Size

## Board Specification

General
Board Size | 62.6mm x 89mm
Components on board | 45

Back to top

## Routing

Routing Information
Routing completion | 100.00%
Connections | 88
Connections routed | 88
Connections remaining | 0

Back to top

## Layer Information

Layer | Arcs | Pads | Vias | Tracks | Texts | Fills | Regions | ComponentBodies
Top Layer | 0 | 133 | 0 | 265 | 0 | 0 | 6 | 0
Bottom Layer | 0 | 20 | 0 | 43 | 0 | 0 | 6 | 0
Mechanical 1 | 4 | 0 | 0 | 4 | 0 | 0 | 0 | 33
Outline | 12 | 0 | 0 | 4 | 0 | 0 | 0 | 0
Mechanical 13 | 7 | 0 | 0 | 148 | 2 | 0 | 0 | 11
Mechanical 15 | 1 | 0 | 0 | 169 | 0 | 0 | 0 | 0
Outline_OLD | 0 | 0 | 0 | 4 | 0 | 0 | 0 | 0
Multi-Layer | 0 | 15 | 38 | 0 | 0 | 0 | 1 | 0
Top Paste | 0 | 0 | 0 | 0 | 0 | 0 | 0 | 0
Top Overlay | 10438 | 0 | 0 | 144 | 93 | 0 | 0 | 0
Top Solder | 0 | 0 | 0 | 0 | 0 | 0 | 0 | 0
Bottom Solder | 0 | 0 | 0 | 0 | 0 | 0 | 0 | 0
Bottom Overlay | 1 | 0 | 0 | 0 | 14 | 0 | 0 | 0
Bottom Paste | 0 | 0 | 0 | 0 | 0 | 0 | 0 | 0
Drill Guide | 0 | 0 | 0 | 0 | 0 | 0 | 0 | 0
Keep-Out Layer | 0 | 0 | 0 | 0 | 0 | 0 | 0 | 0
Drill Drawing | 0 | 0 | 0 | 0 | 0 | 0 | 0 | 0
Total | 10463 | 168 | 38 | 781 | 109 | 0 | 13 | 44

Back to top

Drill Pairs | Vias
Top Layer - Bottom Layer | 38
Total | 38

Back to top

## Copper Area

Layer | Sq.In. | Sq.MM. | Percent of layer
Top Layer | 6.405 | 4132.049 | 87%
Bottom Layer | 6.848 | 4418.312 | 93%
Total | 13.253 | 8550.361

Back to top

## Board Holes

Non-Plated Hole Size | Pads | Vias
0mm | 48 | 0
0.991mm | 3 | 0
1.7mm | 1 | 0
1.8mm | 1 | 0
Total | 53 | 0

Back to top

Plated Hole Size | Pads | Vias
0mm | 105 | 0
0.2794mm | 0 | 38
0.8mm | 2 | 0
1.1mm | 4 | 0
2.6mm | 4 | 0
Total | 115 | 38

Back to top

## Board Slots

Non-Plated Slot Size / Length | Pads
Total | 0

Back to top

Plated Slot Size / Length | Pads
Total | 0

Back to top

## Board Square Holes

Non-Plated Square Hole Size | Pads
Total | 0

Back to top

Plated Square Hole Size | Pads
Total | 0

Back to top

## Other

Top Layer Annular Ring Size | Count
0mm | 5
0.2794mm | 38
0.35mm | 2
0.5mm | 2
0.9mm | 4
1.2mm | 2
Total | 53

Back to top

Mid Layer Annular Ring Size | Count
0mm | 5
0.2794mm | 38
0.35mm | 2
0.5mm | 2
0.9mm | 4
1.2mm | 2
Total | 53

Back to top

Bottom Layer Annular Ring Size | Count
0mm | 5
0.2794mm | 38
0.35mm | 2
0.5mm | 2
0.9mm | 4
1.2mm | 2
Total | 53

Back to top

Pad Solder Mask | Count
0.03mm | 48
0.1016mm | 120
Total | 168

Back to top

Pad Paste Mask | Count
-1mm | 6
0mm | 162
Total | 168

Back to top

Pad Pwr/Gnd Expansion | Count
0.508mm | 168
Total | 168

Back to top

Pad Relief Conductor Width | Count
0.254mm | 168
Total | 168

Back to top

Pad Relief Air Gap | Count
0.254mm | 168
Total | 168

Back to top

Pad Relief Entries | Count
4 | 168
Total | 168

Back to top

Via Solder Mask | Count
0.1016mm | 38
Total | 38

Back to top

Via Pwr/Gnd Expansion | Count
0.508mm | 38
Total | 38

Back to top

Track Width | Count
0.0127mm | 40
0.05mm | 168
0.1mm | 9
0.127mm | 203
0.2mm | 21
0.254mm | 86
0.3048mm | 193
0.4mm | 9
0.406mm | 3
0.4064mm | 49
Total | 781

Back to top

Arc Line Width | Count
0.0127mm | 8800
0.05mm | 1
0.127mm | 2
0.2mm | 1644
0.25mm | 1
0.254mm | 12
0.3mm | 2
0.4mm | 1
Total | 10463

Back to top

Arc Radius | Count
0.0013mm | 1
0.0014mm | 1
0.0017mm | 1
0.0017mm | 1
0.0018mm | 1
0.0019mm | 1
0.0019mm | 1
0.002mm | 2
0.002mm | 1
0.0021mm | 1
0.0022mm | 2
0.0022mm | 1
0.0023mm | 1
0.0023mm | 1
0.0023mm | 2
0.0023mm | 1
0.0023mm | 1
0.0024mm | 1
0.0024mm | 1
0.0025mm | 1
0.0025mm | 4
0.0025mm | 2
0.0025mm | 1
0.0026mm | 1
0.0026mm | 1
0.0027mm | 1
0.0027mm | 1
0.0027mm | 1
0.0027mm | 1
0.0028mm | 1
0.0028mm | 1
0.0028mm | 1
0.0029mm | 1
0.003mm | 1
0.003mm | 1
0.003mm | 1
0.003mm | 13
0.003mm | 1
0.003mm | 2
0.0031mm | 12
0.0031mm | 1
0.0031mm | 1
0.0031mm | 1
0.0032mm | 1
0.0032mm | 1
0.0032mm | 1
0.0032mm | 1
0.0032mm | 1
0.0032mm | 1
0.0032mm | 1
0.0033mm | 1
0.0033mm | 1
0.0033mm | 4
0.0034mm | 1
0.0036mm | 6
0.0036mm | 1
0.0036mm | 1
0.0037mm | 1
0.0037mm | 1
0.0038mm | 1
0.0038mm | 1
0.0038mm | 1
0.0039mm | 1
0.0039mm | 1
0.0039mm | 1
0.0039mm | 1
0.0039mm | 1
0.0039mm | 1
0.004mm | 1
0.004mm | 1
0.004mm | 1
0.004mm | 1
0.004mm | 1
0.0041mm | 1
0.0041mm | 4
0.0041mm | 1
0.0042mm | 1
0.0042mm | 1
0.0042mm | 1
0.0042mm | 1
0.0043mm | 4
0.0043mm | 1
0.0044mm | 1
0.0044mm | 1
0.0044mm | 1
0.0044mm | 1
0.0045mm | 1
0.0045mm | 1
0.0045mm | 1
0.0045mm | 1
0.0046mm | 1
0.0046mm | 1
0.0047mm | 1
0.0047mm | 1
0.0047mm | 1
0.0047mm | 1
0.0048mm | 1
0.0048mm | 1
0.0048mm | 1
0.0048mm | 4
0.0048mm | 4
0.0048mm | 1
0.0049mm | 1
0.0049mm | 2
0.0049mm | 1
0.0049mm | 1
0.0049mm | 2
0.005mm | 4
0.005mm | 2
0.0051mm | 1
0.0051mm | 1
0.0051mm | 1
0.0051mm | 1
0.0051mm | 1
0.0051mm | 1
0.0052mm | 1
0.0052mm | 1
0.0052mm | 13
0.0052mm | 1
0.0052mm | 1
0.0053mm | 1
0.0053mm | 1
0.0053mm | 1
0.0054mm | 1
0.0054mm | 1
0.0054mm | 1
0.0054mm | 1
0.0054mm | 1
0.0054mm | 1
0.0054mm | 1
0.0054mm | 3
0.0054mm | 1
0.0054mm | 1
0.0054mm | 1
0.0054mm | 1
0.0055mm | 1
0.0055mm | 1
0.0055mm | 4
0.0056mm | 1
0.0056mm | 1
0.0056mm | 1
0.0056mm | 1
0.0056mm | 1
0.0057mm | 1
0.0057mm | 1
0.0057mm | 1
0.0057mm | 1
0.0057mm | 1
0.0058mm | 1
0.0058mm | 12
0.0058mm | 1
0.0058mm | 1
0.0058mm | 1
0.0059mm | 1
0.0059mm | 1
0.0059mm | 1
0.0059mm | 1
0.0059mm | 2
0.0059mm | 1
0.0059mm | 1
0.006mm | 1
0.006mm | 1
0.006mm | 1
0.006mm | 1
0.006mm | 1
0.006mm | 1
0.0061mm | 3
0.0061mm | 1
0.0061mm | 1
0.0061mm | 2
0.0061mm | 1
0.0062mm | 4
0.0062mm | 1
0.0062mm | 1
0.0062mm | 1
0.0062mm | 1
0.0062mm | 1
0.0062mm | 1
0.0062mm | 1
0.0063mm | 1
0.0063mm | 1
0.0064mm | 1
0.0064mm | 1
0.0065mm | 3
0.0065mm | 1
0.0065mm | 1
0.0066mm | 1
0.0067mm | 1
0.0067mm | 1
0.0067mm | 2
0.0067mm | 1
0.0067mm | 1
0.0067mm | 1
0.0067mm | 1
0.0068mm | 1
0.0068mm | 4
0.0068mm | 1
0.0068mm | 1
0.0068mm | 1
0.0068mm | 1
0.0068mm | 1
0.0069mm | 1
0.0069mm | 1
0.0069mm | 1
0.0069mm | 1
0.0069mm | 1
0.007mm | 1
0.007mm | 1
0.007mm | 1
0.0071mm | 1
0.0071mm | 1
0.0071mm | 1
0.0072mm | 1
0.0072mm | 1
0.0073mm | 1
0.0073mm | 1
0.0073mm | 1
0.0073mm | 1
0.0073mm | 1
0.0073mm | 1
0.0074mm | 1
0.0075mm | 2
0.0075mm | 2
0.0075mm | 1
0.0075mm | 1
0.0075mm | 1
0.0075mm | 1
0.0075mm | 2
0.0075mm | 2
0.0076mm | 1
0.0076mm | 1
0.0076mm | 1
0.0076mm | 1
0.0076mm | 1
0.0076mm | 1
0.0076mm | 2
0.0077mm | 1
0.0077mm | 1
0.0077mm | 1
0.0077mm | 1
0.0078mm | 1
0.0078mm | 1
0.0078mm | 1
0.0078mm | 1
0.0079mm | 1
0.0079mm | 1
0.0079mm | 2
0.0079mm | 1
0.008mm | 1
0.008mm | 2
0.008mm | 1
0.008mm | 1
0.008mm | 1
0.008mm | 1
0.008mm | 1
0.008mm | 1
0.008mm | 1
0.0081mm | 1
0.0081mm | 1
0.0081mm | 1
0.0081mm | 1
0.0081mm | 1
0.0081mm | 1
0.0082mm | 2
0.0083mm | 1
0.0083mm | 14
0.0083mm | 1
0.0083mm | 1
0.0083mm | 3
0.0083mm | 1
0.0084mm | 1
0.0084mm | 1
0.0084mm | 4
0.0084mm | 1
0.0085mm | 1
0.0085mm | 1
0.0085mm | 4
0.0085mm | 1
0.0086mm | 1
0.0086mm | 1
0.0086mm | 1
0.0086mm | 1
0.0086mm | 1
0.0086mm | 1
0.0086mm | 1
0.0086mm | 1
0.0086mm | 4
0.0087mm | 1
0.0087mm | 1
0.0087mm | 1
0.0088mm | 1
0.0088mm | 1
0.0088mm | 1
0.0088mm | 1
0.0088mm | 2
0.0089mm | 1
0.0089mm | 1
0.0089mm | 1
0.0089mm | 1
0.0089mm | 1
0.0089mm | 1
0.0089mm | 1
0.009mm | 1
0.009mm | 1
0.009mm | 1
0.009mm | 1
0.0091mm | 1
0.0091mm | 1
0.0091mm | 1
0.0091mm | 1
0.0091mm | 1
0.0092mm | 2
0.0092mm | 1
0.0092mm | 1
0.0092mm | 1
0.0092mm | 1
0.0092mm | 1
0.0093mm | 1
0.0093mm | 1
0.0094mm | 1
0.0094mm | 4
0.0094mm | 1
0.0094mm | 1
0.0094mm | 1
0.0094mm | 1
0.0094mm | 12
0.0094mm | 1
0.0095mm | 1
0.0095mm | 2
0.0096mm | 1
0.0096mm | 1
0.0096mm | 1
0.0097mm | 1
0.0097mm | 1
0.0097mm | 2
0.0097mm | 1
0.0097mm | 1
0.0097mm | 1
0.0097mm | 1
0.0097mm | 2
0.0097mm | 1
0.0097mm | 1
0.0097mm | 1
0.0098mm | 1
0.0098mm | 1
0.0099mm | 1
0.0099mm | 1
0.0099mm | 1
0.0099mm | 1
0.0099mm | 1
0.01mm | 1
0.01mm | 3
0.01mm | 1
0.01mm | 1
0.01mm | 1
0.01mm | 1
0.0101mm | 1
0.0101mm | 1
0.0101mm | 1
0.0102mm | 1
0.0102mm | 2
0.0102mm | 1
0.0102mm | 3
0.0102mm | 4
0.0102mm | 1
0.0102mm | 1
0.0102mm | 1
0.0103mm | 1
0.0103mm | 2
0.0103mm | 1
0.0103mm | 1
0.0103mm | 1
0.0103mm | 1
0.0104mm | 1
0.0104mm | 1
0.0104mm | 1
0.0104mm | 1
0.0104mm | 1
0.0104mm | 1
0.0105mm | 1
0.0105mm | 1
0.0105mm | 17
0.0105mm | 1
0.0105mm | 1
0.0106mm | 1
0.0106mm | 1
0.0106mm | 2
0.0106mm | 1
0.0106mm | 1
0.0107mm | 1
0.0107mm | 1
0.0107mm | 1
0.0107mm | 2
0.0107mm | 1
0.0108mm | 1
0.0108mm | 1
0.0108mm | 1
0.0108mm | 1
0.0108mm | 1
0.0108mm | 1
0.0109mm | 6
0.0109mm | 8
0.0109mm | 2
0.0109mm | 1
0.0109mm | 1
0.0109mm | 1
0.0109mm | 1
0.0109mm | 1
0.0109mm | 1
0.011mm | 1
0.011mm | 1
0.011mm | 1
0.011mm | 1
0.011mm | 1
0.011mm | 1
0.0111mm | 1
0.0111mm | 1
0.0112mm | 1
0.0112mm | 1
0.0112mm | 1
0.0112mm | 1
0.0112mm | 1
0.0112mm | 1
0.0112mm | 1
0.0112mm | 1
0.0112mm | 1
0.0112mm | 1
0.0112mm | 1
0.0112mm | 1
0.0112mm | 1
0.0113mm | 1
0.0113mm | 1
0.0113mm | 1
0.0113mm | 1
0.0113mm | 1
0.0114mm | 1
0.0114mm | 1
0.0115mm | 2
0.0115mm | 1
0.0115mm | 1
0.0115mm | 1
0.0115mm | 1
0.0115mm | 2
0.0115mm | 1
0.0116mm | 1
0.0117mm | 1
0.0117mm | 1
0.0117mm | 1
0.0117mm | 1
0.0118mm | 1
0.0118mm | 2
0.0118mm | 2
0.0118mm | 2
0.0118mm | 1
0.0118mm | 1
0.0118mm | 1
0.0118mm | 1
0.0119mm | 1
0.0119mm | 1
0.0119mm | 1
0.0119mm | 1
0.0119mm | 1
0.0119mm | 1
0.012mm | 1
0.012mm | 1
0.012mm | 2
0.012mm | 1
0.012mm | 1
0.012mm | 1
0.012mm | 6
0.012mm | 1
0.012mm | 2
0.0121mm | 1
0.0121mm | 1
0.0121mm | 1
0.0121mm | 1
0.0121mm | 1
0.0121mm | 1
0.0121mm | 4
0.0121mm | 2
0.0121mm | 1
0.0121mm | 1
0.0122mm | 2
0.0122mm | 1
0.0122mm | 4
0.0122mm | 1
0.0122mm | 2
0.0122mm | 1
0.0122mm | 1
0.0123mm | 2
0.0123mm | 1
0.0123mm | 1
0.0123mm | 1
0.0123mm | 1
0.0123mm | 1
0.0124mm | 1
0.0124mm | 2
0.0124mm | 1
0.0124mm | 1
0.0124mm | 1
0.0124mm | 1
0.0124mm | 1
0.0124mm | 1
0.0125mm | 4
0.0125mm | 1
0.0125mm | 1
0.0125mm | 1
0.0125mm | 1
0.0125mm | 1
0.0125mm | 1
0.0125mm | 1
0.0125mm | 13
0.0126mm | 1
0.0126mm | 1
0.0126mm | 1
0.0127mm | 4
0.0127mm | 1
0.0127mm | 1
0.0127mm | 1
0.0127mm | 1
0.0127mm | 1
0.0127mm | 1
0.0127mm | 1
0.0127mm | 2
0.0127mm | 1
0.0128mm | 1
0.0128mm | 1
0.0128mm | 1
0.0128mm | 1
0.0128mm | 1
0.0128mm | 1
0.0128mm | 1
0.0129mm | 2
0.0129mm | 2
0.013mm | 2
0.013mm | 1
0.013mm | 1
0.013mm | 1
0.013mm | 2
0.013mm | 1
0.013mm | 1
0.013mm | 1
0.013mm | 1
0.0131mm | 1
0.0131mm | 2
0.0131mm | 1
0.0131mm | 1
0.0131mm | 1
0.0131mm | 1
0.0132mm | 8
0.0132mm | 6
0.0132mm | 1
0.0132mm | 2
0.0132mm | 1
0.0132mm | 1
0.0133mm | 1
0.0133mm | 1
0.0133mm | 1
0.0133mm | 1
0.0133mm | 1
0.0134mm | 1
0.0134mm | 1
0.0134mm | 1
0.0134mm | 1
0.0135mm | 1
0.0135mm | 1
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

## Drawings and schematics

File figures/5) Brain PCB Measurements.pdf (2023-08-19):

## SINKING CLOCK Brain PCB Measurements

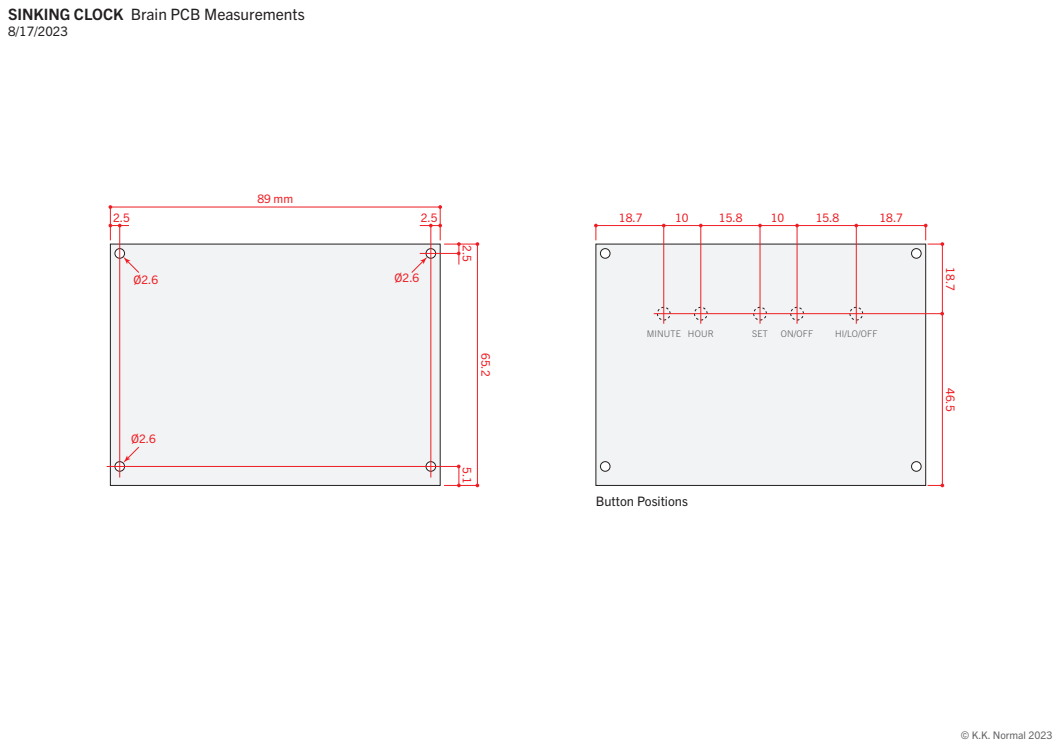
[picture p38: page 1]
© K.K. Normal 2023; MINUTE HOUR; SET ON/OFF; HI/LO/OFF; Button Positions

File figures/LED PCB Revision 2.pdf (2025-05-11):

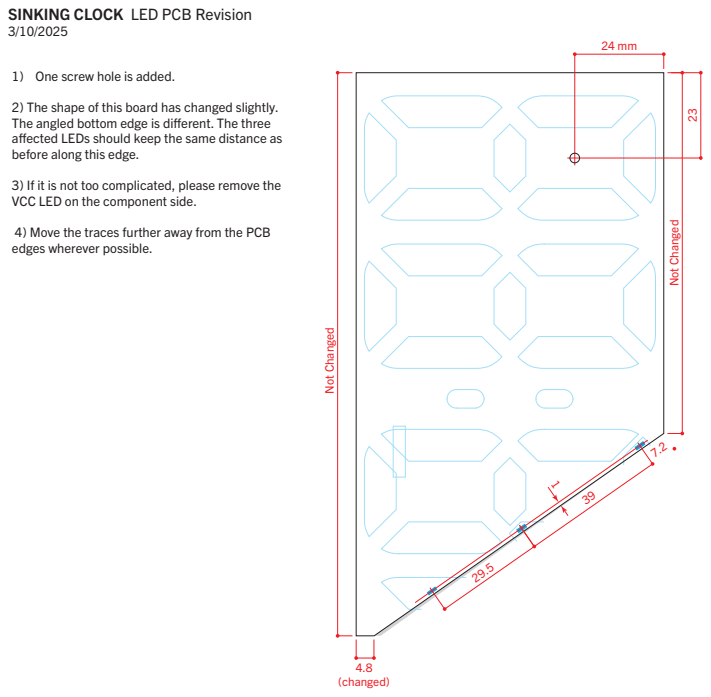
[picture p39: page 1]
Not Changed; 4.8 (changed)

SINKING CLOCK LED PCB Revision

1) One screw hole is added.

2) The shape of this board has changed slightly.
The angled bottom edge is dierent. The three
aected LEDs should keep the same distance as
before along this edge.

3) If it is not too complicated, please remove the
VCC LED on the component side.

4) Move the traces further away from the PCB
edges wherever possible.

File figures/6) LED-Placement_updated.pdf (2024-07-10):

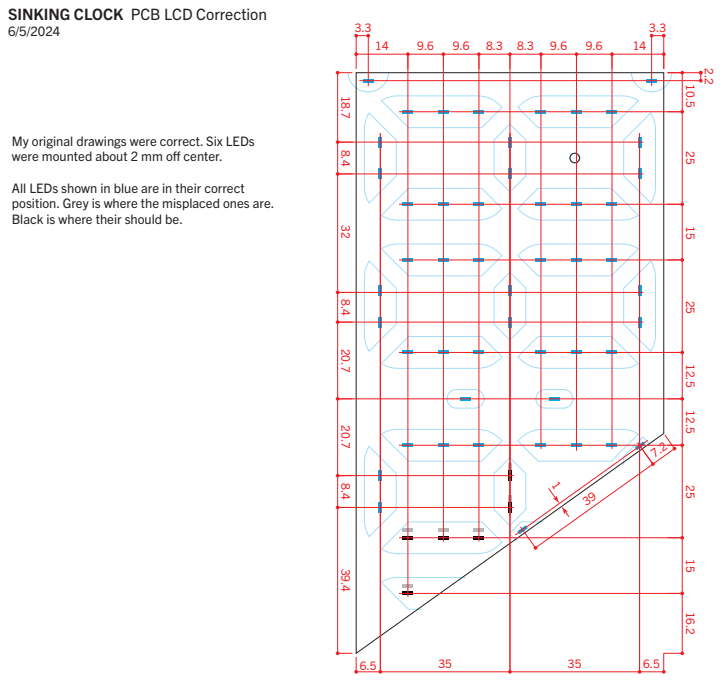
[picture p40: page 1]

SINKING CLOCK PCB LCD Correction

My original drawings were correct. Six LEDs
were mounted about 2 mm o center.

All LEDs shown in blue are in their correct
position. Grey is where the misplaced ones are.
Black is where their should be.

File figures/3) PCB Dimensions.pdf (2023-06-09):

## SINKING CLOCK PCB Dimensions

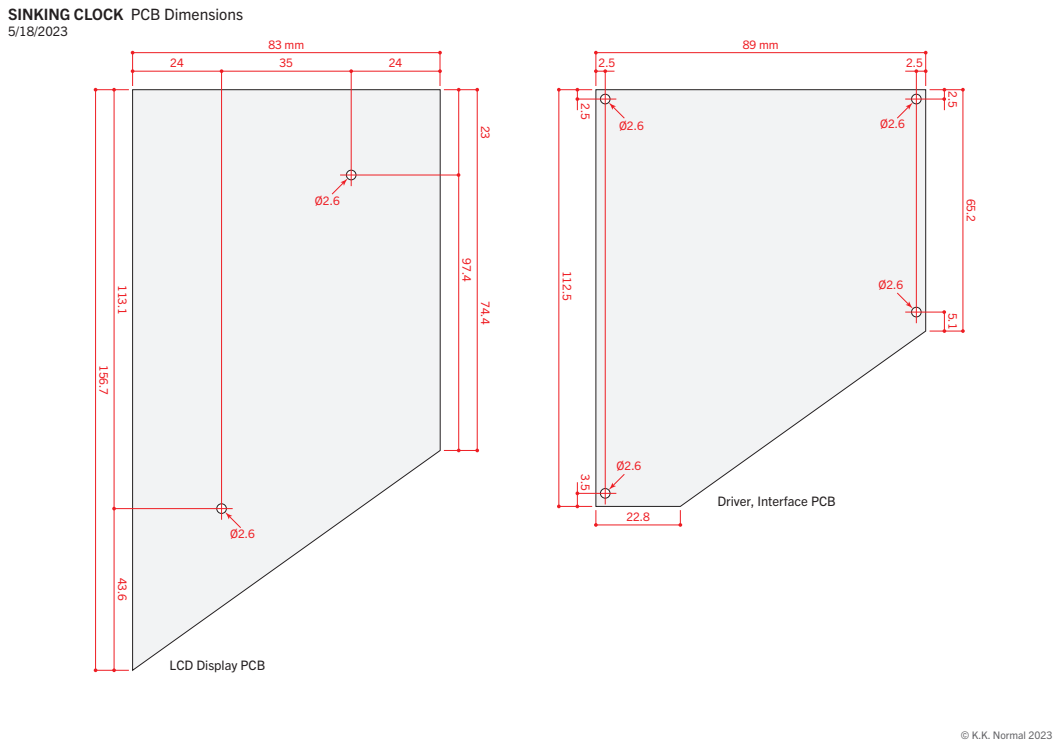
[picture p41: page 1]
© K.K. Normal 2023

Driver, Interface PCB

LCD Display PCB

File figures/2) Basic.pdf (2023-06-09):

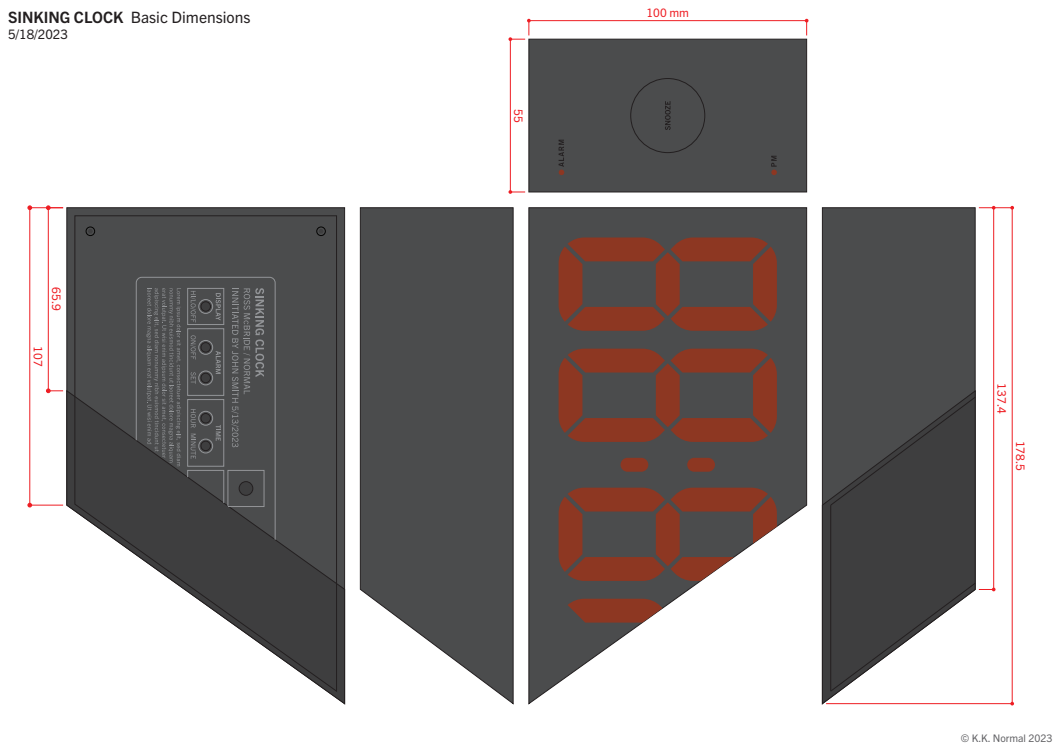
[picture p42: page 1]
© K.K. Normal 2023

SINKING CLOCK Basic Dimensions

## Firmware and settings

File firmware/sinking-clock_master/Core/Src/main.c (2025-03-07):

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
/* Includes ------------------------------------------------------------------*/
#include "main.h"

/* USER CODE BEGIN Includes */

#ifndef SEVSEG_SHIFT_H_
#include "sevSeg_shift.h"
#endif

#ifndef ALARM_H_
#include "alarm.h"
#endif

#ifndef SINKINGCLOCKVARS_H_
#include "sinkingClockVars.h"
#endif

#ifndef AT42QT1070_H_
#include "AT42QT1070.h"
#endif

/* USER CODE END Includes */

I2C_HandleTypeDef hi2c1;

RTC_HandleTypeDef hrtc;

TIM_HandleTypeDef htim1;
TIM_HandleTypeDef htim2;
TIM_HandleTypeDef htim14;
TIM_HandleTypeDef htim16;
TIM_HandleTypeDef htim17;

/* USER CODE BEGIN PV */

/*
 * Timer to be used for PWMing display
 */
TIM_HandleTypeDef *timerPWM = &htim2;

/*
 * Timer to be used for non-blocking delays
 */
TIM_HandleTypeDef *timerDelay = &htim14;

/*
 * Timer to be used for long 10-minute snooze
 */
TIM_HandleTypeDef *timerSnooze = &htim16;

/*
 * Timer to be used to software-PWM alarm LED
 */
TIM_HandleTypeDef *timerAlarmLED_PWM = &htim17;

/*
 * Timer to be used for Buzzer PWM
 */
TIM_HandleTypeDef *timerBuzzer = &htim1;



/*
 * Counts up to timerSnooze_RCR for long snooze delay
 */
uint8_t snoozeCounter = 0;

/*
 * Keeps track of alarm LED software PWM count
 * 0-100
 */
uint8_t alarmLED_PWM_Counter = 0;

/*
 * State bools
 */

// Used to blare alarm if enabled
bool alarmSetMode = false;

/*
 * Used to indicate whether the clock is in a
 * state to sound a snoozed alarm again after 10 minutes.
 * false = regular operation, true = 10-minute snooze period
 */
bool secondSnooze = false;

/*
 * Cap. touch struct
 */
QT1070 capTouch;

/*
 * For PWMing alarm Enable LED
 */
uint8_t threshold = sevSeg_intensityDuty[2];

/* USER CODE END PV */

void SystemClock_Config(void);
static void MX_GPIO_Init(void);
static void MX_RTC_Init(void);
static void MX_I2C1_Init(void);
static void MX_TIM14_Init(void);
static void MX_TIM2_Init(void);
static void MX_TIM16_Init(void);
static void MX_TIM1_Init(void);
static void MX_TIM17_Init(void);
/* USER CODE BEGIN PFP */

/*
 * Call to fetch the current time from the RTC and send to the LED display.
 *
 * @param none
 *
 * @ret HAL status object
 */
HAL_StatusTypeDef updateAndDisplayTime(void);

/*
 * Call to fetch the current alarm from the RTC and send to the LED display.
 *
 * @param none
 *
 * @ret HAL status object
 */
HAL_StatusTypeDef updateAndDisplayAlarm(void);

/*
 * Called on interrupt from display button to toggle 7-segment intensity.
 *
 * @param none
 *
 * @ret HAL status object
 */
HAL_StatusTypeDef displayButtonISR(void);

/*
 * Called on interrupt from alarm enable button to toggle user alarm.
 *
 * @param none
 *
 * @ret HAL status object
 */
HAL_StatusTypeDef alarmEnableISR(void);

/*
 * Called on interrupt from alarm set button to enter alarm set loop.
 *
 * @param none
 *
 * @ret HAL status object
 */
HAL_StatusTypeDef alarmSetISR(void);

/*
 * Called on interrupt from hour and minute set buttons.
 * Contain logic to set user alarm hour or minute.
 *
 * @param none
 *
 * @ret HAL status object
 */
HAL_StatusTypeDef hourSetISR(void);
HAL_StatusTypeDef minuteSetISR(void);

/*
 * Hour and minute incrementing functions for alarm time and current time
 *
 */

void alarmHourInc(void);
void currHourInc(void);
void alarmMinuteInc(void);
void currMinuteInc(void);

/*
 * Enters loop to signal user alarm
 */
void userAlarmBeep(void);

/*
 * Displays non-critical error on debug LED and continues functionality
 */
void dispFault();

/*
 * Displays Critical Error on clock and halts all functionality
 */
void dispFailure();

/*
 * Updates RTC Backup Registers with user alarm time
 */
void updateRTCBackupReg(void);

/* USER CODE END PFP */

/**
  * @brief  The application entry point.
  * @retval int
  */
int main(void)
{
  /* MCU Configuration--------------------------------------------------------*/

  /* Reset of all peripherals, Initializes the Flash interface and the Systick. */
  HAL_Init();

  /* Configure the system clock */
  SystemClock_Config();

  /* Initialize all configured peripherals */
  MX_GPIO_Init();
  MX_RTC_Init();
  MX_I2C1_Init();
  MX_TIM14_Init();
  MX_TIM2_Init();
  MX_TIM16_Init();
  MX_TIM1_Init();
  MX_TIM17_Init();
  /* USER CODE BEGIN 2 */

  // HAL Status handle for error-checking
  HAL_StatusTypeDef halRet = HAL_OK;

  // Start alarm LED software PWM
  HAL_TIM_Base_Start_IT(timerAlarmLED_PWM);

  // Set Smooth Calibration Value
  halRet = HAL_RTCEx_SetSmoothCalib(&hrtc, RTC_SMOOTHCALIB_PERIOD_8SEC,
    							RTC_SMOOTHCALIB_PLUSPULSES_RESET, rtcCalVal);
  if(halRet != HAL_OK) {
	  // Failure to talk to RTC is a hard failure
	  dispFailure();
  }

  // Init the internal RTC alarm time to track the current time
  halRet = initRTCInternalAlarm(&hrtc, &currTime, &currDate);
  if(halRet != HAL_OK) {
  	  // Failure to initialize RTC alarm is a hard failure
  	  dispFailure();
    }

  // Initialize all GPIOs to be used with 7 segment display
    sevSeg_Init(shiftDataPin, shiftDataClockPin, shiftStoreClockPin,
				shiftOutputEnablePin, shiftMCLRPin,
				GPIOPortArray, timerDelay, timerPWM, tim_PWM_CHANNEL);

    // Set to max brightness
    sevSeg_setIntensity(sevSeg_intensityDuty[2]);

	halRet = updateAndDisplayTime();
	if(halRet != HAL_OK) {
	  // Failure to display current time is a hard failure
	  dispFailure();
	}

    /*
     * Initialize capacitive touch sensor
     */

	// Used to separate return initializations into critical and non-critical errors.
	uint8_t initRet = 0;

    initRet = capTouch_Init(&capTouch, &hi2c1, timerDelay,
    						&capTouchResetPort, capTouchResetPin, capTouchChannels);
    if( (initRet == 1) || (initRet == 3) || (initRet == 4)) {

    	/* Critical Errors:
    	 * 1 = Failure to read correct device ID
    	 * 2 = Failure to read Keys
    	 * 3 = Failure to enable keys
    	 */
    	dispFailure();
    }
    else if (initRet == 2) {
    	/*
    	 * Non-critical Errors:
    	 * 2 = Failure to Recalibrate
    	 */
    	dispFault();
    }
    else if(initRet == 0) {
    	// initRet = 0 = all is well
    	__NOP();
    }

    // Set averaging factor
    uint8_t avgFactors_New[7] = {AVGFact, AVGFact, AVGFact, AVGFact, 0, 0, 0};
    halRet = capTouch_SetAveragingFactor(&capTouch, avgFactors_New);

    if(halRet != HAL_OK) {
    	// This is sensitivity-setting and a non-critical error
    	dispFault();
    }

    // Set detection integration factors
    uint8_t detIntFactors_New[7] = {DIFact, DIFact, DIFact, DIFact, DIFact, DIFact, DIFact};
    halRet = capTouch_SetDetectionIntegrator(&capTouch, detIntFactors_New);
    if(halRet != HAL_OK) {
    	// This is sensitivity-setting and a non-critical error
		dispFault();
    }

    userAlarmToggle = false;			//Default to off


    /*
     * If the bootstrap backup register reads 0x00 (never written to,)
     * initialize the alarm time to a default value.
     *
     * Else, initialize to whatever is stored in backup registers.
     */

    if((uint8_t)HAL_RTCEx_BKUPRead(&hrtc, bootstrapBackupReg) == 0) {

    	HAL_RTCEx_BKUPWrite(&hrtc, userAlarmHourBackupReg, 0x01);
    	HAL_RTCEx_BKUPWrite(&hrtc, userAlarmMinuteBackupReg, 0x00);
    	HAL_RTCEx_BKUPWrite(&hrtc, userAlarmTFBackupReg, RTC_HOURFORMAT12_AM);

    	// Write backup register with a non-zero value to signify that it has been initialized before
    	HAL_RTCEx_BKUPWrite(&hrtc, bootstrapBackupReg, 0xFFFFFFFF);

    }

	userAlarmTime.Hours = (uint8_t)HAL_RTCEx_BKUPRead(&hrtc, userAlarmHourBackupReg);
	userAlarmTime.Minutes = (uint8_t)HAL_RTCEx_BKUPRead(&hrtc, userAlarmMinuteBackupReg);
	userAlarmTime.TimeFormat = (uint8_t)HAL_RTCEx_BKUPRead(&hrtc, userAlarmTFBackupReg);

  /* USER CODE END 2 */

  /* Infinite loop */
  /* USER CODE BEGIN WHILE */
  while (1)
  {


  }
    /* USER CODE END WHILE */

}

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
/* USER CODE BEGIN 4 */

/*
 * Pulls updated time from RTC and send new time to user display
 */
HAL_StatusTypeDef updateAndDisplayTime(void) {

	HAL_StatusTypeDef halRet = HAL_OK;

	getRTCTime(&hrtc, &currTime, &currDate);
	sevSeg_updateDigits(&currTime);

	return halRet;

}

/*
 * Sends current user alarm time to user display
 * This doesn't pull from the RTC because the RTC alarm is not being used for that
 */

HAL_StatusTypeDef updateAndDisplayAlarm(void) {

	HAL_StatusTypeDef halRet = HAL_OK;

	sevSeg_updateDigits(&userAlarmTime);

	return halRet;

}

/*
 * Interrupt callback function for RTC interrupt kickback
 * Occurs every minute increment
 *
 * Pulls alarm time from RTC, increments and sets new alarm time, and updates time.
 * Sets off user alarm if the alarm is enabled.
 */
void HAL_RTC_AlarmAEventCallback(RTC_HandleTypeDef *hrtc) {

	  RTC_AlarmTypeDef sAlarm = {0};
	  HAL_RTC_GetAlarm(hrtc, &sAlarm, internalAlarm, RTCTimeFormat);

	  getRTCTime(hrtc, &currTime, &currDate);

	  if(currTime.Minutes > 58) {
		sAlarm.AlarmTime.Minutes = 0;
	  } else {
		sAlarm.AlarmTime.Minutes = currTime.Minutes + 1;
	  }
		while(HAL_RTC_SetAlarm_IT(hrtc, &sAlarm, FORMAT_BIN)!=HAL_OK){

			__NOP();

		}

	  updateAndDisplayTime();

	  // If alarm is enabled and current time matches user alarm time, set off the alarm.
	  if(userAlarmToggle && userAlarmTime.Hours == currTime.Hours
			  && userAlarmTime.Minutes == currTime.Minutes && userAlarmTime.TimeFormat == currTime.TimeFormat) {
		  userAlarmBeep();
	  }


}

/*
 * If user alarm is enabled and the RTC time equals the user alarm time, this function is entered.
 *
 * This function blinks the display LEDs and toggles the beeper until the user
 * disables this beeping through cap. touch or the alarm enable button.
 *
 * Functionality depends on whether or not this is the first or second snooze.
 * 		First Snooze: 10-minute timer is started and alarm
 * 		              is beeped again at the end of this 10 minutes.
 * 		Second Snooze: No timer is started and silencing the alarm silences it for good.
 */
void userAlarmBeep() {

	if (secondSnooze) { 		//If the user has already snoozed once,

			// Stop the timer and
			HAL_TIM_Base_Stop_IT(timerSnooze);

			// Reset count to 0
			// only bits 0 - 15 should be changed.
			timerSnooze->Instance->CNT &= 0xFFFF0000;

			// Reset interrupt status register
			timerSnooze->Instance->SR &= 0xFFFC;

//			// Re-write RCR with 10
//			timerSnooze->Instance->RCR &= 0xFF00;
//			timerSnooze->Instance->RCR |= timerSnooze_RCR;

		}

	HAL_TIM_Base_Stop(timerDelay);
	HAL_TIM_Base_Start(timerDelay);						// Begin timer 16 counting (to 500 ms)
	uint32_t timerVal = __HAL_TIM_GET_COUNTER(timerDelay);	// Get initial timer value to compare to
	bool displayBlink = false;

	/*
	 * Determine whether to toggle high or low brightness
	 */
	uint8_t intenSet;
	if(displayToggle == 0) { 				// If the user has full brightness enabled, toggle full brightness
		intenSet = 2;
	}
	else {									// Else, toggle low brightness
		intenSet = 1;
	}

	do {						// Beep buzzer and blink display until snooze button is pressed

		updateAndDisplayTime();				// Update to current time and display

		if(__HAL_TIM_GET_COUNTER(timerDelay) - timerVal >= (65535 / 2)) {		// Use hardware timer to blink/beep display

			sevSeg_setIntensity(sevSeg_intensityDuty[displayBlink * intenSet]);	// Toggle on/off

			if(!displayBlink) {
				__HAL_TIM_SET_COMPARE(timerBuzzer, tim_BUZZER_CHANNEL, 50);
				HAL_TIM_PWM_Start(timerBuzzer, tim_BUZZER_CHANNEL);
			}
			else {
				HAL_TIM_PWM_Stop(timerBuzzer, tim_BUZZER_CHANNEL);
			}



			timerVal = __HAL_TIM_GET_COUNTER(timerDelay);				// Update timer value

			displayBlink = !displayBlink;							// Toggle display blink counter

		}


		capTouch_readChannels(&capTouch);

	} while(capTouch.keyStat == 0x00 &&
			(HAL_GPIO_ReadPin(alarmEnableButtonPort, alarmEnableButtonPin) != GPIO_PIN_RESET));

	/*
	 * Stop blinking, turn off buzzer, set 50% duty cycle, update time
	 */
	HAL_TIM_Base_Stop(timerDelay);

	HAL_TIM_PWM_Stop(timerBuzzer, tim_BUZZER_CHANNEL);

	updateAndDisplayTime();				// Update to current time and display

	sevSeg_setIntensity(sevSeg_intensityDuty[intenSet]);	// Turn display back on
	if(intenSet == 2) {
		displayToggle = 0;
	}
	else {
		displayToggle = 2;
	}

	// If this is the first snooze,
	if(!secondSnooze) {

		HAL_TIM_PWM_Stop(timerBuzzer, tim_BUZZER_CHANNEL);

		// Start the snooze timer to trigger an interrupt after 10 minutes
		HAL_TIM_Base_Start_IT(timerSnooze);

		// Set flag
		secondSnooze = true;

	} else {

		snoozeCounter = 0;

		// Reset flag
		/*
		 * This must be done here because if it's done
		 * in the top conditional, the secondSnooze is always true;
		 */
		secondSnooze = false;

	}

}

/*
 * General Falling-Edge EXTI Callback function
 *
 * Internal conditional determines which function to call
 * based on which button was pressed.
 */
void HAL_GPIO_EXTI_Falling_Callback(uint16_t GPIO_Pin) {

	HAL_StatusTypeDef halRet;					// Flag for printing interrupt status

	if(GPIO_Pin == displayButtonPin) {
		halRet = displayButtonISR();
		if (halRet != HAL_OK) {
			//printf("Error toggling display.\n\r");
		} else {
			//printf("Display intensity toggled.\n\r");
		}
	}
	else if(GPIO_Pin == alarmEnableButtonPin) {
		halRet = alarmEnableISR();
		if (halRet != HAL_OK) {
			//printf("Error toggling user alarm.\n\r");
		} else {
			//printf("User alarm toggled.\n\r");
		}
	}
	else if(GPIO_Pin == alarmSetButtonPin) {
		halRet = alarmSetISR();
		if (halRet != HAL_OK) {
			//printf("Error setting user alarm.\n\r");
		} else {
			//printf("User alarm set.\n\r");
		}
	}
	else if(GPIO_Pin == hourSetButtonPin) {
		halRet = hourSetISR();
		if (halRet != HAL_OK) {
			//printf("Error incrementing hour.\n\r");
		} else {
			//printf("Hour increment ISR success.\n\r");
		}
	}
	else if(GPIO_Pin == minuteSetButtonPin) {
		halRet = minuteSetISR();
		if (halRet != HAL_OK) {
			//printf("Error incrementing minute.\n\r");
		} else {
			//printf("Minute increment ISR success.\n\r");
		}
	}
	else {			//Code should never reach here, but do nothing if it does.
		__NOP();
	}

}

/*
 * Used for second snooze functionality
 *
 * This is entered at the end of a 10-minute snooze, at
 * which point the timer kicks back an interrupt.
 */
void HAL_TIM_PeriodElapsedCallback(TIM_HandleTypeDef *htim) {



	if(htim == timerSnooze) {

		snoozeCounter++;

		if((secondSnooze == true) && (snoozeCounter == timerSnooze_RCR)) {
			userAlarmBeep();
		}

	}
	else if(htim == timerAlarmLED_PWM) {

		alarmLED_PWM_Counter++;
		if(alarmLED_PWM_Counter == 100)
		{
			alarmLED_PWM_Counter = 0;
		}

		if(!userAlarmToggle) {	// If user alarm not enabled, turn off LED
			HAL_GPIO_WritePin(alarmLEDPort, alarmLEDPin, GPIO_PIN_RESET);
		}
		else {					// If the user alarm is enabled, PWM it


			if(alarmLED_PWM_Counter >= threshold) {
				HAL_GPIO_WritePin(alarmLEDPort, alarmLEDPin, GPIO_PIN_SET);
			}
			else {
				HAL_GPIO_WritePin(alarmLEDPort, alarmLEDPin, GPIO_PIN_RESET);
			}

		}

	}

}

/*
 * Toggles through user time display brightness settings
 */
HAL_StatusTypeDef displayButtonISR(void) {

	//printf("Entered display toggle ISR\n\r");
	HAL_StatusTypeDef halRet = HAL_OK;

	updateAndDisplayTime();

	sevSeg_setIntensity(sevSeg_intensityDuty[displayToggle]);		//Turn display to proper duty cycle

	if(displayToggle >= 2) {			// Increment display toggle or reset back down to 0;
		displayToggle = 0;
	} else {
		displayToggle++;
	}

	// For alarm enable LED
	switch(displayToggle) {

		case 0:			// Full brightness
			threshold = sevSeg_intensityDuty[2];
		break;
		case 1:			// No Brightness. But keep it low brightness.
			threshold = sevSeg_intensityDuty[1];
		break;
		case 2:			// low Brightness
			threshold = sevSeg_intensityDuty[1];
		break;

		default:
			__NOP();
		break;

	}

	return halRet;				// Return HAL status

}

/*
 * Toggles user alarm enable bool and alarm enable LED.
 */
HAL_StatusTypeDef alarmEnableISR(void) {

	//printf("Entered alarm toggle ISR\n\r");
	HAL_StatusTypeDef halRet = HAL_OK;

	userAlarmToggle = !userAlarmToggle;

	/*
	 * Reset snooze time
	 */
	secondSnooze = false;
	snoozeCounter = 0;

	HAL_TIM_Base_Stop_IT(timerSnooze);					// Stop snooze timer in case it is going
	timerSnooze->Instance->CNT &= 0xFFFF0000;
	timerSnooze->Instance->SR &= 0xFFFC;

	return halRet;

}

/*
 * Delays for 3 seconds, checks if alarm set button is still pressed.
 * If it is, allow user to set the new alarm time
 * and blink display to indicate this
 *
 */
HAL_StatusTypeDef alarmSetISR(void) {

	HAL_StatusTypeDef halRet = HAL_OK;


	/*
	 * Wait for 3 seconds to see if alarm set button is still pressed
	 */

	// Delay for 3 * 1s intervals
	for(uint8_t i = 0; i < 3; i++) {

		HAL_TIM_Base_Stop(timerDelay);
		timerDelay->Instance->CNT = 0;						// Reset timer base
		HAL_TIM_Base_Start(timerDelay);						// Begin timer 16 counting (to 1 s)
	//	timerVal = __HAL_TIM_GET_COUNTER(timerDelay);	// Get initial timer value to compare to

		do {

		} while(__HAL_TIM_GET_COUNTER(timerDelay) < (65535));
	}

	// If button is still pressed, we are in alarm set mode.
	if(HAL_GPIO_ReadPin(alarmSetButtonPort, alarmSetButtonPin) == GPIO_PIN_RESET) {
		alarmSetMode = true;
	}

	/*
	 * Then, if we are in alarm set mode, go through the
	 * alarm set process until the button is pressed again
	 */


	// Reset Timer
	HAL_TIM_Base_Stop(timerDelay);
	timerDelay->Instance->CNT = 0;
	HAL_TIM_Base_Start(timerDelay);
	uint16_t timerVal = __HAL_TIM_GET_COUNTER(timerDelay);	// Get initial timer value to compare to

	bool alarmSetButtonReset = false;

	if(alarmSetMode) {

		// If we were in second snooze mode, kill it.
		secondSnooze = false;
		snoozeCounter = 0;

		// Stop snooze timer in case it is going
		HAL_TIM_Base_Stop_IT(timerSnooze);
		timerSnooze->Instance->CNT &= 0xFFFF0000;
		timerSnooze->Instance->SR &= 0xFFFC;

		bool displayBlink = false;

		/*
		 * Determine whether to toggle high or low brightness
		 */
		uint8_t intenSet;
		if(displayToggle == 0) { 				// If the user has full brightness enabled, toggle full btightness
			intenSet = 2;
		}
		else {									// Else, toggle low brightness
			intenSet = 1;
		}

		do {											// while the alarm set button is not held down, blink display.

			// Check to make sure the user has released the set button from the initial hold
			if(HAL_GPIO_ReadPin(alarmSetButtonPort, alarmSetButtonPin) == GPIO_PIN_SET) {
				alarmSetButtonReset = true;
			}

			updateAndDisplayAlarm();

			if(__HAL_TIM_GET_COUNTER(timerDelay) - timerVal >= (65536 / 2)) {

				sevSeg_setIntensity(sevSeg_intensityDuty[displayBlink * intenSet]);		// Initialize to whatever duty cycle

				timerVal = __HAL_TIM_GET_COUNTER(timerDelay);
				displayBlink = !displayBlink;

			}

		}while((HAL_GPIO_ReadPin(alarmSetButtonPort, alarmSetButtonPin) != GPIO_PIN_RESET)
				|| !alarmSetButtonReset);

		sevSeg_setIntensity(sevSeg_intensityDuty[intenSet]);			// Turn display back on
		if(intenSet == 2) {
			displayToggle = 0;
		}
		else {
			displayToggle = 2;
		}


		HAL_TIM_Base_Stop(timerDelay);

		updateAndDisplayTime();

	}

	alarmSetMode = false;		// We have exited alarm set mode

	//printf("Current time back to %u:%u:%u.\n\r", currTime.Hours, currTime.Minutes, currTime.Seconds);

	return halRet;

}

/*
 * Increment either user alarm hour value or RTC hour value
 */
HAL_StatusTypeDef hourSetISR(void) {


	HAL_StatusTypeDef halRet = HAL_OK;

	if(alarmSetMode) {	// If the clock is in alarm set mode, change user alarm time hour

		alarmHourInc();

	}
	else {									// Otherwise, change current time hour.

		currHourInc();

		HAL_RTC_SetTime(&hrtc, &currTime, RTCTimeFormat);


		updateAndDisplayTime();

		getRTCTime(&hrtc, &currTime, &currDate);

		//printf("Current time hour incremented to %u:%u:%u.\n\r", currTime.Hours,
				//currTime.Minutes, currTime.Seconds);
	}

	return halRet;

}

/*
 * Increment either user alarm minute value or RTC minute value
 */
HAL_StatusTypeDef minuteSetISR(void) {


	HAL_StatusTypeDef halRet = HAL_OK;

	if(alarmSetMode) {	// If the clock is in alarm set mode, change user alarm time hour

		alarmMinuteInc();

	}
	else {									// Otherwise, change current time hour.

		currMinuteInc();

		HAL_RTC_SetTime(&hrtc, &currTime, RTCTimeFormat);

		/*
		 * Change internal RTC alarm to keep it triggering
		 */

		RTC_AlarmTypeDef sAlarm = {0};
		HAL_RTC_GetAlarm(&hrtc, &sAlarm, internalAlarm, RTCTimeFormat);

		getRTCTime(&hrtc, &currTime, &currDate);

		if(currTime.Minutes > 58) {
			sAlarm.AlarmTime.Minutes = 0;
		} else {
			sAlarm.AlarmTime.Minutes = currTime.Minutes + 1;
		}
		while(HAL_RTC_SetAlarm_IT(&hrtc, &sAlarm, FORMAT_BIN)!=HAL_OK){}


		updateAndDisplayTime();

		getRTCTime(&hrtc, &currTime, &currDate);

		//printf("Current time minute incremented to %u:%u:%u.\n\r", currTime.Hours,
				//currTime.Minutes, currTime.Seconds);
	}


	return halRet;
}

/*
 * Increment user alarm time hour
 */
void alarmHourInc(void) {

	if(userAlarmTime.Hours >= 12) {
		userAlarmTime.Hours = 1;
	}
	else if(userAlarmTime.Hours == 11) {
		if(userAlarmTime.TimeFormat == RTC_HOURFORMAT12_AM) {
			userAlarmTime.TimeFormat = RTC_HOURFORMAT12_PM;
		}
		else {
			userAlarmTime.TimeFormat = RTC_HOURFORMAT12_AM;
		}
		userAlarmTime.Hours = 12;
	}
	else if(userAlarmTime.Hours < 11) {
		userAlarmTime.Hours = userAlarmTime.Hours + 1;
	}
	else {
		__NOP();
	}

	// Update RTC backup registers with new user alarm time
	updateRTCBackupReg();

}

/*
 * Increment current time hour
 */
void currHourInc(void) {

	getRTCTime(&hrtc, &currTime, &currDate);

	if(currTime.Hours >= 12) {
		currTime.Hours = 1;
	}
	else if(currTime.Hours == 11) {
		if(currTime.TimeFormat == RTC_HOURFORMAT12_AM) {
			currTime.TimeFormat = RTC_HOURFORMAT12_PM;
		}
		else {
			currTime.TimeFormat = RTC_HOURFORMAT12_AM;
		}
		currTime.Hours = 12;
	}
	else if(userAlarmTime.Hours < 11) {
		currTime.Hours = currTime.Hours + 1;
	}
	else {
		__NOP();
	}

	// Reset seconds
	currTime.Seconds = 0;
	currTime.SecondFraction = 0;

}
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

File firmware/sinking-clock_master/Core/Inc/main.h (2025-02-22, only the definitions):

#define DEBUG_LED_Pin GPIO_PIN_0
#define DEBUG_LED_GPIO_Port GPIOA
#define SHIFT_DATA_IN_Pin GPIO_PIN_9
#define SHIFT_DATA_IN_GPIO_Port GPIOA
#define SHIFT_OUTPUT_EN_PWM_Pin GPIO_PIN_6
#define SHIFT_OUTPUT_EN_PWM_GPIO_Port GPIOC
#define SHIFT_STORE_CLK_Pin GPIO_PIN_7
#define SHIFT_STORE_CLK_GPIO_Port GPIOC
#define SHIFT_DATA_CLK_Pin GPIO_PIN_10
#define SHIFT_DATA_CLK_GPIO_Port GPIOA
#define SHIFT_MCLR_Pin GPIO_PIN_11
#define SHIFT_MCLR_GPIO_Port GPIOA
#define ALARM_LED_Pin GPIO_PIN_12
#define ALARM_LED_GPIO_Port GPIOA
#define ALARM_SET_BUTTON_Pin GPIO_PIN_15
#define ALARM_SET_BUTTON_GPIO_Port GPIOA
#define ALARM_SET_BUTTON_EXTI_IRQn EXTI4_15_IRQn
#define HOUR_SET_BUTTON_Pin GPIO_PIN_0
#define HOUR_SET_BUTTON_GPIO_Port GPIOD
#define HOUR_SET_BUTTON_EXTI_IRQn EXTI0_1_IRQn
#define MINUTE_SET_BUTTON_Pin GPIO_PIN_1
#define MINUTE_SET_BUTTON_GPIO_Port GPIOD
#define MINUTE_SET_BUTTON_EXTI_IRQn EXTI0_1_IRQn
#define ALARM_EN_BUTTON_Pin GPIO_PIN_2
#define ALARM_EN_BUTTON_GPIO_Port GPIOD
#define ALARM_EN_BUTTON_EXTI_IRQn EXTI2_3_IRQn
#define DISPLAY_BUTTON_Pin GPIO_PIN_3
#define DISPLAY_BUTTON_GPIO_Port GPIOD
#define DISPLAY_BUTTON_EXTI_IRQn EXTI2_3_IRQn
#define CTOUCH_RST_Pin GPIO_PIN_8
#define CTOUCH_RST_GPIO_Port GPIOB

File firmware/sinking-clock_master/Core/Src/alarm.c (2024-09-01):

/*
 * alarm.c
 *
 *  Created on: Jul 5, 2023
 *      Author: marka
 */

#include "../Inc/alarm.h"


HAL_StatusTypeDef initRTCInternalAlarm(RTC_HandleTypeDef *hrtc, RTC_TimeTypeDef *currTime, RTC_DateTypeDef *currDate) {

	HAL_StatusTypeDef halRet = HAL_OK;

	RTC_AlarmTypeDef internalAlarm_init = {0};
	internalAlarm_init.AlarmTime.Hours = currTime->Hours;
	internalAlarm_init.AlarmTime.Minutes = currTime->Minutes + 1;
	internalAlarm_init.AlarmTime.Seconds = currTime->Seconds;
	internalAlarm_init.AlarmTime.SubSeconds = currTime->SubSeconds;
	internalAlarm_init.AlarmTime.TimeFormat = currTime->TimeFormat;
	internalAlarm_init.AlarmTime.TimeFormat = currTime->TimeFormat;
	internalAlarm_init.AlarmTime.DayLightSaving = RTC_DAYLIGHTSAVING_NONE;
	internalAlarm_init.AlarmTime.StoreOperation = RTC_STOREOPERATION_RESET;
	internalAlarm_init.AlarmMask = RTC_ALARMMASK_DATEWEEKDAY|RTC_ALARMMASK_HOURS
								  |RTC_ALARMMASK_SECONDS;
	internalAlarm_init.AlarmSubSecondMask = RTC_ALARMSUBSECONDMASK_ALL;
	internalAlarm_init.AlarmDateWeekDaySel = RTC_ALARMDATEWEEKDAYSEL_DATE;
	internalAlarm_init.AlarmDateWeekDay = 0x1;
	internalAlarm_init.Alarm = internalAlarm;

	halRet = HAL_RTC_SetAlarm_IT(hrtc, &internalAlarm_init, RTCTimeFormat);
	if(halRet != HAL_OK)
		return halRet;

	RTC_AlarmTypeDef internalAlarm_initTest;
	halRet = HAL_RTC_GetAlarm(hrtc, &internalAlarm_initTest, internalAlarm, RTCTimeFormat);
	return halRet;

}

void getRTCTime(RTC_HandleTypeDef *hrtc, RTC_TimeTypeDef *currTime, RTC_DateTypeDef *currDate) {

	// Store both current time and current date in time and date pointers.
	HAL_RTC_GetTime(hrtc, currTime, RTCTimeFormat);
	HAL_RTC_GetDate(hrtc, currDate, RTCTimeFormat);

}

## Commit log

2023-05-28 Added first PR BOM items. Still need 7-seg things.
    [BOM.xlsx, sinking-clock-BOM-v1.xlsx]
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2023-06-14 Serial terminal sort of works. What the hell?
    [sinking-clock-BOM-v1.xlsx]
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2023-06-17 7 seg I2C init driver written. Gets stuck in TX function calls - not receiving acknowledge bits?
    [main.c, sinking-clock_testing.ioc]
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2023-06-18 Must figure out intensity levels - drive with MOSFET? Also, the RTC LED is getting stuck, which I assume comes from HAL delay --> use hardware timer.
    [main.c]
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2023-06-27 Also - minute increment has problems with the transition from hour 12 to hour 1.
    [main.c]
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2023-06-28 Add PM LED to update time. Still must fix hour change issue.
    [main.c]
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2023-07-06 Something is very weird in software - going to hour 13 and making jumps of multiple minutes.
    [sinking-clock-BOM-v2.xlsx]
2023-07-06 Add/fix user alarm blink loop
    [main.c]
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2023-07-06 Alarm B is not working - hour/minute set functions needed set interrupt functions
    [alarm.c, main.c, sinking-clock_master_NUCLEO.ioc]
2023-07-06 The minutes are too long...a stopwatch shows that they are about 1:02 long.
    [main.c]
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2023-07-09 Things keep getting worse and more problems arise.
    [main.c, main.h, sinking-clock_master_NUCLEO.ioc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]
2023-07-09 AM/PM LED now turns off with display. Display intensity buffer is reversed for clever logic simplification.
    [main.c, sinkingClockVars.h]
2023-07-11 Add LED PCB project and partially-populated PcbLib and SchLib
    [sinking-clock.PcbLib, sinking-clock.SchLib, sinking-clock_LED-PCB.PrjPcb]
2023-07-11 Fix capacitor 3D model
    [sinking-clock.PcbLib]
2023-07-12 Potentially solved LED driving problem. We'll see.
    [sinking-clock-BOM-v2.xlsx]
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2023-07-13 Add some PCB work. Lots of unfinished nets.
    [LED-PCB_DIG0.SchDoc, LED-PCB_Master.SchDoc, sinking-clock-BOM-v2.xlsx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]
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2023-07-13 Almost finish digit 0 schematic - need series resistance values.
    [LED-PCB_DIG0.SchDoc, LED-PCB_Master.SchDoc]
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2023-07-14 Add to main schematic - need segemtn driver and off-board connections/ports. Also - verify that I do not need to talk to cap. touch through I2C.
    [LED-PCB_Master.SchDoc, sinking-clock-BOM-v2.xlsx, sinking-clock.SchLib]
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2023-07-15 Redesign of segement driving using shift register
    [LED-PCB_DIG0.SchDoc, LED-PCB_Master.SchDoc, sinking-clock.PcbLib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]
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2023-07-15 Digit 2 schematic completed - digit 1 child sheet is apparently missing.
    [LED-PCB_DIG2.SchDoc, LED-PCB_Master.SchDoc]
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2023-07-16 Add digits routed - need to route connector and Power, as well as pour ground plane
    [sinking-clock_LED-PCB.PcbDoc]
2023-07-16 Finish routing shift register lines for 2 digits - need to do other 2.
    [LED-PCB_Master.SchDoc, sinking-clock_LED-PCB.PcbDoc, sinking-clock_LED-PCB.PrjPcb]
2023-07-17 Routing complete on LED PCB. Looking at DRC errors.
    [sinking-clock_Brain-PCB.PrjPcb, sinking-clock_LED-PCB.PcbDoc]
2023-07-17 Update resistor array footprint silkscreen. Need to check footprint.
    [LED-PCB_DIG0.SchDoc, LED-PCB_DIG1.SchDoc, LED-PCB_DIG2.SchDoc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]
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2023-07-18 Big parameter mods to BOM and to libraries. Forcing overwrite of STM32.
    [LED-PCB_DIG0.SchDoc, LED-PCB_DIG1.SchDoc, LED-PCB_DIG2.SchDoc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]
2023-07-18 BOM changes are complete. Test points need to be finally placed/routed, and schem. parameters updated.
    [LED-PCB_DIG3.SchDoc, sinking-clock-BOM-v2.xlsx, sinking-clock_LED-PCB.PcbDoc]
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2023-07-18 PN parameters added to components. Resistor values adjusted.
    [LED-PCB_DIG0.SchDoc, LED-PCB_DIG1.SchDoc, LED-PCB_DIG2.SchDoc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]
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2023-07-18 Add ZAMM to board. May have to remove some inner thin lines. Looks awesome.
    [sinking-clock_LED-PCB.PcbDoc]
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2023-07-19 LEDs moved to align with drawing. Export 3D models.
    [LED-PCB_Master.SchDoc, Sinking Clock.stp, sinking-clock.PcbLib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]
2023-07-19 PCB has been checked against 3D clock model and mods have been made. I believe that everything is correct.
    [sinking-clock_LED-PCB.PrjPcb]
2023-07-19 Add ZAMM graphic. Add PCB connector to BOM.
    [ZAMM.dxf, sinking-clock-BOM-v2.xlsx]
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2023-07-20 Generated gerbers, BOM, PNP and modded to comply with PCBWay's specs
    [BOM-sinking-clock_LED-PCB_Mk-1_modded_v1.xlsx, sinking-clock.PcbLib, sinking-clock_LED-PCB.PrjPcb]
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2023-07-23 Move BOMs to folder, add PCB connectors and LDO
    [Brain-PCB_Master.SchDoc, sinking-clock-BOM-v2.xlsx, sinking-clock.PcbLib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]
2023-07-24 Change pinouts for ease of routing and add to IOC file
    [Brain-PCB_Master.SchDoc, LED-PCB_Master.SchDoc, sinking-clock_Brain-PCB.PrjPcb]
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2023-07-24 Add buzzer component
    [sinking-clock-BOM-v3.xlsx, sinking-clock.PcbLib, sinking-clock.SchLib]
2023-07-24 Add buzzer, net colors, rearrage schematic. Cap touch GPIOs on STM32 may need changed.
    [Brain-PCB_Master.SchDoc, sinking-clock_Brain-PCB.PrjPcb]
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2023-07-26 Add vars to .h file for sinking clock main file. Figuring out timer to set intensity and not interfere with timer 16 will be difficult.
    [main.c, sinkingClockVars.h]
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2023-07-30 File structure for website. Add test points to brain PCB schematic
    [Brain-PCB_Master.SchDoc]
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2023-08-01 Add parameter changes to library, parameter instances to schematic doc, and outjob file
    [Brain-PCB_Master.SchDoc, sinking-clock-BOM-v3.xlsx, sinking-clock.SchLib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]
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2023-08-20 Add draftsman document of assembly drawings and update things for assembly on OutJob
    [Brain-PCB_Master.SchDoc, sinking-clock.PcbLib, sinking-clock_Brain-PCB.PcbDoc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]
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2023-08-20 Add I2C ability to cap. touch sensor. All manufacturing data updated accordingly.
    [Brain-PCB_Master.SchDoc, sinking-clock_Brain-PCB.PcbDoc, sinking-clock_Brain-PCB.PrjPcb]
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2023-08-20 BOM update with non-inverted polarity cable, add I2C to new pinout
    [sinking-clock-BOM-v3.xlsx]
2023-08-21 Back to basics testing shift registers. Timer on output enable pin posed problems to be cautious of. Segment 1C now works, but 2F is broken.
    [sinking-clock_Brain-PCB.PrjPcb]
2023-08-22 Got numbers displayed on 7-seg from NUCLEO master project. Something is wrong with the shift data pin assignment, so it's hard-coded in sevSeg_shift.c right now.
    [main.c, main.h, sevSeg_shift.c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]
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2023-08-23 PWM on output EN seems to work in main Nucleo project. Must replace HAL delay in itit with timer.
    [main.c, main.h, sevSeg_shift.c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]
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2023-08-23 Fix error in digit 3 mapping.
    [main.c, main.h, sevSeg_shift.c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]
2023-08-24 Fix blinking in loop problem
    [main.c]
2023-08-24 Fix alarm enable blinking loop
    [main.c]
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2023-09-23 Add series resistances to all FETs. AM/PM LED now controlled by shift register for PWM.
    [LED-PCB_DIG0.SchDoc, LED-PCB_DIG1.SchDoc, LED-PCB_DIG2.SchDoc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]
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2023-10-14 BOM is almost done. Altium needs to separate some groupings in the BOM and some MFRs need added. After that, CPL and fabrication generation.
    [LED-PCB_DIG0.SchDoc, LED-PCB_DIG1.SchDoc, LED-PCB_DIG2.SchDoc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]
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2023-11-11 It works! Mk. II LED PCB. Sinking clock testing project modified with LED test suite.
    [sinking-clock_LED-PCB.PrjPcb]
2024-01-01 New master with correct debug config. Still need to enable/configure RTC and set LSE clock source
    [sinking-clock-BOM-v3.xlsx, sinking-clock.PcbLib]
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2024-01-01 Mk. II Brain PCB almost done - check RTC config in STM Cub IDE
    [Brain-PCB_Master.SchDoc]
2024-01-02 Add RTC CAL TP and remove routing crystal over split ground plane
    [Brain-PCB_Master.SchDoc, sinking-clock_Brain-PCB.PrjPcb]
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2024-01-03 Add new cap. touch sensor circuit. Touchpads still need a footprint of some sort
    [Brain-PCB_Master.SchDoc, sinking-clock.PcbLib, sinking-clock.SchLib]
2024-01-03 Committing now - trying out rigid-flex
    [Brain-PCB_Master.SchDoc, sinking-clock_Brain-PCB.PrjPcb]
2024-01-03 Brain pcb project is purely rigid right now - create test project for rigid-flex quote
    [Brain-PCB_Master_RigFlex-test.SchDoc, sinking-clock.SchLib, sinking-clock_Brain-PCB_RigFlex-testPrjPcb.PrjPcb]
2024-01-03 Replace cap. touch with new IC - no rigid-flex yet
    [Brain-PCB_Master.SchDoc]
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2024-01-17 Flex PCB almost done.
    [sinking-clock_Brain-PCB.PrjPcb, sinking-clock_Flex-PCB.PcbDoc, sinking-clock_Flex-PCB.PrjPcb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]
2024-01-21 Finish Flex Mk. I
    [sinking-clock_Flex-PCB.PcbDoc, sinking-clock_Flex-PCB.step]
2024-01-22 Submitted orders for Brain PCB Mk. II and Flex PCB Mk. I
    [Brain-PCB_Master.SchDoc, sinking-clock.SchLib, sinking-clock_Brain-PCB.PrjPcb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]
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2024-05-03 Create a Mk. III Brain PCB to swap a couple of pesky interrupt pins
    [alarm.c, main.c, main.h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]
2024-05-03 AM/PM thing fixed, ready to merge
    [main.c]
2024-05-05 Written basic driver. Compilation error in project due to multiple definitions?
    [AT42QT1070.c, main.c]
2024-05-05 Fixed error by changing 'const uint8_t' address map to '#define'
    [AT42QT1070.c, main.c]
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2024-05-05 Readings of channel averages and such seems to be correct, unsure why key status register returns unexpected value
    [AT42QT1070.c, main.c, sevSeg_shift.c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]
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2024-05-09 Trying to test the Change Averageing Factor function. For some reason, the I2C device starts throwing errors and the Hof timer is much slower.
    [AT42QT1070.c, main.c]
2024-05-09 Timer problem seems to fix by restarting. New enableKeys() function using SetAveragingFactor() function ready to test.
    [AT42QT1070.c, main.c]
2024-05-10 Fix HOF timer error thing. Also, I'm using 0x04 on all detection integrators and it seems to work nicely.
    [AT42QT1070.c, main.c, sevSeg_shift.c]
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2024-05-14 RTC Alarm callback issue fixed. Must figure out VBAT. Working on flashing an error message right now.
    [alarm.c, main.c]
2024-05-15 Mk. III of LED PCB complete, except perhaps replacing the connector with one that clasps. We'll see.
    [LED-PCB_Master.SchDoc, sinking-clock.PcbLib, sinking-clock.SchLib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]
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2024-05-16 Cap. touch seems to sometimes throw HAL errors. May drop clock speed.
    [AT42QT1070.c, main.c]
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2024-05-16 Forcing a cap. touch reset might do the trick
    [main.c, main.h, sinking-clock_master.ioc]
2024-05-17 Refactor cap touch to hardware reset and use more struct things
    [AT42QT1070.c, main.c]
2024-05-17 Cap. touch works again. It's a hardware issue :(
    [main.c]
2024-05-20 Flex PCB Mk. II ordered, Brain PCB Mk. III complete (minus 512 Hz pin and accurate capacitors
    [Brain-PCB_Master.SchDoc, sinking-clock.PcbLib, sinking-clock_Flex-PCB.PcbDoc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]
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2024-05-23 Now the time doesn't increment when it's changed
    [AT42QT1070.c, main.c, sinkingClockVars.h]
2024-05-23 Amidst new flex PCB
    [sinking-clock_Flex-PCB.PcbDoc]
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2024-05-26 Minute increment seems to be working now. Need to do hour logic and reset seconds on minute increment
    [main.c]
2024-05-26 Resetting seconds seems to work great
    [main.c]
2024-05-27 The RTC pulls from the VBAT registers, but any getRTCTime call resets it back to 1:00
    [main.c]
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2024-06-16 Move media around, add cable asm. Going to branch off to try using timer 16 to do 10-minute snooze.
    [ZAMM.dxf]
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2024-06-17 Strange behavior. Sometimes the delay between is correct, sometimes not.
    [main.c]
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2024-08-26 Made changes to Brain and LED PCBs. About to work on firmware revisions.
    [Brain-PCB_Master.SchDoc, LED-PCB_Master.SchDoc, sinking-clock_LED-PCB.PrjPcb]
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2024-09-01 Increasing robustness - adding code to separate into critical and non-critical errors and trying initialization steps multiple times.
    [AT42QT1070.c, alarm.c, main.c]
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2024-11-02 Mk. VI of LED and Mk. IV of Brain PCBs done. Manufacturing files not yet generated.
    [LED-PCB_DIG3.SchDoc]
2024-11-05 Added stiffener to Mk. III Flex PCB, submitted for review.
    [sinking-clock_Flex-PCB.PcbDoc, sinking-clock_Flex-PCB.PrjPcb]
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2024-11-07 Fix a second snooze/reset alarm time interference. Fix brightness init bug.
    [main.c, sevSeg_shift.c, sinkingClockVars.h]
2024-11-08 Add rememberance of intensity setting when blinking display. Add more snooze bool and counter resetting.
    [main.c]
2024-11-08 Wait - IDK what the deal is with 10min-snooze-fix
    [main.c]
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2024-11-08 FIXED: alarm interrupts not being entered.
    [main.c]
2024-11-17 Add timer reset to alarm enable/disable. I think this should fix variable snooze time issues.
    [main.c]
2024-11-17 Going to change the buzzer pin to a PWM output
    [main.c]
2024-11-17 Testing PWM on buzzer
    [main.c, main.h, sinking-clock_master.ioc]
2024-12-07 Damn it. Stopping the buzzer didn't propagate. Need to re-program.
    [main.c]
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2025-02-22 Fixed discrepancies between IOC file and main.c
    [main.c, sinking-clock_master.ioc]
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

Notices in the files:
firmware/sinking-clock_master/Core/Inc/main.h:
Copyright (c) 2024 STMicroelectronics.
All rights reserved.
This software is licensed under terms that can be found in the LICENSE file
